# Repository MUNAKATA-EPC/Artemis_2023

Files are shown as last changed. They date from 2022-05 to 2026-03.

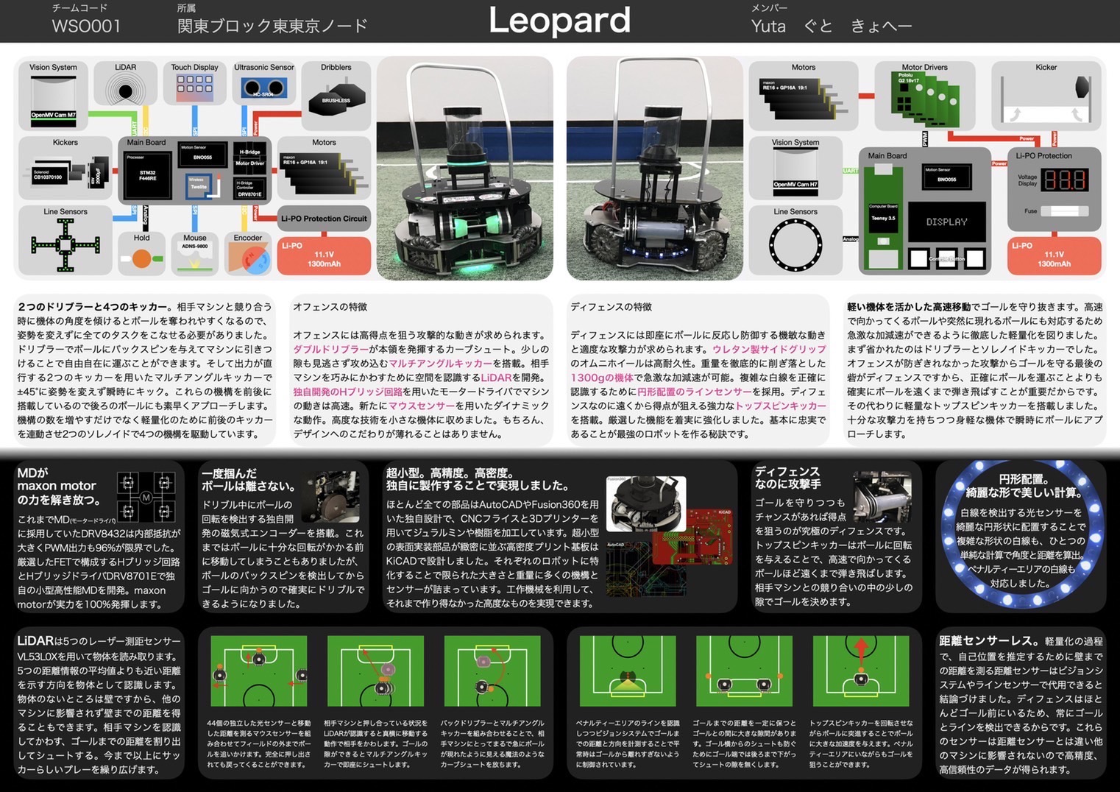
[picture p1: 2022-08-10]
Reference_Material/Presentation/leopard presentation.jpg

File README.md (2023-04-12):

# 宗中アルテミス
2023シーズンの宗中アルテミスのデータをまとめたリポジトリです。詳細はWikiの方で。

このReadmeでは軽く自チームの紹介がてら結果報告やロボット概要をまとめておきます。
詳しくはいつか出る全国大会の記事で。

## 今年の結果
>  福岡ノード 優勝  
>  九州ブロック 優勝 / 優秀プレゼンテーション賞受賞  
>  ジャパンオープン 最終結果 18位 / 優秀プレゼンテーション賞受賞  
> その他オープン大会優勝 etc...  

## 全国機ロボット概要
* メインマイコン：Teensy 4.0
* サブマイコン：ATMega2560(ボールセンサ、ラインセンサ処理用)、Seeeduino Xiao(ジャイロセンサ処理用)
* モータードライバ：DSR-1202
* モーター：ジョンミンモーター x4
* IRセンサー：16個(円形)
* ラインセンサー：S4282-51 x25 + LED
* ジャイロセンサー：MPU6050(used dmp)
* カメラ：OpenMV H7
* 電源：Lipo 3cell(11.1V, 1300mAh)

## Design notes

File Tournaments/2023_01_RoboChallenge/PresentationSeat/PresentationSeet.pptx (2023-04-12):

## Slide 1

Li-PO Battery
7.4V 2200mAh

宗中アルテミス

Main Board

チームメンバー

Vision System

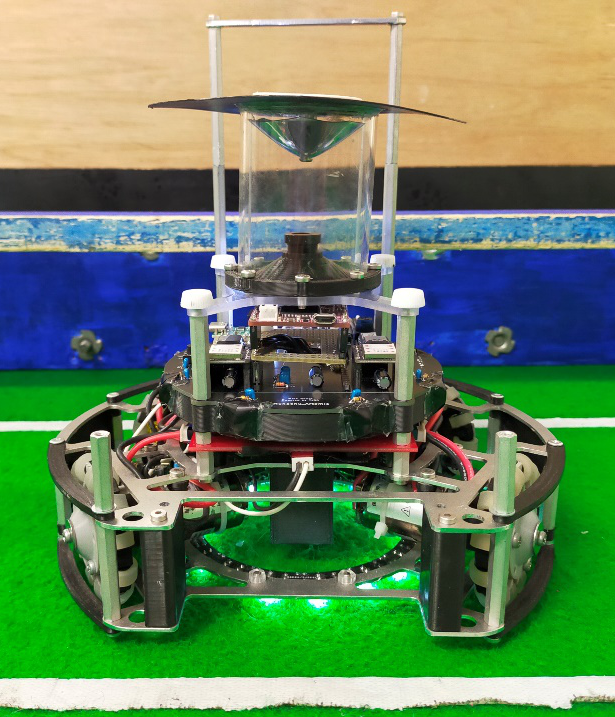
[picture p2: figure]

所属
九州ブロック福岡ノード

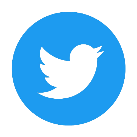
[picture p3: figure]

Li-PO Battery
7.4V 2200mAh

@munachu_artemis

Main Board

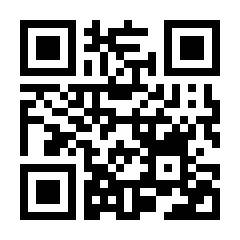
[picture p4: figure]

Our blog
https://asahi-rcj.github.io

Vision System

Power Supply Unit
Fuse : 20A

Power

Serial

Analog

Seeeduino Xiao

Analog

Processer

Analog

Seeeduino Xiao

Analog

PWM

Line ring

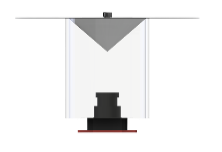
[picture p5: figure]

Open MV Cam H7

Power

Serial

Analog

Seeeduino Xiao

Analog

Processer

Analog

Seeeduino Xiao

Analog

PWM

Line ring

Open MV Cam H7

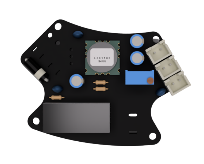
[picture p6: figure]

Power(5.5V)

Type-C Covert Module

Serial To Type-C

Gyro Sensor

IR Ring
TSSP58038 x 8

Analog

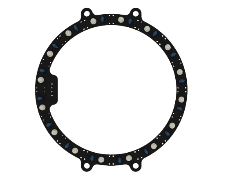
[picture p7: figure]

Power Supply Unit
Fuse : 20A

Power(5.5V)

Type-C Covert Module

Serial To Type-C

Gyro Sensor

IR Ring
TSSP58038 x 8

Analog

Power(7.4V)

4ch Motor Control Board
(DAISEN DSR-1202)

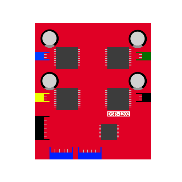
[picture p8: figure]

I²C

Power

Motor
JMP-BE-3561 x 4

Power(7.4V)

4ch Motor Control Board
(DAISEN DSR-1202)

I²C

Power

Motor
JMP-BE-3561 x 4

電源基盤
これまでは、電源を1つのバッテリーから取ると、
モータの電圧降下により、制御部分のリセットが
かかるという問題があったため、電源を制御用、
駆動用と2つに分ける必要がありました。
今年は、安定化にDCDCコンバータを
採用することで、1つの
バッテリーから電源を取って
もモータの電圧降下による
制御部分のリセットに対応
しました。これにより、
回路の簡易化、基板の
省スペース化を実現
しました。

カメラのライン制御
超音波センサーで壁との距離を測って
ライン制御をするという制御方法から、カメラを用いてライン制御をする方法に変更し、コートの中心方向に移動する
アルゴリズムを実装しました。常に
カメラでコートの中心を取り続け、
ロボットからコートの中心への角度を
算出することによってラインが反応
したときにコートの中心方向へ移動する
ことが可能になるだけでなく、
ラインにどの角度で乗っても
正確にコート内に移動することが可能になりました。

技術共有
私たちは、RoboCupJuniorに参加
する上で、技術の共有をすることは必要
不可欠であると考えました。そこで、
私たちでTwitterのアカウント、
ウェブブログを作成しました。
Twitterではロボットの進捗やチームメイトの独り言をつぶやいたり、他チームへの積極的な交流を行っています。
ブログでは、Twitterではまとめきれないような技術公開記事や、ロボットの詳細について、また大会の反省についても記事にまとめています。
ぜひ一度覗いてみてはいかがでしょうか。

Twitter:@munachu_artemis
Blog:
https://asahi-rcj.github.io

Sponsored by
金銭面で支援していただいております。
本当にありがとうございます！

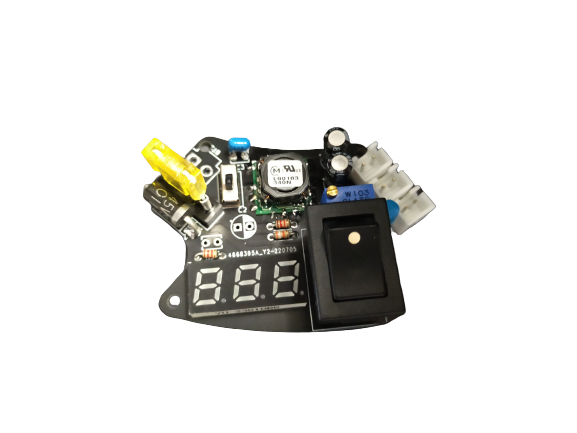
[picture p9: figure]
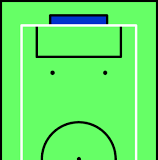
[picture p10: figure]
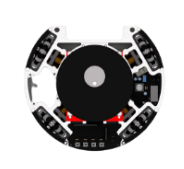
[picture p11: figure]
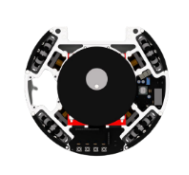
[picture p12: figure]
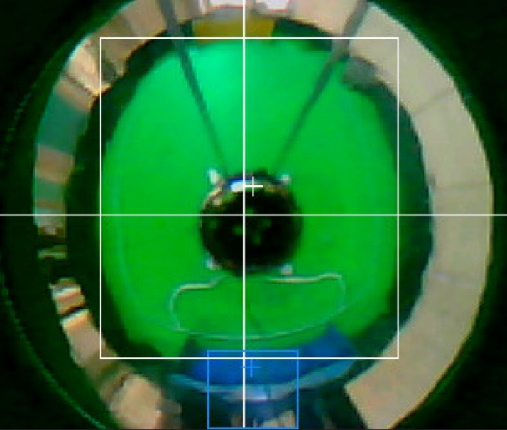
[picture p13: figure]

通過センサ
通過センサを用いることでロボットが
ボールを保持しているかを認識できるようになります。
このセンサはLEDと光変調をロボットのボール捕捉エリアの横に配置し、
光線を遮断したかを判断させることに
よって実現させることができました。
しかしながらこのセンサはこの大会では
活用することができませんでした。
福岡ノード大会以降、センサを有効活用し、
より良い動きができるよう調整していきたいと思います。

技術の駆使、そして最適化へ
Fusion360やKiCadを用いてほぼすべての部品を独自で
設計しています。また、3DプリンタやCNCを使用することで、
さらに正確に短時間での部品の製作、量産が可能になりました。
基板類も、発注基板によって自分たちのロボットに特化した
機能、形のものを実現可能になりました。また、チーム内での
ファイル共有のためにGitHubを用いることで、複数での
大規模プロジェクト開発が容易に行えるようになりました。
部品設計：Fusion360
基板設計：KiCad
基板発注：JLCPCB
部品製作：Originalmind kitmill CL100
FLASHFORGE Adventurer3 lite
基盤制作：Originalmind kitmill BS200

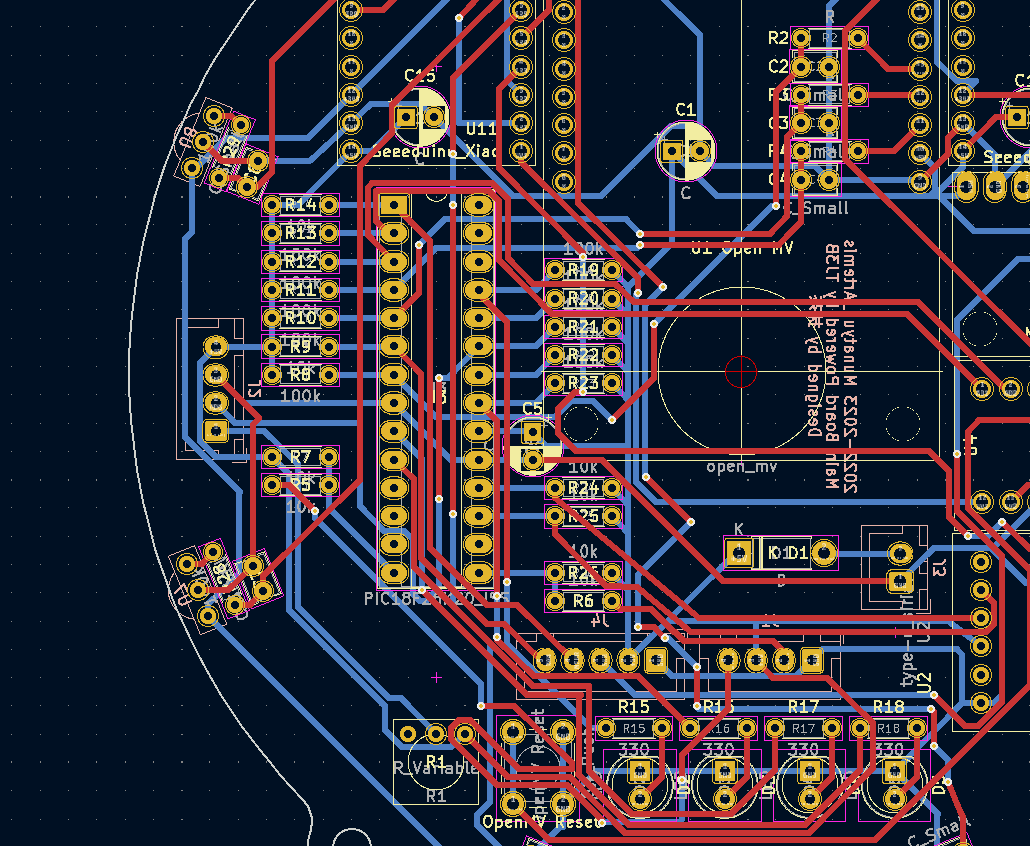
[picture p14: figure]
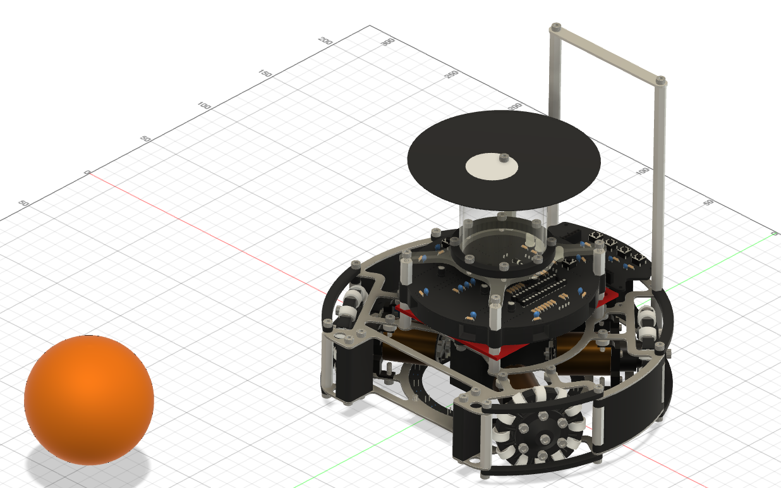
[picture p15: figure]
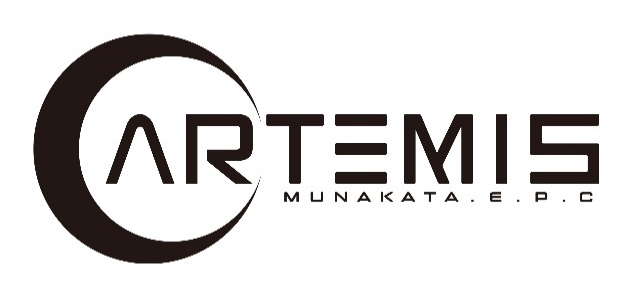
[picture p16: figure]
画像
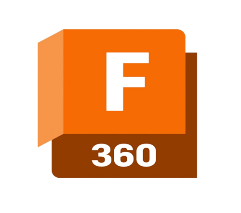
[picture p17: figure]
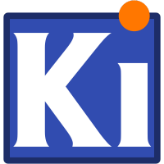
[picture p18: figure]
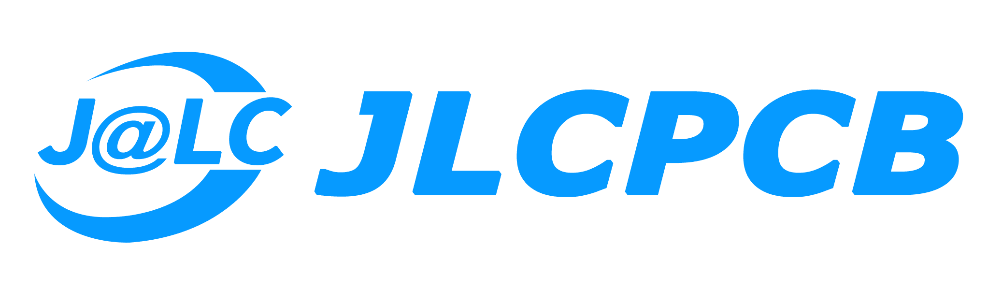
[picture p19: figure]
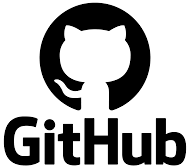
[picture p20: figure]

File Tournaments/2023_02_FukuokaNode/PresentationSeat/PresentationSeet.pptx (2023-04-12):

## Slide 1

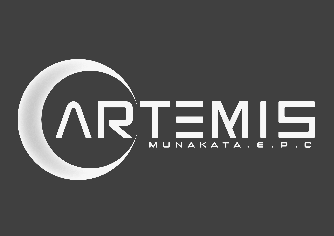
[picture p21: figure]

Li-PO Battery
7.4V 2200mAh

宗中アルテミス

Main Board

Type-C Covert Module

チームメンバー

Vision System

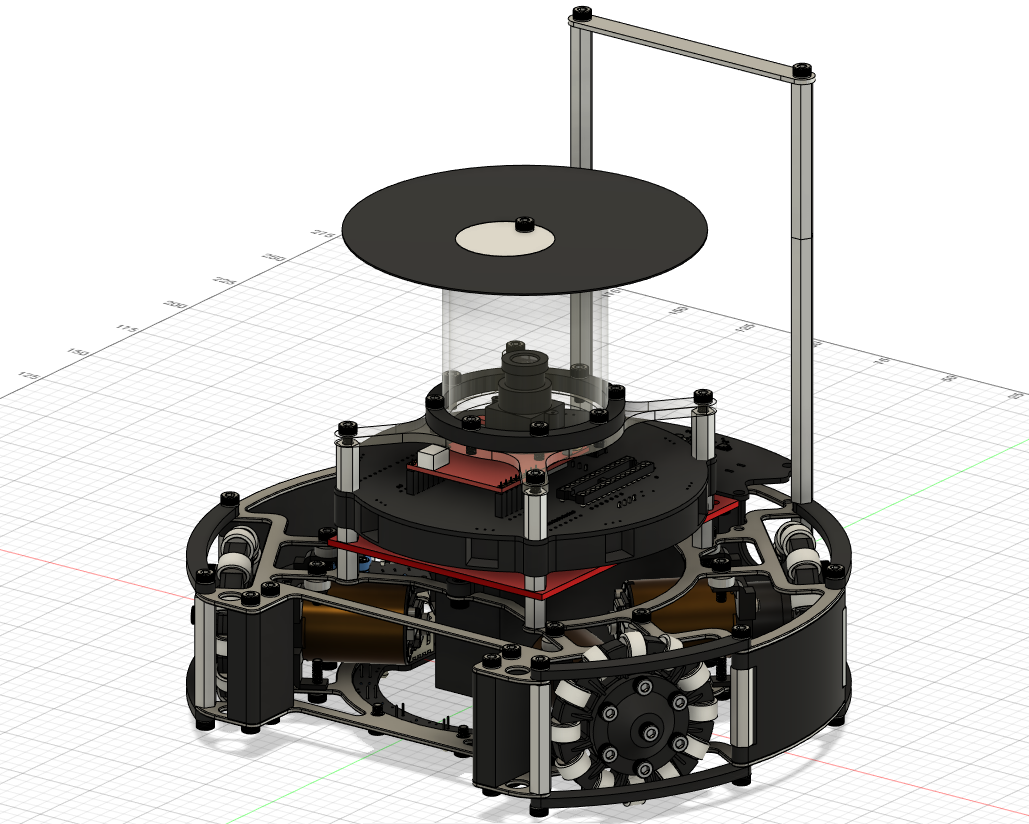
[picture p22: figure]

所属
九州ブロック福岡ノード

使用している主要部品とその理由
・メインマイコン：TJ3B Core
→ブロック式でプログラムを簡単に書くことができるため。
・サブマイコン：Seeduino Xiao×２
→比較的小さなマイコンであり、省スペース化、軽量化に最適だった。
今大会のロボットにはボール制御・ジャイロ制御用として使用。
・ボールセンサ： TSSP58038×８
→近距離、遠距離ともに使え、試合中にボールが見えない状況が
無くなったため。
・ラインセンサ： S4282-51×16
→周りの光に影響を受けずにラインを読み取ることができるため、
照明やロボットの影響による誤作動がないため。
・タッチセンサ：S4282-51×１
→比較的少ないLEDの光量でボールの補足を検知できたため。
・カメラ：Open MV Cam H7×１
→TJ3B Coreと組み合わせて使用するのに適していたため。

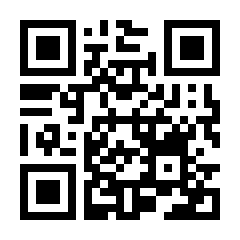
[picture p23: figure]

Our blog


@munachu_artemis

Power Supply Unit
Fuse : 20A
DC-DC:OKL-T/3W5NC

Power

Serial

Analog

Seeeduino Xiao

Analog

Processer

Analog

Seeeduino Xiao

Analog

PWM

Line ring
S4282-51 x 16


Open MV Cam H7

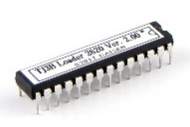
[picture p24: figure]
TJ3BLoader付 PICマイコン | ロボット,その他 | 株式会社ダイセン電子工業
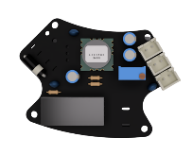
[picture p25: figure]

Power(5.0V)

Type-C to Serial

Gyro Sensor

IR Ring
TSSP58038 x 8

Analog

ソース画像を表示
Seeeduino Xiaoをはじめよう - Seeedウィキ（日本語版）

Power(7.4V)

4ch Motor Control Board
(DAISEN DSR-1202)


I²C

Power

Motor
JMP-BE-3561 x 4

Analog

Hold sensor
S4282-51 x 1
White LED x 1

ソース画像を表示

電源基盤
これまでは、電源を1つのバッテリーから取ると、
モータの電圧降下により、制御部分のリセットが
かかるという問題があったため、電源を制御用、
駆動用と2つに分ける必要がありました。
今年は、安定化にDCDCコンバータを
採用することで、1つのバッテリー
から電源を取ってもモータ
の電圧降下による制御部分
のリセットに対応しました。
これにより、回路の簡易化、
基板の省スペース化を実現
しました。

カメラによるライン制御
超音波センサーで壁との距離を測って
ライン制御をするという制御方法から、
カメラを用いてライン制御をする方法
に変更し、コートの中心方向に移動
するアルゴリズムを実装しました。
常にカメラでコートの中心を取り続け、
ロボットからコートの中心への角度を
算出することによってラインが反応し
たときにコートの中心方向へ移動する
ことが可能になるだけでなく、ライン
にどの角度で乗っても正確にコート内
に移動することが可能になりました。

技術の駆使、そして最適化へ
Fusion360やKiCadを用いてほぼすべての部品を独自で設計
しています。また、3DプリンタやCNCを使用することで、
さらに正確に短時間での部品の製作、量産が可能になりました。
基板も、発注基板によって自分たちのロボット
に特化した機能、形のものを実現可能になりました。

正確性を求めて
私たちはより正確な動きを実現するために、様々なことを行いました。 まず、ボールセンサを8つ円形に配置し、ベクトルの考え方を適用することで比較的少ないボールセンサで正確なボールの角度を出すことに成功しました。 また、その角度を三角関数を用いたモーター駆動関数に代入することで、カクカクせず滑らかに、そして最短距離でボールに到達することが可能となりました。


円形ライン
今年は、小サイズのラインセンサー数個から
センサー16個を円形に配置したものに変更。
円形することでどのような状態でもラインに
反応するようになりました。
前年からの課題である
「スピードが速すぎて
ラインから出る」
というのも解決し、
スピードを気にせずに
制御ができるように
なりました。

技術共有
私たちは、RoboCupJuniorに参加
する上で、技術の共有をすることは必要不可欠であると考え、Twitterのアカウント、ウェブブログを作成し、私たちが持っている技術を公開・共有することにしました。ハードウェア面、ソフトウェア面からの共有をすることも考えているため、ぜひ一度お越しください。

Twitter : @munachu_artemis
Blog : https://asahi-rcj.github.io

スポンサー
・JLCPCB様
発注基板の製作費や送料など、
金銭面でのサポートをしていただ
ています。
・佐賀大deラボ様
3Dプリンタ、レーザーカッター
など　の機械を使用させていただく
だけでなく、技術交流の場としても
利用させていただいてます。


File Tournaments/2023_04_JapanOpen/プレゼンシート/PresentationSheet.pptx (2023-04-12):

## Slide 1

チームメンバー

所属

九州ブロック 福岡ノード


@munachu_artemis

ボールセンサ：TSSP58038

ボールセンサにはTSSP58038を
一機当たり16個搭載しています。
ボールから発せられる赤外線を
読み取り、サブマイコンで角度と
距離を計算しています。入手性の高さや
扱いやすさからこちらを使用しています。
複数個載せることでボールの正確な場所の
取得も可能にしました。


BLOG

ロボットの概要


Li-PO Battery
11.2V 1300mAh

Main Board

メインマイコン
Teensy 4.0

CPUのアイコン04素材 | 無料のアイコンイラスト集 icon-pit

Kicking
System

サブマイコン
Arduino
Mega 2560

Serial

Analog

ジャイロセンサ

MPU6050

Vision System

OpenMV H7


サブマイコン：ATmega2560

ボールセンサ・ジャイロセンサ、
ラインセンサの処理にATmega2560を
採用しました。センサーの値の読み取りや、
動作に必要な計算を行っています。
その他のマイコンと比べ、ピン数が多く、
汎用性が高いため、このマイコンを
採用しました。省スペース化のために
回路を自作しています。

Atmega2560-au 8-ビットmicrocontroller Atmega2560 Flash Atmega 2560電気アイテムリスト - Buy Atmega2560 、atmega 2560 、電気アイテムリスト Product on Alibaba.com

メインマイコン：Teensy 4.0

モーター制御や画面表示などの、
ロボット制御を行っています。
以前まではTJ3B Loaderを
使用していましたが、入出力ピン数
の多さや、処理性能の高さから
こちらを採用しました。

Power Supply Unit


Fuse:20A
DC-DC:
OKL-T/3W5NC

PWR

Analog

ボールセンサ

TSSP58038 x 16

Serial

Line Ring

Arduino
Mega 2560

サブマイコン

analog

analog

Line Sensor

ラインセンサ：S4282-51

ラインセンサにはS4282-51(光変調フォト
IC)を一機あたり25個搭載しています。
コート上の白線の読み取りを行っています。
外部からの光に影響を受けないため、
誤作動が起こりにくく扱いやすいので、
こちらを使用しています。また、複数個の
搭載により、ロボットがどの位置の白線を
踏んでいるのかの取得を可能にしました。

PWR

PWR / 12V

PWR / 5.0V

PWR / 3.3V

Digital

FET

Digital

FET

ソレノイド
キッカー

Serial

CPUのアイコン04素材 | 無料のアイコンイラスト集 icon-pit

analog

analog

カメラ：OpenMV H7

ゴール・コートの角度・距離を
計算しています。プログラムの
しやすさや、入手性の高さ、
他マイコンとの通信のしやすさ
からこのカメラを採用しました。

Cam OpenMV H7 R2, Køb her 982,50

ジャイロセンサ：MPU6050

最初に向いていた方向から
どのくらい角度がずれているのか
計算し、ロボットの姿勢制御に
利用しています。今まで利用していた
センサよりもずれが小さく、エラーが
少ないためこのセンサを採用しました。

光変調型フォトＩＣ Ｓ４２８２－５１: センサ一般 秋月電子通商-電子部品・ネット通販

MOTOR

DAISEN DSR-1202


JMP-BE-3561 x 4

PWR

昇圧回路
12V → 48V

48V

C
4700
μF

…

…

…

…

アナログ体育館センサー,3軸ダイヤルモジュール,GY 521 m pu6050,MPU 6050|gyro sensor|sensors accelerometerssensor sensor - AliExpress

より早く、より正確にーラインセンサの改良
コート上の白線を認識する
ラインセンサは、円形+十字に配置
したものに改良しました。以前
よりもセンサーが外側に伸びたため、
早くラインに反応することができる
ようになりました。また、反応した
位置から角度と距離を求め、条件を
分けることで最適な制御ができる
ようになり、ルール改定による
白線外の空間の縮小にも対応する
ことができました。

今季から、ソレノイドキッカーを用いたキック機構を搭載しました。
キック機構を載せることで、ロボットが直接ボールを運ぶよりも
強い力でシュートすることができます。
キック機構を用いることで、自分のロボットとボールを離して
シュートできるため、ゴールに入る前に相手ロボットと接触していてもプッシングを取られず、必然的にゴールに入る回数が増えることになります。また、キック機構と他の機能を一緒に用いることで、より強力なシュートを打つことができます。例えば、カメラを用いてゴールの方向を向きながらボールをキックすることで、前を向いてキックするよりもはるかにゴールへのシュート率を上げることができます。また、自陣を守るロボットであっても、前方にボールをキックすることができるため、アタック・ディフェンス両方の機能を兼ね備えた強いロボットを作ることができます。

蹴り一つで状況を変えるーソレノイドキッカーの搭載

<電圧・コンデンサの容量とキックパワーの関係>
ソレノイドキッカーは、かける電圧とコンデンサの容量によってキック
パワーが変化します。そこで、どの電圧をかけ、どのコンデンサを搭載することでより長距離にボールをキックできるのかという実験を行いました。

モータのスピードと制動距離の関係
2023ルールから、コートの白線外の場所が狭くなり、ラインアウト判定が「壁に触れたとき」に変更
されたため、必然的にラインで正確に止まる必要が出てきました。しかし、僕たちのロボットは
「速く、正確に」を目指しており、正確さをとるために速さを犠牲にしたくないので、速さ・正確さを
両立させるギリギリを探す必要がありました。そこで、モータのスピードによってどのくらい白線の外に出てしまうのか、という実験を行いました。
＜実験＞
1)白線からそれぞれ820mm、320mm離れた位置にロボットを静止させる。
2)一定のモータースピードでロボットを助走させる。
3)白線を踏んだ時点でモーターにブレーキをかけ、
白線からはみ出た距離を計測する。
4)モータースピードを変化させて同様に実験する。
＜結果・考察＞

青：助走820mm 赤：助走320mm


(mm)

左上図より、コンデンサの
容量を220μF～4700μFで
変化させた時、距離がほぼ
一次関数的に伸びていくことがわかりました。
また、左下図より、電圧を
15V～40Vで変化させた時も
同様に、ほぼ一次関数的に
変化していることが
わかりました。
このような結果から、コンデンサの容量を大きく、電圧を高く
することで威力を高められることがわかりました。そのため、僕たちのロボットでは、コンデンサの容量を、ロボットに
載せることのできる最大サイズの4700μFに、電圧を45Vに
設定しています。

コート、ゴール、そして先を見る
僕たちのロボットにはOpenMV H7というカメラを搭載して
います。このカメラを用いて、コートの中心の位置、青・黄ゴールの位置を取得しています。これらのデータを用いることで、
現在自分がコートの中心からどのくらいの角度・距離にいるのかを知ることができたり、常に相手のゴールの方向を見ながらボールを運ぶことを可能にしました。カメラを使うことで、リアルタイムで常にコートの状況を知ることができるため、たとえロボットがゴールの一部を隠したとしても、空いている方向にロボットを傾けてシュートすることができます。
また、ディフェンス機では、自陣のゴールの位置を取得する
ことで、相手ロボットから自陣を守るという行動をとれるように
なりました。

当たっているがセーフ

キックすることでプッシングとなることなく
得点を取ることができる

(mm)

ライン上でブレーキ

この長さを計測する
(制動距離)

助走距離(820mm/320mm)

左のグラフのような結果となりました。
ライン外空間の幅は120mmであるため、
このグラフから見ると、助走が長いときは30%程度、助走が短いときは50%程度でモータを動かせばよいことがわかり
ました。しかし、この実験では、移動開始時は停止しているため、実際の試合では
慣性によって、同じモータースピードでもラインアウトする可能性があります。そのため、この結果を参考にしつつ、どのような処理をすればラインアウトをしない
ギリギリで停止できるのかを調整していく必要があります。

今までプッシングを取られていたシーンも…

プッシング

キック機構
搭載後…

(mm)

駆使するツールはそれだけにとどまりません。例えば、SNSは
新しい技術や情報を身に着ける重要なツールの一つです。
僕たちは、RCJに参加するうえで、技術の共有をしていくことは
必要不可欠であると考えています。そのため、Twitterのアカウント、
チームのウェブサイトを作成し、私たちが持っている技術の公開・共有
を行っています。プレゼンシート右上にTwitterのユーザー名と
ブログのQRコードを掲示しているので、ぜひ一度お訪ねください。

(μF)

ツールを駆使するー様々なサービスの利用

ロボット製作をスムーズに行うため、様々なツールを駆使して活動を
行っています。例えば、ロボットの設計を早く、正確に行うために、
Fusion360(機体設計) や、KiCad(回路設計)などのソフトを
活用しています。ロボットの設計以外にも、チーム内で「今自分が
何をすべきなのか」、「まだどのタスクが終わってないのか」を
はっきりさせるために、「Asana」というツールを利用しタスクの
明確化のみならず、日程の管理や情報伝達にも活用し、チーム内
での活動を円滑に進めています。また、Githubなどのデータ共有
サービスを利用し、チーム内での最新の進捗を常に素早く共有
しています。これらのおかげで、わずかな活動時間でも大きな進捗
を生み出せています。

(V)

モータースピード

(%)

何もないと入らないこのシュートも…

カメラ
搭載後…

カメラでゴールの角度を計算することで
ゴールに向かってシュートすることができる

スポンサー
僕たちがロボット製作をしていくうえで、金銭面や技術面からサポートしていただいております。この場を借りてお礼申し上げます。
JLCPCB 様
基板の発注に際する発注費用や送料などの面でサポートをしていただいております。
佐賀大deラボ 様
3Dプリンタ、レーザーカッターなどの機械を利用させてもらうだけでなく、技術交流の場としても活用させていただいております。

チームの仕事、プロジェクト、タスクをオンライン管理 • Asana

WSL-043

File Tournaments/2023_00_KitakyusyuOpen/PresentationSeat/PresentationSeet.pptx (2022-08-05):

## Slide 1

宗中アルテミス


Li-PO Battery
7.4V 2200mAh

チームメンバー

Main Board

熊抱 崚太 / 石原 廉太郎 / 松田 魁琉 / 目野 優輝

カメラのライン制御
超音波センサーで壁との距離を測って
ライン制御をするという制御方法から、カメラを用いてライン制御をする方法に変更し、コートの中心方向に移動する
アルゴリズムを実装しました。常に
カメラでコートの中心を取り続け、
ロボットからコートの中心への角度を
算出することによってラインが反応
したときにコートの中心方向へ移動する
ことが可能になるだけでなく、
ラインにどの角度で乗っても
正確にコート内に移動することが可能になりました。

Vision System

所属
九州ブロック福岡ノード


Dry cell

1.5V x 4 x 2 = 12V


Dry cell

@munachu_artemis

9V


Power

Serial

Analog

Seeeduino Xiao

Analog

Processer

Analog

Seeeduino Xiao

Analog

PWM

Line ring


Open MV Cam H7

Power

Main Board

Processer

Power

Analog

Analog

LINE Sensor x 4

Ultra Sonic Sensor x 4

Power Supply Unit
Fuse : 20A


Power(5.5V)

Type-C Covert Module

Serial To Type-C

Gyro Sensor

IR Ring
TSSP58038 x 8

Analog


I²C

I²C

Processer

Slave

Analog

IR Sensor x 6

I²C

Power(7.4V)

4ch Motor Control Board
(DAISEN DSR-1202)


I²C

Power

Motor
JMP-BE-3561 x 4

6ch Motor Control Board
(DAISEN DSR-1203)


Power

DAISEN MOTOR x 4

Analog

Gyro Sensor

L3GD20H

Seeeduino
Xiao

電源基盤
これまでは、電源を1つのバッテリーから取ると、
モータの電圧降下により、制御部分のリセットが
かかるという問題があったため、電源を制御用、
駆動用と2つに分ける必要がありました。
今年は、安定化にDCDCコンバータを
採用することで、1つの
バッテリーから電源を取って
もモータの電圧降下による
制御部分のリセットに対応
しました。これにより、
回路の簡易化、基板の
省スペース化を実現
しました。

ボールセンサの制御
今まではボールセンサーをすべて
メインマイコンに接続し、反応したものの組み合わせで移動方向を判断する制御方法を使用してきました。今シーズンからボールセンサーを一度別マイコンに接続し、各ボールセンサの反応値から
ボールの角度を算出・出力し、
それをもとに移動する制御方法に変更しました。センサーの数を
以前より追加したことで、より
正確なボールの位置の把握、回り込みができるようになりました。


円形ライン
今年は、小サイズのラインセンサー数個から、センサー16個を円形に配置したものに変更。円形することでどのような状態でもラインに
反応するようになり
ました。前年からの
課題の「スピードが
速すぎてラインから
出る」というのも
解決し、スピードを
気にせずに制御が
できるように
なりました。

技術の駆使、そして最適化へ
Fusion360やKiCadを用いてほぼすべての部品を独自で
設計しています。また、3DプリンタやCNCを使用することで、
さらに正確に短時間での部品の製作、量産が可能になりました。
基板類も、発注基板によって自分たちのロボットに特化した
機能、形のものを実現可能になりました。また、チーム内での
ファイル共有のためにGithubを用いることで、複数での
大規模プロジェクト開発が容易に行えるようになりました。
部品設計：Fusion360
基板設計：KiCad
基板発注：JLCPCB
部品製作：Originalmind kitmill CL100
FLASHFORGE Adventurer3 lite
基盤制作：Originalmind kitmill BS200


技術共有
私たちは、RoboCupJuniorに参加
する上で、技術の共有をすることは必要
不可欠であると考えました。そこで、
私たちでTwitterのアカウント、
ウェブブログを作成し、私たちが
持っている技術を公開・共有することで
チームの力を伸ばすことができます。
ロボットのハードウェア面、ソフト
ウェア面からの共有をすることも考えて
いるため、ぜひ一度お越しください。

Twitter:@munachu_artemis
Blog:https://asahi-rcj.github.io


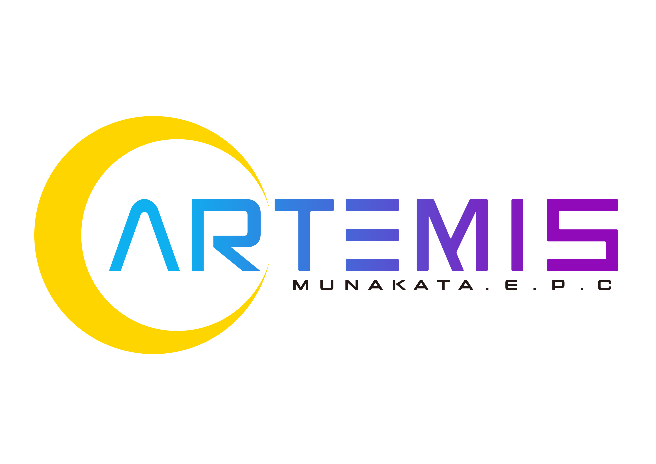
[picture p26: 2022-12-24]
Design/artemis_pic/artemis_text2.png

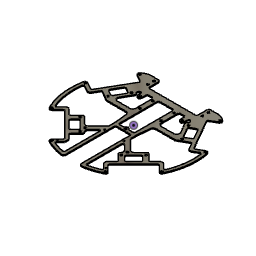
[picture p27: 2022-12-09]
Design/2022 late/ver.Teensy/Frame/上板 v2.png

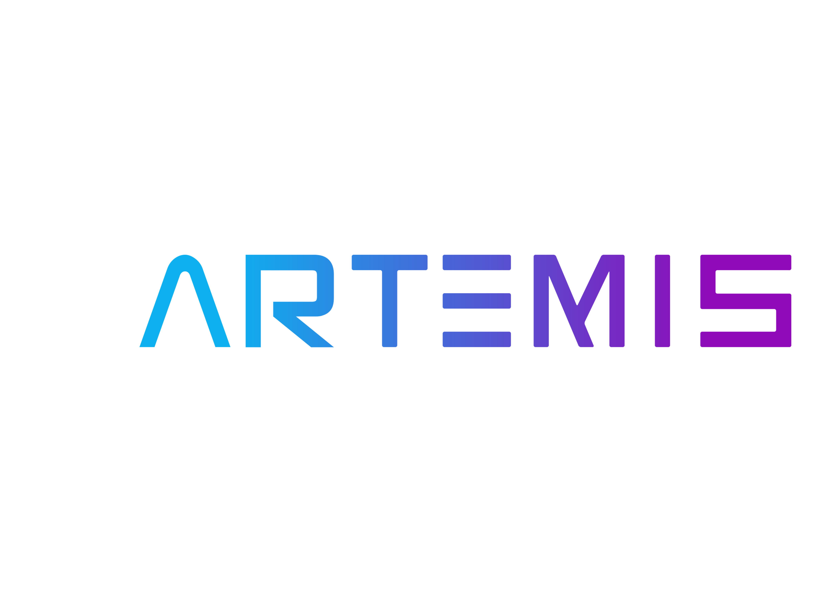
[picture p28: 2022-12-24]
Design/artemis_pic/text1.png

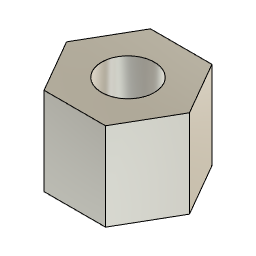
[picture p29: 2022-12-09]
Design/2022 early/screw nut spacer/5mmスペーサー .png

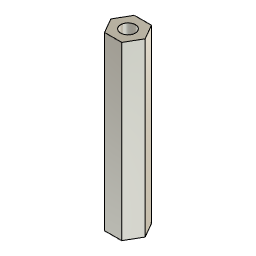
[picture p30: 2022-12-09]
Design/2022 early/screw nut spacer/35mmスペーサー .png

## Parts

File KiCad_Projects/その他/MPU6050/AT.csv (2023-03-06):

Comment | Designator | Footprint | LCSC
C_Small | C1,C3,C4,C5,C6,C7 | Capacitor_SMD:C_0603_1608Metric | C152896
C_Small | C2 | Capacitor_Tantalum_SMD:CP_EIA-3216-10_Kemet-I | C7171
LED | D1 | LED_SMD:LED_0603_1608Metric | C434420
Conn_01x08 | J1 | Connector_PinHeader_2.54mm:PinHeader_1x08_P2.54mm_Vertical
R_Small | R1,R2,R3,R4 | Resistor_SMD:R_0603_1608Metric | C21190
TLV713185PDBV | U1 | Package_TO_SOT_SMD:SOT-23-5 | C26833
MPU-6050 | U2 | Sensor_Motion:InvenSense_QFN-24_4x4mm_P0.5mm | C24112

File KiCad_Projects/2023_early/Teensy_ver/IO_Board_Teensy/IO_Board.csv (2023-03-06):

Comment | Designator | Footprint | LCSC
C_Small | C3,C4,C5,C6,C7,C8,C10,C11,C12 | Capacitor_SMD:C_0402_1005Metric | C167339
Ferrite_Bead | FB1,FB2 | Fuse:Fuse_0805_2012Metric | C16903
USB_C_Receptacle_USB2.0 | J1,J2,J4,J7 | Connector_USB:USB_C_Receptacle_XKB_U262-16XN-4BVC11 | C2760486
Conn_01x10_Female | J3,J5 | Connector_PinHeader_2.54mm:PinHeader_1x10_P2.54mm_Vertical
Conn_01x17_Female | J6 | katamura1:LCDmodule_aqm1248a
10K | R1,R4 | Resistor_SMD:R_0402_1005Metric | C25744
R | R2,R3,R6,R7,R8,R9,R12,R13 | Resistor_SMD:R_0402_1005Metric | C25905
22R | R5,R10,R11,R14 | Resistor_SMD:R_0402_1005Metric | C25092
SW_DIP_x01 | SW1,SW2,SW3,SW4 | Button_Switch_THT:SW_PUSH_6mm_H5mm

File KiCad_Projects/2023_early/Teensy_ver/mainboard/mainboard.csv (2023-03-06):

Comment | Designator | Footprint | LCSC
Buzzer | BZ1 | Buzzer_Beeper:Buzzer_12x9.5RM7.6
C | C1,C2 | Capacitor_SMD:C_0402_1005Metric | C1555
1uF | C11 | Capacitor_SMD:C_0402_1005Metric | C167339
104 | C12,C13,C14,C15,C16,C17,C18,C19,C21,C22,C23,C24,C25,C26,C27,C28 | Capacitor_SMD:C_0402_1005Metric | C1525
100nF | C3,C5,C6,C7,C8,C20,C29 | Capacitor_SMD:C_0402_1005Metric | C41851
C_Small | C30,C31,C35,C36 | Capacitor_SMD:C_0603_1608Metric | C57112
C_Small | C32,C33,C34,C37,C38,C39,C40,C41,C42,C43,C44,C45,C46,C47,C48,C49 | Capacitor_SMD:C_0402_1005Metric | C1525
22pF | C4,C9,C10 | Capacitor_SMD:C_0402_1005Metric | C1555
LED | D1,D2,D3,D4 | LED_SMD:LED_0402_1005Metric | C130725
D | D20,D21 | Diode_THT:D_A-405_P7.62mm_Horizontal
WS2812B | D5,D6,D7,D8,D9,D10,D11,D12,D13,D14,D15,D16,D17,D18,D19,D22 | LED_SMD:LED_WS2812B_PLCC4_5.0x5.0mm_P3.2mm | C2761795
Conn_01x04_Female | J1,J2 | Connector_PinSocket_2.54mm:PinSocket_1x04_P2.54mm_Vertical
Conn_01x04_Female | J10 | Connector_JST:JST_XH_B4B-XH-A_1x04_P2.50mm_Vertical
Conn_01x03_Female | J11,J12 | Connector_JST:JST_XH_B3B-XH-A_1x03_P2.50mm_Vertical
Conn_01x06_Female | J3,J5 | Connector_JST:JST_XH_B6B-XH-A_1x06_P2.50mm_Vertical
Conn_01x10_Female | J4 | Connector_PinHeader_2.54mm:PinHeader_1x10_P2.54mm_Vertical
Conn_01x10_Female | J6 | Connector_PinSocket_2.54mm:PinSocket_1x10_P2.54mm_Vertical
Conn_01x03_Female | J7 | Connector_PinSocket_2.54mm:PinSocket_1x03_P2.54mm_Vertical
Conn_01x08_Female | J8 | Connector_PinSocket_2.54mm:PinSocket_1x08_P2.54mm_Vertical
Conn_01x02_Female | J9 | Connector_JST:JST_XH_B2B-XH-A_1x02_P2.50mm_Vertical
Q_NJFET_GDS | Q1,Q2 | Lib:MSKSEMI
10k | R1,R2,R3,R31,R32 | Resistor_SMD:R_0402_1005Metric | C25744
1k | R21,R22,R23,R30,R33,R35,R36 | Resistor_SMD:R_0402_1005Metric | C105637
R_Trim | R24,R34 | 可変抵抗:可変抵抗(小)
R_Small | R25,R26,R27 | Resistor_SMD:R_0603_1608Metric | C4190
100 | R28,R29 | Resistor_SMD:R_0402_1005Metric | C25076
10K | R4 | Resistor_SMD:R_0402_1005Metric | C25744
100K | R5,R6,R7,R8,R9,R10,R11,R12,R13,R14,R15,R16,R17,R18,R19,R20 | Resistor_SMD:R_0402_1005Metric | C25741
SW_MEC_5G | SW1,SW2 | Button_Switch_THT:SW_PUSH_6mm
SW_DIP_x01 | SW3 | Lib:2MS1T2B4M2QES
SW_DIP_x01 | SW4,SW5,SW6 | Button_Switch_THT:SW_PUSH_6mm_H5mm
ATmega2560-16AU | U1 | Package_QFP:TQFP-100_14x14mm_P0.5mm
ATmega16U2-MU | U10 | Package_DFN_QFN:QFN-32-1EP_5x5mm_P0.5mm_EP3.1x3.1mm
open_mv | U19 | Lib:OpenMV
TSSP58038 | U2,U3,U4,U5,U6,U7,U8,U9,U11,U12,U13,U14,U15,U16,U17,U18 | Lib:TSSP58038_IR
MPU-6050 | U20 | Sensor_Motion:InvenSense_QFN-24_4x4mm_P0.5mm | C24112
Teensy4.0 | U21 | Lib:Teensy_Brakeout
Crystal | Y1,Y2 | Crystal:Crystal_SMD_3225-4Pin_3.2x2.5mm | C164049

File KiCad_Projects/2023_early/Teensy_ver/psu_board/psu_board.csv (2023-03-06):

Comment | Designator | Footprint | LCSC
Battery | BT1 | Connector_JST:JST_VH_B2P-VH-B_1x02_P3.96mm_Vertical
22μF | C1 | Capacitor_THT:C_Disc_D5.1mm_W3.2mm_P5.00mm
10μF | C2 | Capacitor_THT:C_Disc_D5.1mm_W3.2mm_P5.00mm
0.33μF | C3 | Capacitor_THT:C_Disc_D3.0mm_W1.6mm_P2.50mm
33μF | C4 | Capacitor_THT:C_Radial_D6.3mm_H11.0mm_P2.50mm
D_Shockley | D1 | Diode_THT:D_5W_P12.70mm_Horizontal
Fuse | F1 | Lib:fuse_socket
Conn_01x02_Female | J1,J2 | Connector_JST:JST_XH_B2B-XH-A_1x02_P2.50mm_Vertical
Conn_01x03_Female | J3 | Connector_JST:JST_XH_B3B-XH-A_1x03_P2.50mm_Vertical
Voltmeter_DC | MES1 | Lib:voltage_counter
20K | R1 | Resistor_THT:R_Axial_DIN0204_L3.6mm_D1.6mm_P5.08mm_Horizontal
1.2k | R2 | Resistor_THT:R_Axial_DIN0204_L3.6mm_D1.6mm_P5.08mm_Horizontal
R_Potentiometer_Trim_US | RV1 | Potentiometer_THT:Potentiometer_Bourns_3296W_Vertical
SW_DIP_x01 | SW1 | Lib:DS-850k
SW_DIP_x01 | SW2 | Lib:2MS1T2B4M2QES
OKL-T_6-W12N-C | U1 | Lib:DCDC-murata-6A
TA48033S | U2 | Lib:TA48033S

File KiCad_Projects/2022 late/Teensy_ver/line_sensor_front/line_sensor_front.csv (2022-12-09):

Comment | Designator | Footprint | LCSC
C_Small | C1,C2,C3,C4,C5,C6,C7 | Capacitor_SMD:C_0402_1005Metric | C507422
LED | D1,D2,D3,D4,D5,D6,D7 | LED_THT:LED_D3.0mm_Clear
Conn_01x04_Female | J1 | Connector_PinHeader_2.54mm:PinHeader_1x04_P2.54mm_Horizontal
Line_sennsor | U1,U2,U3,U4,U5,U6,U7 | Line_sennsor:Line_sennsor

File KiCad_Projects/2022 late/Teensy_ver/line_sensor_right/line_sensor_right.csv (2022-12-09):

Comment | Designator | Footprint | LCSC
C_Small | C1,C2,C3,C4,C5,C6,C7 | Capacitor_SMD:C_0402_1005Metric | C507422
LED | D1,D2,D3,D4,D5,D6,D7 | LED_THT:LED_D3.0mm_Clear
Conn_01x05_Female | J1 | Connector_PinHeader_2.54mm:PinHeader_1x05_P2.54mm_Horizontal
Line_sennsor | U1,U2,U3,U4,U5,U6,U7 | Line_sennsor:Line_sennsor

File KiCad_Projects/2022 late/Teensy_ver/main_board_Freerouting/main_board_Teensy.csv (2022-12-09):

Comment | Designator | Footprint | LCSC
Buzzer | BZ1 | Buzzer_Beeper:Buzzer_12x9.5RM7.6
22pf | C1,C2,C17,C18 | Capacitor_SMD:C_0402_1005Metric | C1555
C | C3,C29,C30 | Capacitor_SMD:C_0402_1005Metric | C507422
C_Small | C4,C5,C6,C8,C9,C10,C11,C12,C13,C14,C15,C16,C19,C20,C21,C23,C24,C25,C26,C27,C28,C31,C32,C33,C34 | Capacitor_SMD:C_0402_1005Metric | C507422
1uf | C7,C22 | Capacitor_SMD:C_0402_1005Metric | C52923
WS2812B | D1,D2,D3,D4,D5,D6,D7,D8,D9,D10,D11,D12,D19,D20,D21,D22 | LED_SMD:LED_WS2812B_PLCC4_5.0x5.0mm_P3.2mm | C2761795
LED | D13,D14,D15,D16,D17,D18 | LED_SMD:LED_0402_1005Metric | C130725
D | D23 | Diode_THT:D_A-405_P7.62mm_Horizontal
Conn_01x10_Female | J1,J4,J7 | Connector_PinHeader_2.54mm:PinHeader_1x10_P2.54mm_Vertical
Conn_01x10_Female | J2 | Connector_JST:JST_XH_S10B-XH-A-1_1x10_P2.50mm_Horizontal
Conn_01x04_Female | J3 | Connector_PinHeader_2.54mm:PinHeader_1x04_P2.54mm_Vertical
Conn_01x03_Female | J5 | Connector_JST:JST_XH_B3B-XH-A_1x03_P2.50mm_Vertical
Conn_01x02_Female | J6,J9 | Connector_JST:JST_XH_B2B-XH-A_1x02_P2.50mm_Vertical
Conn_01x04_Female | J8 | Connector_JST:JST_XH_B4B-XH-A_1x04_P2.50mm_Vertical
10K | R1,R18,R19 | Resistor_SMD:R_0402_1005Metric | C269674
R_Trim | R12,R13 | 可変抵抗:可変抵抗(小)
100k | R14,R15,R16,R17,R20,R21,R22,R23 | Resistor_SMD:R_0402_1005Metric | C269673
22 | R2,R3,R10,R11 | Resistor_SMD:R_0402_1005Metric | C25092
1k | R4,R5,R6,R7,R8,R9 | Resistor_SMD:R_0402_1005Metric | C11702
SW_DIP_x01 | SW1,SW4 | Lib:2MS1T2B4M2QES
SW_DIP_x01 | SW2,SW9,SW10,SW11 | Button_Switch_THT:SW_PUSH_6mm_H5mm
Akizuki_Logiv_Level_converter | U1,U4 | Lib:Akizuki_Logic_Level_converter
ATmega32U4-MU | U2,U5 | Package_DFN_QFN:QFN-44-1EP_7x7mm_P0.5mm_EP5.2x5.2mm | C112161
MPU6050 | U3 | Lib:MPU6050
open_mv | U6 | Lib:OpenMV
Teensy4.0 | U7 | Lib:Teensy_Brakeout
TSSP58038 | U8,U9,U10,U11,U12,U13,U14,U15 | Lib:TSSP58038_IR
16MHz | Y1,Y2 | Crystal:Crystal_SMD_3225-4Pin_3.2x2.5mm | C164049

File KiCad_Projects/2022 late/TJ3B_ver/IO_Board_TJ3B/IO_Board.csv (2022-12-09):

Comment | Designator | Footprint | LCSC
C_Small | C1,C2,C3 | Capacitor_SMD:C_01005_0402Metric | C194427
LED | D1,D2 | LED_SMD:LED_0402_1005Metric | C130725
Fuse | F1 | Fuse:Fuse_0603_1608Metric | C116602
USB_C_Receptacle_USB2.0 | J1 | Connector_USB:USB_C_Receptacle_XKB_U262-16XN-4BVC11 | C2760486
Conn_01x06_Female | J2 | Connector_JST:JST_XH_B6B-XH-A_1x06_P2.50mm_Vertical
Conn_01x02_Female | J3 | Connector_JST:JST_XH_B2B-XH-A_1x02_P2.50mm_Vertical
R | R1,R2,R4 | Resistor_SMD:R_0402_1005Metric | C159886
R | R3 | Resistor_SMD:R_0603_1608Metric | C105428
SW_Push | SW1,SW2 | Button_Switch_THT:SW_PUSH_6mm_H5mm
SW_DIP_x01 | SW3 | Lib:DS-850k
CH340E | U1 | Package_SO:MSOP-10_3x3mm_P0.5mm | C99652

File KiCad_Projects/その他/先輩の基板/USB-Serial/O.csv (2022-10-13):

Comment | Designator | Footprint | LCSC
C_Small | C1 | Capacitor_SMD:C_0603_1608Metric | C194427
C_Small | C2,C3 | Capacitor_SMD:C_0805_2012Metric | C126469
LED | D1,D2 | LED_SMD:LED_0603_1608Metric | C84263
Fuse | F1 | Fuse:Fuse_0603_1608Metric | C116602
USB_C_Receptacle_USB2.0 | J1 | Connector_USB:USB_C_Receptacle_XKB_U262-16XN-4BVC11 | C2760486
Conn_01x05 | J2 | Connector_JST:JST_XH_S5B-XH-A_1x05_P2.50mm_Horizontal
R | R1,R2,R4 | Resistor_SMD:R_0402_1005Metric | C25905
R | R3 | Resistor_SMD:R_0603_1608Metric | C105428
CH340E | U1 | Package_SO:MSOP-10_3x3mm_P0.5mm | C99652

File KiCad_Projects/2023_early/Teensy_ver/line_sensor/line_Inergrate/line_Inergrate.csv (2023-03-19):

Comment | Designator | Footprint | LCSC
C | C1,C2 | Capacitor_SMD:C_0402_1005Metric | C1555
1uF | C10 | Capacitor_SMD:C_0402_1005Metric | C167339
100nF | C3,C4,C5,C6,C13,C14,C15 | Capacitor_SMD:C_0402_1005Metric | C41851
22pF | C7,C8,C16 | Capacitor_SMD:C_0402_1005Metric | C1555
C_Small | C9,C11,C12,C17,C18,C19,C20 | Capacitor_THT:C_Disc_D3.0mm_W1.6mm_P2.50mm
LED | D1,D2,D3,D4 | LED_SMD:LED_0402_1005Metric | C130725
Conn_01x04_Female | J1 | Connector_PinSocket_2.54mm:PinSocket_1x04_P2.54mm_Horizontal
Conn_01x05_Female | J2,J4,J5 | Connector_PinSocket_2.54mm:PinSocket_1x05_P2.54mm_Horizontal
Conn_01x04_Female | J3,J6 | Connector_PinSocket_2.54mm:PinSocket_1x04_P2.54mm_Vertical
Conn_01x06_Female | J7 | Connector_JST:JST_XH_B6B-XH-A_1x06_P2.50mm_Vertical
10K | R1 | Resistor_SMD:R_0402_1005Metric | C25744
1k | R2,R3,R4,R5,R6,R7,R8 | Resistor_SMD:R_0402_1005Metric | C11702
10k | R9,R10,R11 | Resistor_SMD:R_0402_1005Metric | C25744
SW_DIP_x01 | SW1 | Lib:2MS1T2B4M2QES
ATmega2560-16AU | U1 | Package_QFP:TQFP-100_14x14mm_P0.5mm
ATmega16U2-MU | U2 | Package_DFN_QFN:QFN-32-1EP_5x5mm_P0.5mm_EP3.1x3.1mm
Crystal | Y1,Y2 | Crystal:Crystal_SMD_3225-4Pin_3.2x2.5mm | C164049

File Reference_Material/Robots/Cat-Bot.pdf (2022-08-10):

2021/7/21 | Cat-Bot

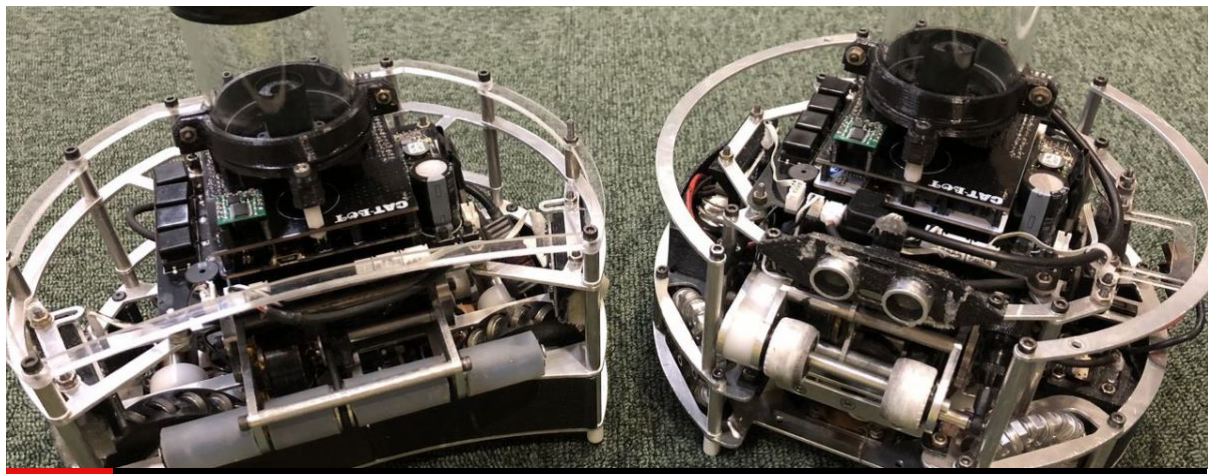
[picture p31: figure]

catbot.blog.jp | 1/9

## Cat-Bot (http://catbot.blog.jp/)

先日ぶりです。Cat-Botで設計を担当していましたsakai Cat-Botです。 (https://twitter.com/YoutaSakai)

RoboCupJunior2019に選手、運営として参加された皆さん本当にお疲れさまでした。

大会が終わってから長時間経過してしまうと「今年の大会もとても楽しかったです。」なんて 感想しか出てこなくなるかもしれないので早いうちに今年の大会についての感想をつらつら書 くことにしました。

RoboCupJunior2019

まず、優勝したRi-one Nanoさん。本当におめでとうございます。
今年の大会ではRi-one Nanoさん、そして、CIAO Tezukayamaさんのロボットの動きのレベルが群 を抜いて高いように感じました。
去年のサッカーオープンでは、オレンジボールを追いかけることに対応しきれているチームが 少なく、オレンジボールを追いかけていればある程度の順位まで登れるような大会だったと記 憶しています。
今年のジャパンオープンではどのチームもオレンジボールを追いかけるのは流石に当たり前だ と思っていましたが、数多くのチームがドリブラーを付けて、しっかりとドリブルができてい る、しかもダブルドリブラーのチームも何チームかいて、RoboCupJuniorSoccer全体の

### レベルが高いものとなってきました。（Juniorとは？）

また、Twitter上でアイコンしか知らない人と顔を合わせ実際にロボットについてお話したり、 他チームのロボットから自分の設計に足りないところ、及ばなかった思想を発見できてとても 有意義な交流ができました。そして、審判の方とロボットだけではなく、今のロボカップに欠 けているルールの穴、運営側の考えと、選手側の心配についてお話しすることが出来たのは結 構楽しかったです。

2019年05月01日
RoboCupJunior JapanOpen2019に出場しました。 (http://catbot.blog.jp/archives/16781626.html) | アクセスカウンター
| 今日：
| 累計：

検索

記事検索

最新記事(画像付)

RoboCupJunior JapanOpen2019に出場しまし
た。 (http://catbot.blog.jp/archives/16781626.html)

RoboCupJuniorSoccerに超小型サイ
クロイド減速機導入の試み (http://catbot.blog.jp/archives/12294665.html)

RoboCup 2018 Montréalの試合動画
を公開しました!! (http://catbot.blog.jp/archives/10537203.html)

RCJ2018Montréalプレゼンポスター (http://catbot.blog.jp/archives/10332966.html)

RCJ2018Montréal オフェンス機のソ
フトについて (http://catbot.blog.jp/archives/10314178.html)

自作メカナム（ロボカップ）の作り
方と注意点 (http://catbot.blog.jp/archives/9114385.html)

ディフェンス機体とトップスピンキ
ッカーについて軽く (http://catbot.blog.jp/archives/9034373.html)

ジャパンオープンの動画公開しました． (http://catbot.blog.jp/archives/8827584.html)
Cat-Botブログ始めました！！ (http://catbot.blog.jp/archives/8393301.html)
TOP (http://catbot.blog.jp/) | Twitter (https://twitter.com/Catbot_rcj) | YouTube (https://www.youtube.com/channel/UCrgZsz1zqw88PnCGcNd3e3g)
日記 (https://blog.livedoor.com/category/2/?_h_jp_pc=category) | ブログを書く (http://livedoor.blogcms.jp/member/) | 7月21日話題の記事 (http://blog.livedoor.com/news/?_h_jp_pc=news)

そして、チーム内で何度か話になったのが、ドリブラー、メカナム、ウレタン、ラインセンサ ーの配置などCat-Botの去年の機体を参考にしてくれているチームが少なからずいたということ です。直接お話しした選手や、TwitterのDMで質問をくれた選手も、自分らが良いと思って開発 してきた技術を吸収し、それに各チームの技術を加えて設計されたロボットを見て、自分たち が開発、解説してきたことの達成感や喜びを感じることが出来ました。 海外の選手の方々からも、Cat-Botの技術、設計データをまねて作ったロボットの写真や、オフ ショット、応援のメッセージが送られてきて、今まで自分たちがやってきたことは様々な人に 受け継がれていると感じることが出来た、そんなロボカップシーズンでした。

RoboCupJunior2019の機体について。
会場でお話しした選手の何名かには悔し紛れに言い訳お話ししましたが、RoboCupJunior2019に 出場させた機体は、本来設計する予定のなかった機体でした。 新機体については大会会場に展示した詐欺ポスターで少し説明が書いてありましたが、回路班 の協力もあり、当時の自分的にはそこそこ満足のいく機体が設計できたと思っています。

新機体の設計コンセプトは、「プログラム班を楽しませる機体を設計する」こと。 去年の機体のダブルドリブラーも、メカナムも操って見せた弊チームの優秀なプログラム班が 無限に遊べるように去年のオフェンス機体から、マウスセンサーとソレノイドを1つ付け足 し、自由に角度を変えられる赤外線レーザーセンサーを4つ増やしました。 自分はプログラムによるロボットの戦略の幅の絶対的な限界はハードウェアの機能の限界がも
たらすものだと考えています。（例えば、機体後方でボールをつかみシュートしたくても、後ろにドリブラー が付いていないのであればできません）
なので搭載できる数の限界までセンサーや機構を積んだら、プログラム班も新たな機体の動き を研究するのが楽しいのではないかと考えました。

これだけの機構を搭載しながら、北信越ブロックの時の機体重量が回路、バッテリー込みで 1900ｇだったので、回路をコンパクトにしてくれた回路班には本当に感謝しています。

RoboCupJuniorに参加した3年間

今年でRoboCupJunior引退なので軽く3年間を振り返ってみました。

RoboCupJunior2017
初の出場は2017年、自分の設計したロボットは、とりあえず動けばいいや程度の何の考えもな しに設計したものでした。北信越ブロック2017の結果は3位で全国大会に参加できないはずだ ったのですが、別ブロックで欠枠が発生し運よく全国大会に出場することが出来ました。その 年は全国大会4位という結果で満足していました。

RoboCupJunior2018
先輩チームのINPUTのオリジナリティーあふれたファンを搭載した設計を見て、前年の自分が ロボカップに影響を与えていない、なんの面白みも強さもない設計をしていたと気が付き、次 はインパクトのあり強いロボットの設計をしたいと思い、メカナムやトップスピンキッカーを 設計し実際に作りました。制御班にとって、前例の無いどう動かしたらいいのか全く分からな いようなロボットを扱うのはとても大変だったと思います。しかし北信越地区大会、全国大会 共に優勝できる動きを実現してくれたことに感謝しています。そして、サイドホイールを2つ のサイズに分けた従来のものより円形に近いオムニホイールや、ウレタンサイドホイール、ダ ブルドリブラーを導入したことにより、全国大会に続いて世界大会でも多くの注目を集めるこ とが出来ました。

RoboCupJunior2019。
設計に関していえば、不完全燃焼って感じです。大会1週間前に新機体を大会に出せないこと が確定し、設計時間だけを考慮したロボットを大会に出さなければいけなくなり「妥協に妥協 を重ね作ったものを大会に参加させて何の意味があるのか……」実際に出場させた機体を設計

人気記事
自作メカナム（ロボカップ）の作り方と注意点 (http://catbot.blog.jp/archives/9114385.html?ref=popular_article&id=7887999-657881)

カテゴリ別アーカイブ

技術 (3) (http://catbot.blog.jp/archives/cat_240390.html)

機械 (2) (http://catbot.blog.jp/archives/cat_240393.html)
プログラム (1) (http://catbot.blog.jp/archives/cat_240395.html)
大会・イベント (3) (http://catbot.blog.jp/archives/cat_240398.html)
その他 (1) (http://catbot.blog.jp/archives/cat_240399.html)

アーカイブ

2019年05月 (http://catbot.blog.jp/archives/2019-05.html)

2018年09月 (http://catbot.blog.jp/archives/2018-09.html)

2018年07月 (http://catbot.blog.jp/archives/2018-07.html)

2018年05月 (http://catbot.blog.jp/archives/2018-05.html)

2018年04月 (http://catbot.blog.jp/archives/2018-04.html)

をしているときはそんなことも考えたりしました。
あの時あきらめなくて本当に良かったです。
即席機体に搭載した、回路班が去年作ってくれた回路は今でもしっかり動作して、プログラム 班は突貫工事にもかかわらず攻守交替までやってくれました。そのおかげで大会時にはしっか りと試合できたし、たくさんの人とお互いのロボットについて交流できました。 設計に関してはあまり満足できませんでしたが、他チームとの交流という面で見ると3年間で 一番楽しかったし有意義なやり取りができました。DCX16死にまくり事件とか

最後に……
自分はこれでNHK高専ロボコン、RoboCupJuniorともに引退したため、これから競技用のロボ ットを設計する機会はあまりないかもしれませんが、質問はいつでも受け付けているのでコメ ント欄やTwitterで待機しています。今日から大学受験に気持ちを切り替えて頑張っていこうか なと。（世界大会に呼ばれたらロボットも頑張りますが）

今までノウハウを教えてくれた先輩方、情報交換をしてくれた皆さん、Cat-Botの技術に興味を 持ってくれた皆さん本当にありがとうございました。引率の先生含めこれからは自分も後輩に ノウハウを伝えていこうと思います。長岡高専には4-axisのメンバー含め、優秀な後輩たちが 大勢います。来年も長岡高専から優秀なエージェントが和歌山に向けて放たれるかと思います ので覚悟しておいてください。

機体の各パーツについての解説ブログは受験などが落ち着いてから書こうと思います。

それではまたTwitterで会いましょう。

コメント（0） (http://catbot.blog.jp/archives/16781626.html#comments)

お久しぶりですCat-Botの酒井(@Youtsakai)です。 (https://twitter.com/YoutaSakai)

今回のブログは、サイクロイド減速機のRoboCupJuniorSoccerへの導入についてなのですが、 残念ながら実際に導入することが難しくなったので、こんな計画をしていたという内容の記事 となります。
(以降RoboCupJuniorSoccerをRCJSと書きます。)

皆さん、「RCJSは押し合いがあるからトルクがあったほうが強いんじゃない？」とか、「ス ピードのある機体で素早くボールを保持したほうが強いんじゃない？」などと機体設計やモー ター選定のたびにとても悩んでいると思います。

RCJSに必要なのはトルクかスピードか？

とりあえずCat-Botは「足回りのトルクとスピードの両立」を目標としました。 僕達が目指す「トルクとスピードの両立」とは、トルクもスピードも他のチームより高いとい うことです。
しかし、いろいろなモーター（+ギアヘッド）を調べたところRCJSに導入されていないレベル の強いモーターは寸法的に機体に組み込めない、もしくは高価すぎて手に入らないものばかり
LINEで送る | いいね | ツイート (https://twitter.com/intent/tweet?original_referer=http%3A%2F%2Fcatbot.blog.jp%2F&tw_p=tweetbutton) | いいね！ 0

2018年09月25日

### RoboCupJuniorSoccerに超小型サイクロイド減速機導

# 入の試み (http://catbot.blog.jp/archives/12294665.html)

でした。
そこで、取り付けるギアヘッドを小さくすれば強いモーターを搭載できるのではないかと考え ました。

上記の理由から導入を試みていたのが拾壱・ビッグストーン社の超小型サイクロイド減速機で す。
サイクロイド減速機を設計、製作している拾壱・ビッグストーン社代表の大石克輝さんから、 試験用の超小型サイクロイド減速機を提供していただき、他を圧倒するトルクとスピードの両 立をするロボットを完成させるというのが今回の計画の目標でした。

しかし残念ながら1ヶ月半ほど前、我がチームの回路屋が日本のルールでのバッテリー制限を 考えると馬鹿みたいに強いモーターは機体に取り付けることが難しいと結論を出し、サイクロ イド減速機を導入する計画を断念することになりました。じゃあ日本で使える最高峰の馬鹿力 モーターにサイクロイド減速比を取り付けよう！！と考えて、新しくモーターを選定し直した のですが、とても手が出せないような高価な値段であったり、サイクロイド減速機を導入する と既製品ギアヘッドよりスペースを使うことになるなどといった理由で断念せざるを得ません でした。

しかし、超小型サイクロイド減速機導入計画なんて面白そうなものを公開しないで寝かせてお くなんてもったいない事できないため大急ぎでブログを書きました。

これから簡単に今まで計画してきたサイクロイド減速機について書いていこうと思います。

まず”サイクロイド減速機”を知らない人もいると思うので、拾壱・ビッグストーン社様からブ ログ用に頂いたPDFの画像を載せます。

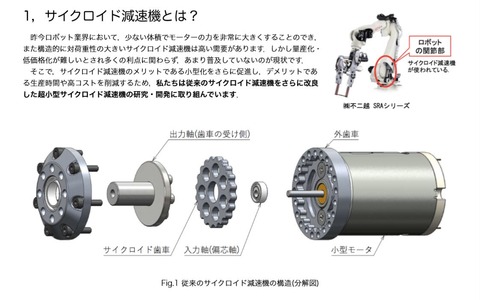
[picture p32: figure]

簡単にサイクロイド減速機のメリットとデメリットを上げていきます。 ＜メリット＞
・省スペースで高減速が可能
・歯車が滑らかな曲線のため一般的なインボリュートギアに比べて壊れにくい。 ＜デメリット＞
・高価

と、自分が簡単に思い浮かぶのはこれくらいです。

しかし住友重機械工業株式会社さんなどで販売されているサイクロ減速機は、たしかに省スペ ースなもののRCJSに導入できるレベルの大きさではありません。そこで現在、拾壱・ビッグ ストーン社が研究・開発しているRCJSの機体にも収まるような大きさと重さ、そして低価格 のサイクロイド減速機を導入してみようという計画を練りました。

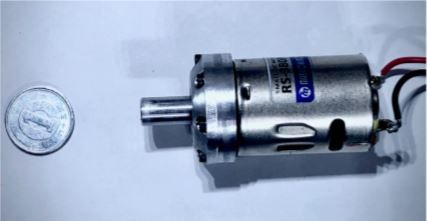
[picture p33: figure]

拾壱・ビッグストーン社製サイクロイド減速機と１円玉のサイズ比較

上の写真だけでこの減速機がいかに小さいかは確認していただけたかと思います

そして今年僕達が導入を目指していたサイクロイド減速機のCADデータの画像です。

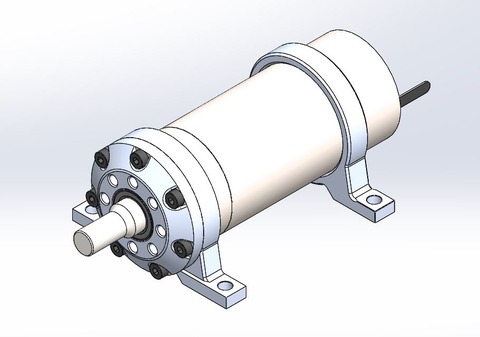
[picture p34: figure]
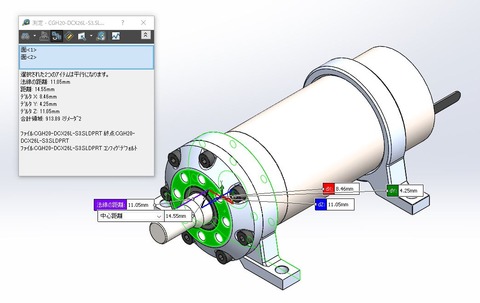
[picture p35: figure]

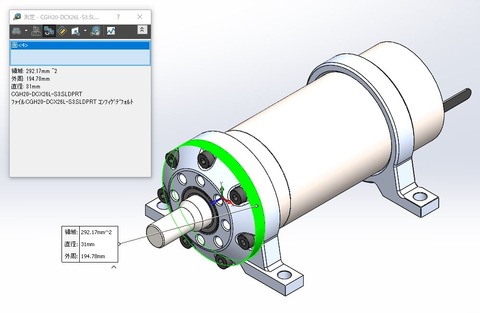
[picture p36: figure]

サイクロイド減速機+maxonDCX26ユニット

今回導入しようとしていたサイクロイド減速機は、厚さが11ｍｍ、径が31ｍｍと超小型の寸法 で減速比は10～20：1を想定していました。

最後に、今回の僕たちのRCJラグビー化計画で試験用サイクロイド減速機を提供してくれた大 石さん、本当にありがとうございます。今年もしっかり競技名に沿ってサッカーしようと思い ます。
拾壱・ビッグストーン社製のサイクロイド減速機本当にすごいと思うので興味がある方は、下 記のホームページを是非のぞいてみてください。

拾壱・ビッグストーン 代表 大石 克輝
会社ホームページ：http://11bigstone.com/

今回はこれで終わります。
日本大会には拾壱・ビッグストーン社製サイクロイド減速機を持って行こうと思います。

とは言っても、まだRCJの機体設計すら始められていないので、日本大会に出場できるように これから全力で取り組んでいきます。

コメント（0） (http://catbot.blog.jp/archives/12294665.html#comments)

Ishibashi(@number_key0921)です． (https://twitter.com/number_key0921)

RoboCup 2018 世界大会 モントリオール(カナダ)での試合動画を公開しました．

LINEで送る | いいね | ツイート (https://twitter.com/intent/tweet?original_referer=http%3A%2F%2Fcatbot.blog.jp%2F&tw_p=tweetbutton) | いいね！ 1

2018年07月12日

### RoboCup 2018 Montréalの試合動画を公開しました!! (http://catbot.blog.jp/archives/10537203.html)

動画の視点が悪かったりして見づらいかもしれませんが許してください． あと，ある動画の途中で変なのが映り込んできますが気にしないでください(笑)．

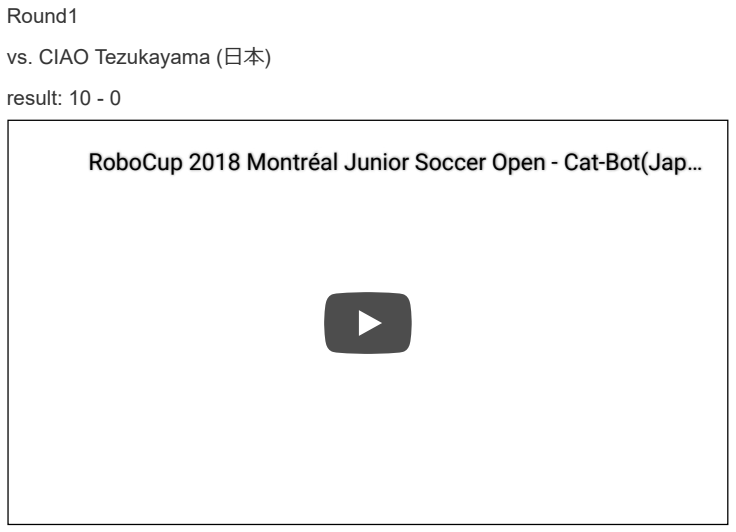
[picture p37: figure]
Round1; vs. CIAO Tezukayama (日本); result: 10 - 0
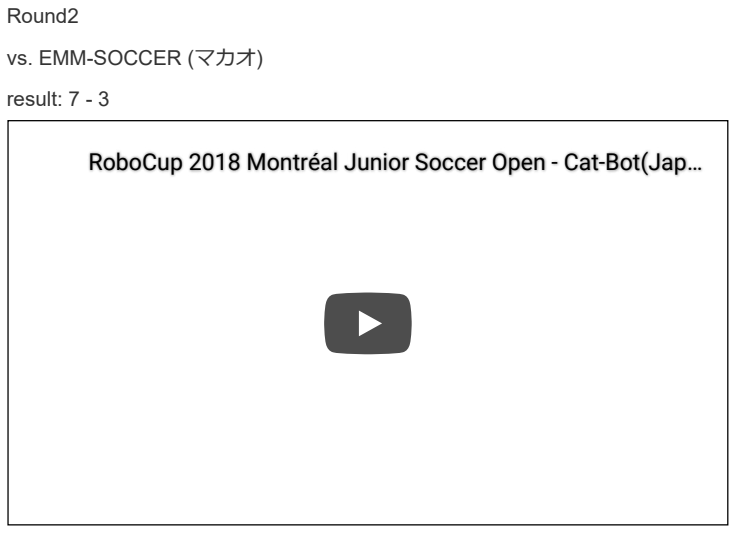
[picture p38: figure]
Round2; vs. EMM-SOCCER (マカオ); result: 7 - 3
Round3; vs. AGSG III (ポルトガル); result: 10 - 0

Round4
vs. SoccerXY (ドイツ)

RoboCup 2018 Montréal Junior Soccer Open - Cat-Bot(Jap… (https://www.youtube.com/watch?v=rOW4ewS6hXA)

RoboCup 2018 Montréal Junior Soccer Open - Cat-Bot(Jap… (https://www.youtube.com/watch?v=R0uBVGnTtg4)

RoboCup 2018 Montréal Junior Soccer Open - Cat-Bot(Jap… (https://www.youtube.com/watch?v=16tLA46fauQ)

result: 11 - 1
Round5; vs. T.O.T (カナダ); result: 2 - 7

Round6
vs. KAO YIP ROBOT TEAM (マカオ)

result: 4 - 7

Round7
vs. Reset (台湾)

result: 10 - 0

RoboCup 2018 Montréal Junior Soccer Open - Cat-Bot(Jap… (https://www.youtube.com/watch?v=5yH5L6ejKDI)

RoboCup 2018 Montréal Junior Soccer Open - Cat-Bot(Jap… (https://www.youtube.com/watch?v=xrTqo1stNAY)

RoboCup 2018 Montréal Junior Soccer Open - Cat-Bot(Jap… (https://www.youtube.com/watch?v=TpxiktDEHTE)

Powered by ライブドアブログ; カテゴリ ：; 大会・イベント; 各動画の解説は後程するかも?; それから質問があったら気軽にしてください．; コメント（0）; LINEで送る; いいね; ツイート; いいね！ 0

RoboCup 2018 Montréal Junior Soccer Open - Cat-Bot(Jap… (https://www.youtube.com/watch?v=wkGMOKJCBtQ)

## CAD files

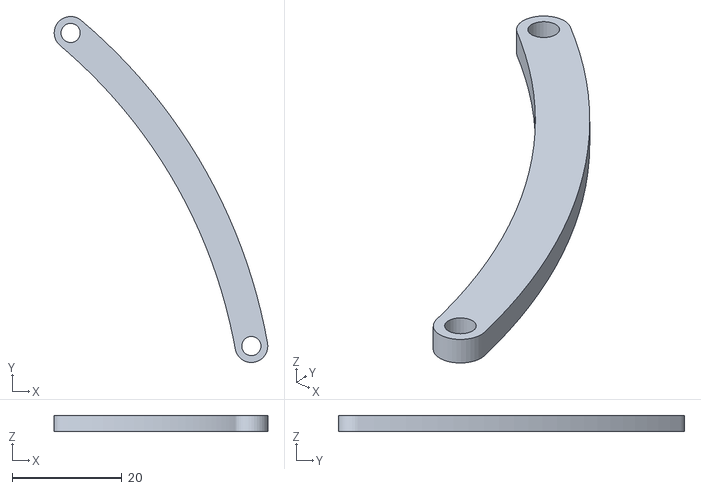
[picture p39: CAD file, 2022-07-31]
Design/2022 early/3D printed components/タイヤカバー.stl
39.0 x 63.2 x 3.00

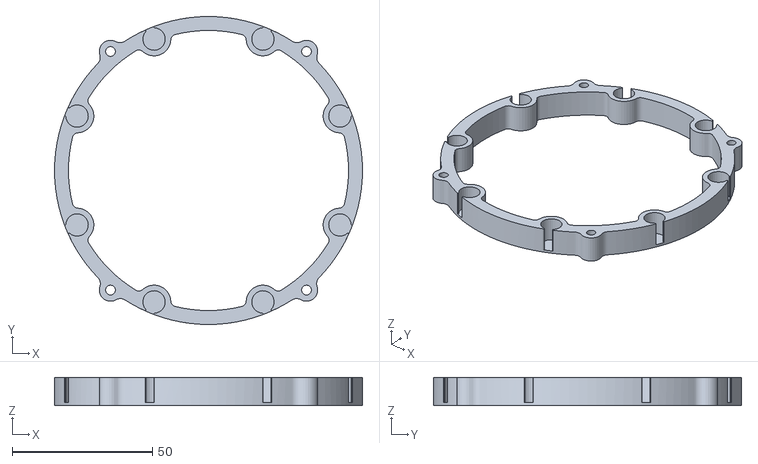
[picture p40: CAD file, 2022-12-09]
Design/2022 late/IR隠し2 v2.stl
110.0 x 110.0 x 10.0

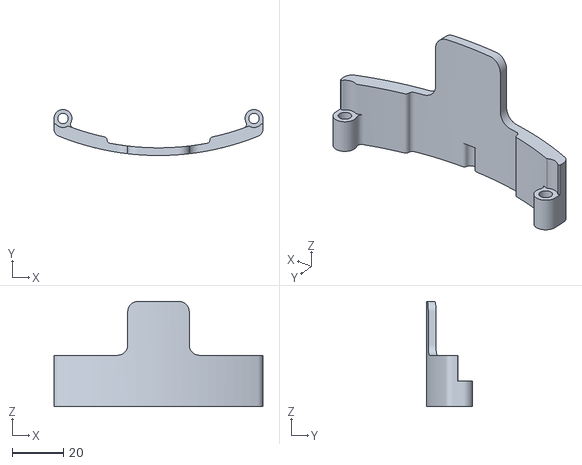
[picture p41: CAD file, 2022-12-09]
Design/2022 late/ver.Teensy/3D printed components/バッテリーカバー .stl
81.5 x 17.9 x 41.0

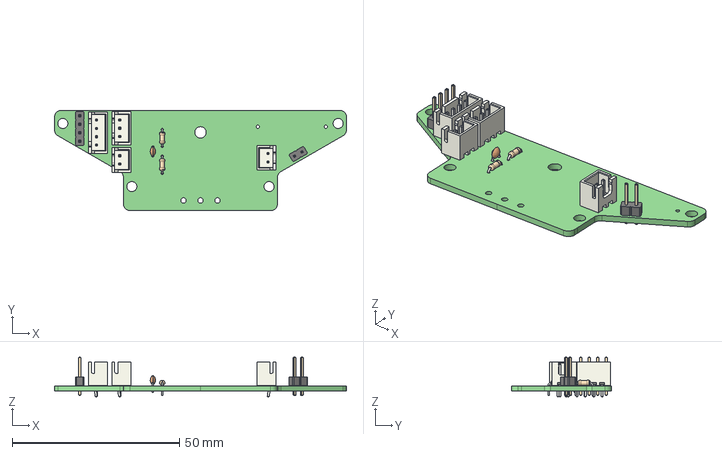
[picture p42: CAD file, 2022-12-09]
Design/2022 late/ver.Teensy/electric components/kikker_board.step
87.3 x 30.0 x 11.9 mm
kikker_board PCB

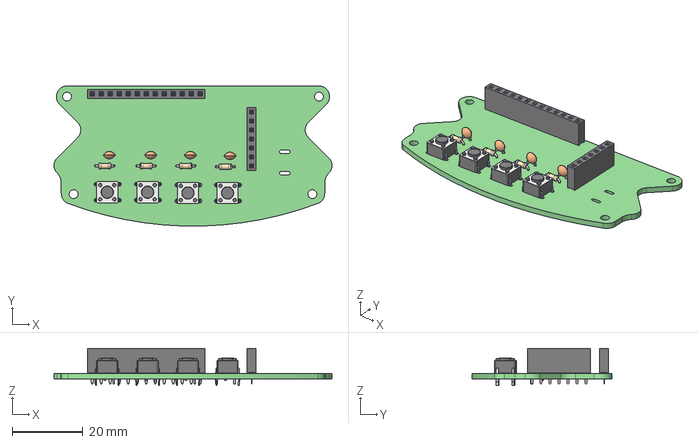
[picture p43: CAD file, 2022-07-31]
KiCad_Projects/2022 early/io board/io_board/io_board.step
78.4 x 39.5 x 10.5 mm
io_board PCB

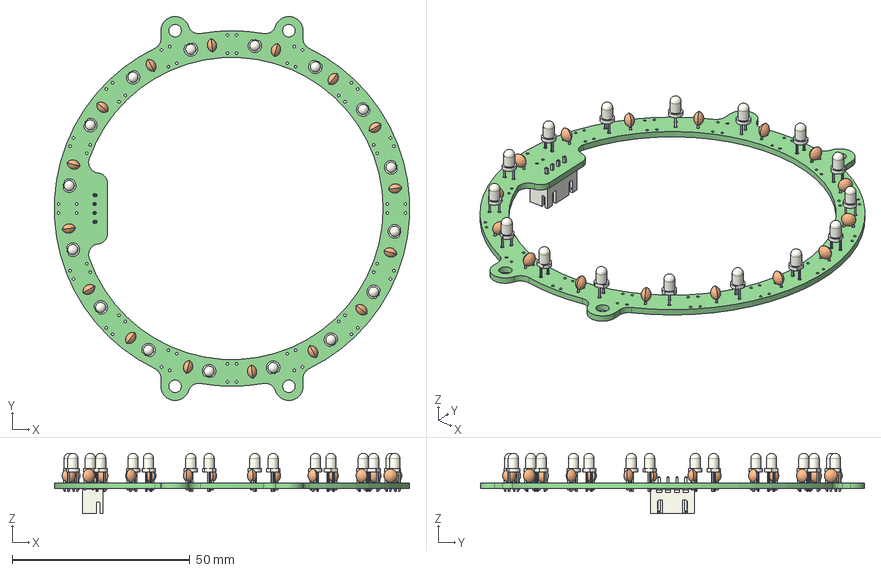
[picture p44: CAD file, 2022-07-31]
KiCad_Projects/2022 late/TJ3B_ver/line_sensor/line_sensor.step
99.9 x 108.0 x 17.0 mm
line_sensor PCB

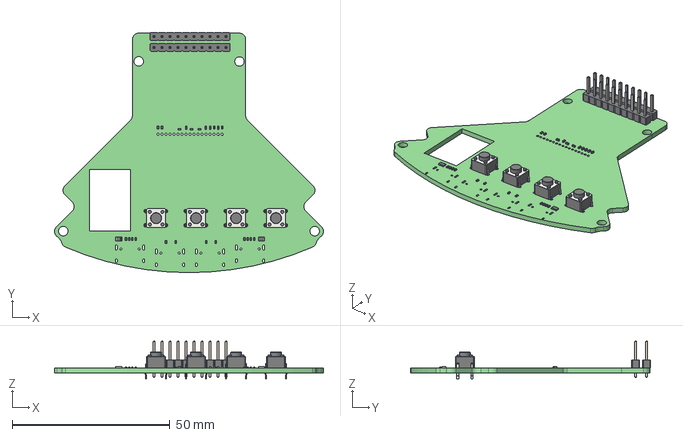
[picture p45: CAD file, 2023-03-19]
KiCad_Projects/2023_early/Teensy_ver/IO_Board_Teensy/IO_Board.step
85.4 x 76.2 x 12.0 mm
IO_Board PCB

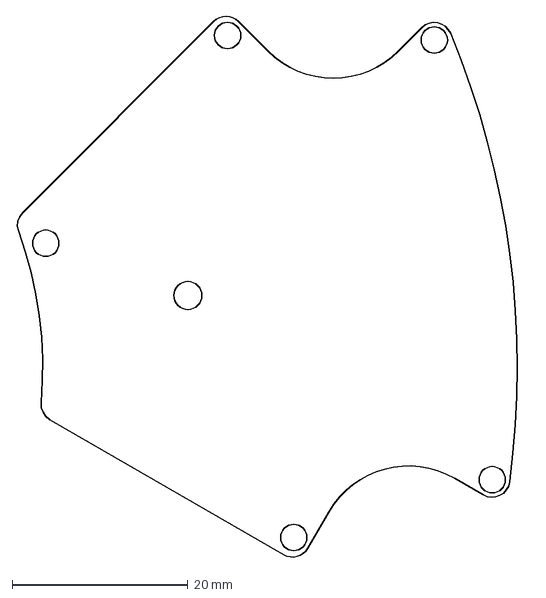
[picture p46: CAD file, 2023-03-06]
KiCad_Projects/2023_early/Teensy_ver/Kiker_PSU/PCB.dxf
58.5 x 61.6 mm

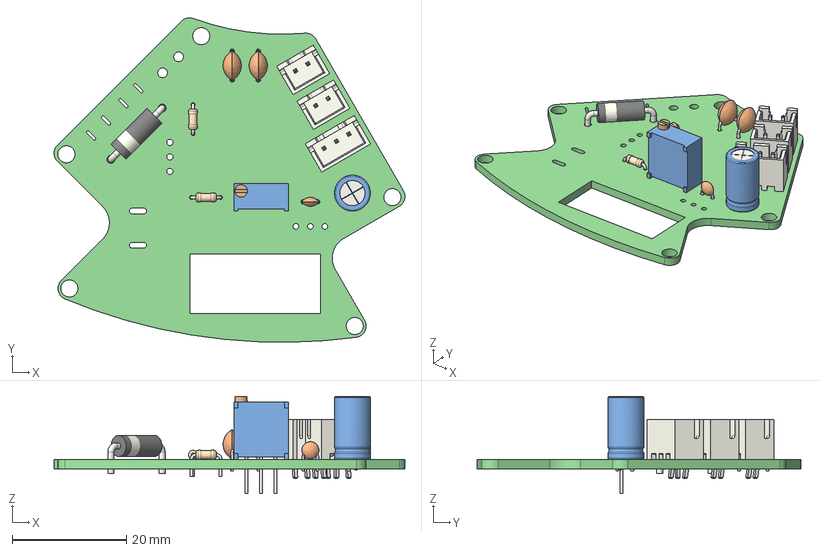
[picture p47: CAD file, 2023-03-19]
KiCad_Projects/2023_early/Teensy_ver/psu_board/psu_board.step
61.5 x 56.9 x 17.1 mm
psu_board PCB

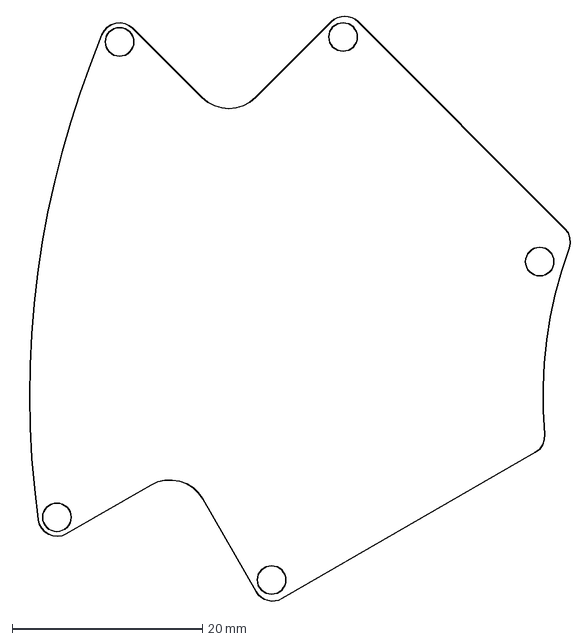
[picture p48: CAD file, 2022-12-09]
KiCad_Projects/3D_Data/2022 late/基板右.dxf
58.5 x 61.6 mm

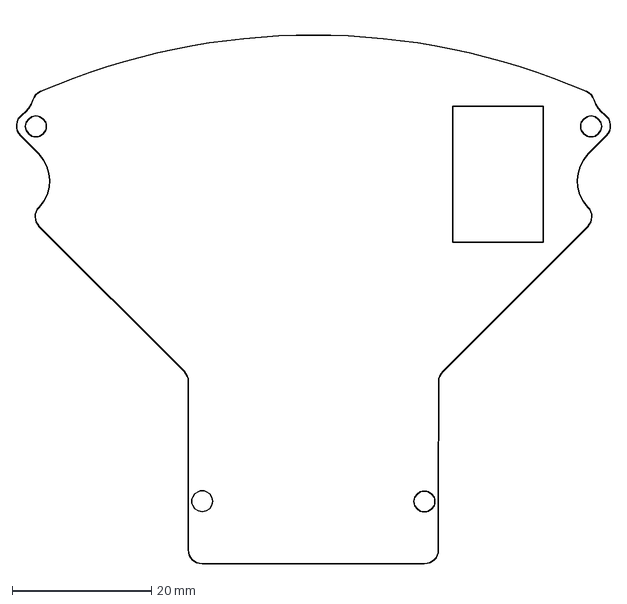
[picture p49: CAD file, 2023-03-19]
KiCad_Projects/3D_Data/2023 early/IO.dxf
85.5 x 78.7 mm

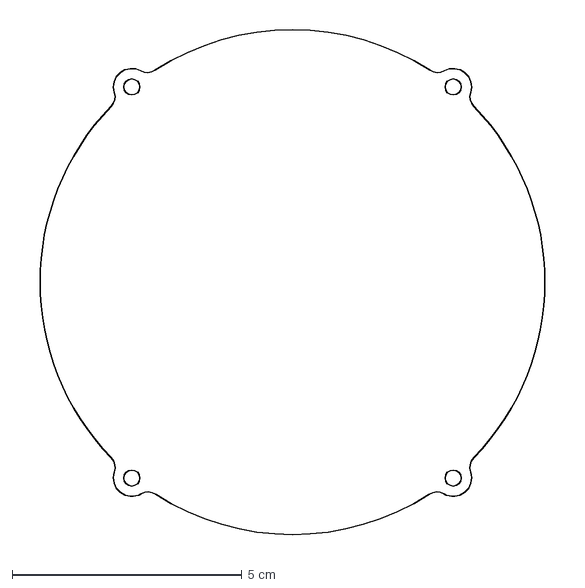
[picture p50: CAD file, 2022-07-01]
KiCad_Projects/3D_Data/メイン基板 .dxf
12.0 x 11.6 cm

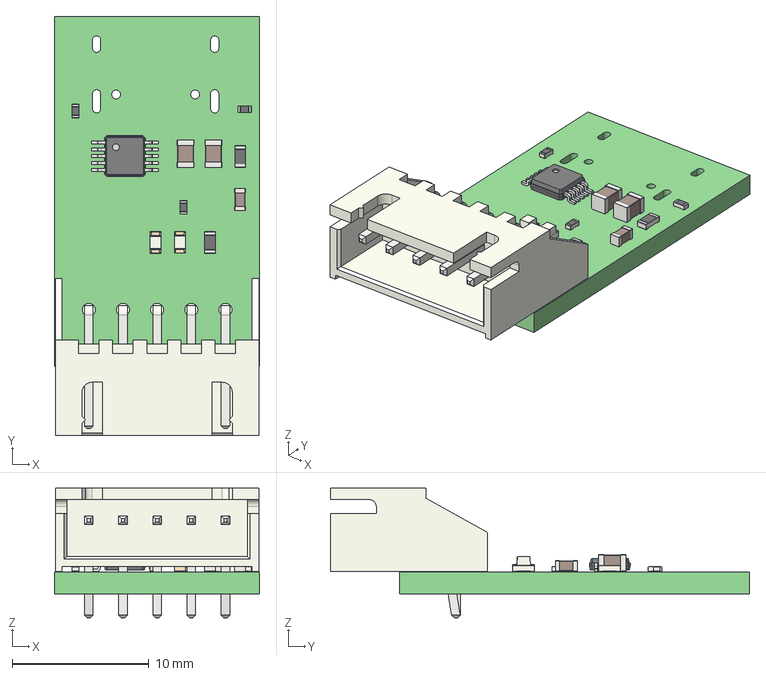
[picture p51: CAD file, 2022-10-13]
KiCad_Projects/その他/MPU6050/AT.step
15.0 x 30.7 x 9.50 mm

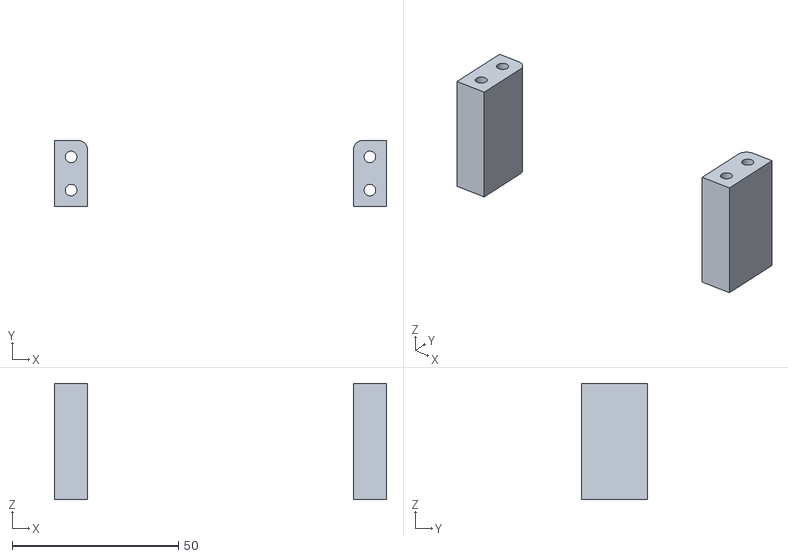
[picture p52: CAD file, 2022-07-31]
Design/2022 early/3D printed components/タッチセンサー.stl
100.0 x 20.0 x 35.0

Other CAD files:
Design/2022 late/ver.Teensy/3D printed components/筒固定具.stl
Design/2022 late/ver.Teensy/electric components/psu_board.step
Design/2022 early/3D printed components/IR隠し .f3d
Design/2022 early/3D printed components/IR隠し.stl
Design/2022 early/3D printed components/artemis omni 上 .f3d
Design/2022 early/3D printed components/artemis omni 下 .f3d
Design/2022 early/3D printed components/artemis omuni 固定具 v1.f3d
Design/2022 early/3D printed components/タイヤカバー.f3d
Design/2022 early/3D printed components/タッチセンサー .f3d
Design/2022 early/3D printed components/バッテリーケース.f3d
Design/2022 early/3D printed components/バッテリーケース.stl
Design/2022 early/3D printed components/筒固定具 .f3d
Design/2022 early/3D printed components/筒固定具.stl
Design/2022 early/Electric circuit components/4ちゃん .f3d
Design/2022 early/Electric circuit components/OpenMV H7 .f3d
Design/2022 early/Electric circuit components/io_board_step .f3d
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

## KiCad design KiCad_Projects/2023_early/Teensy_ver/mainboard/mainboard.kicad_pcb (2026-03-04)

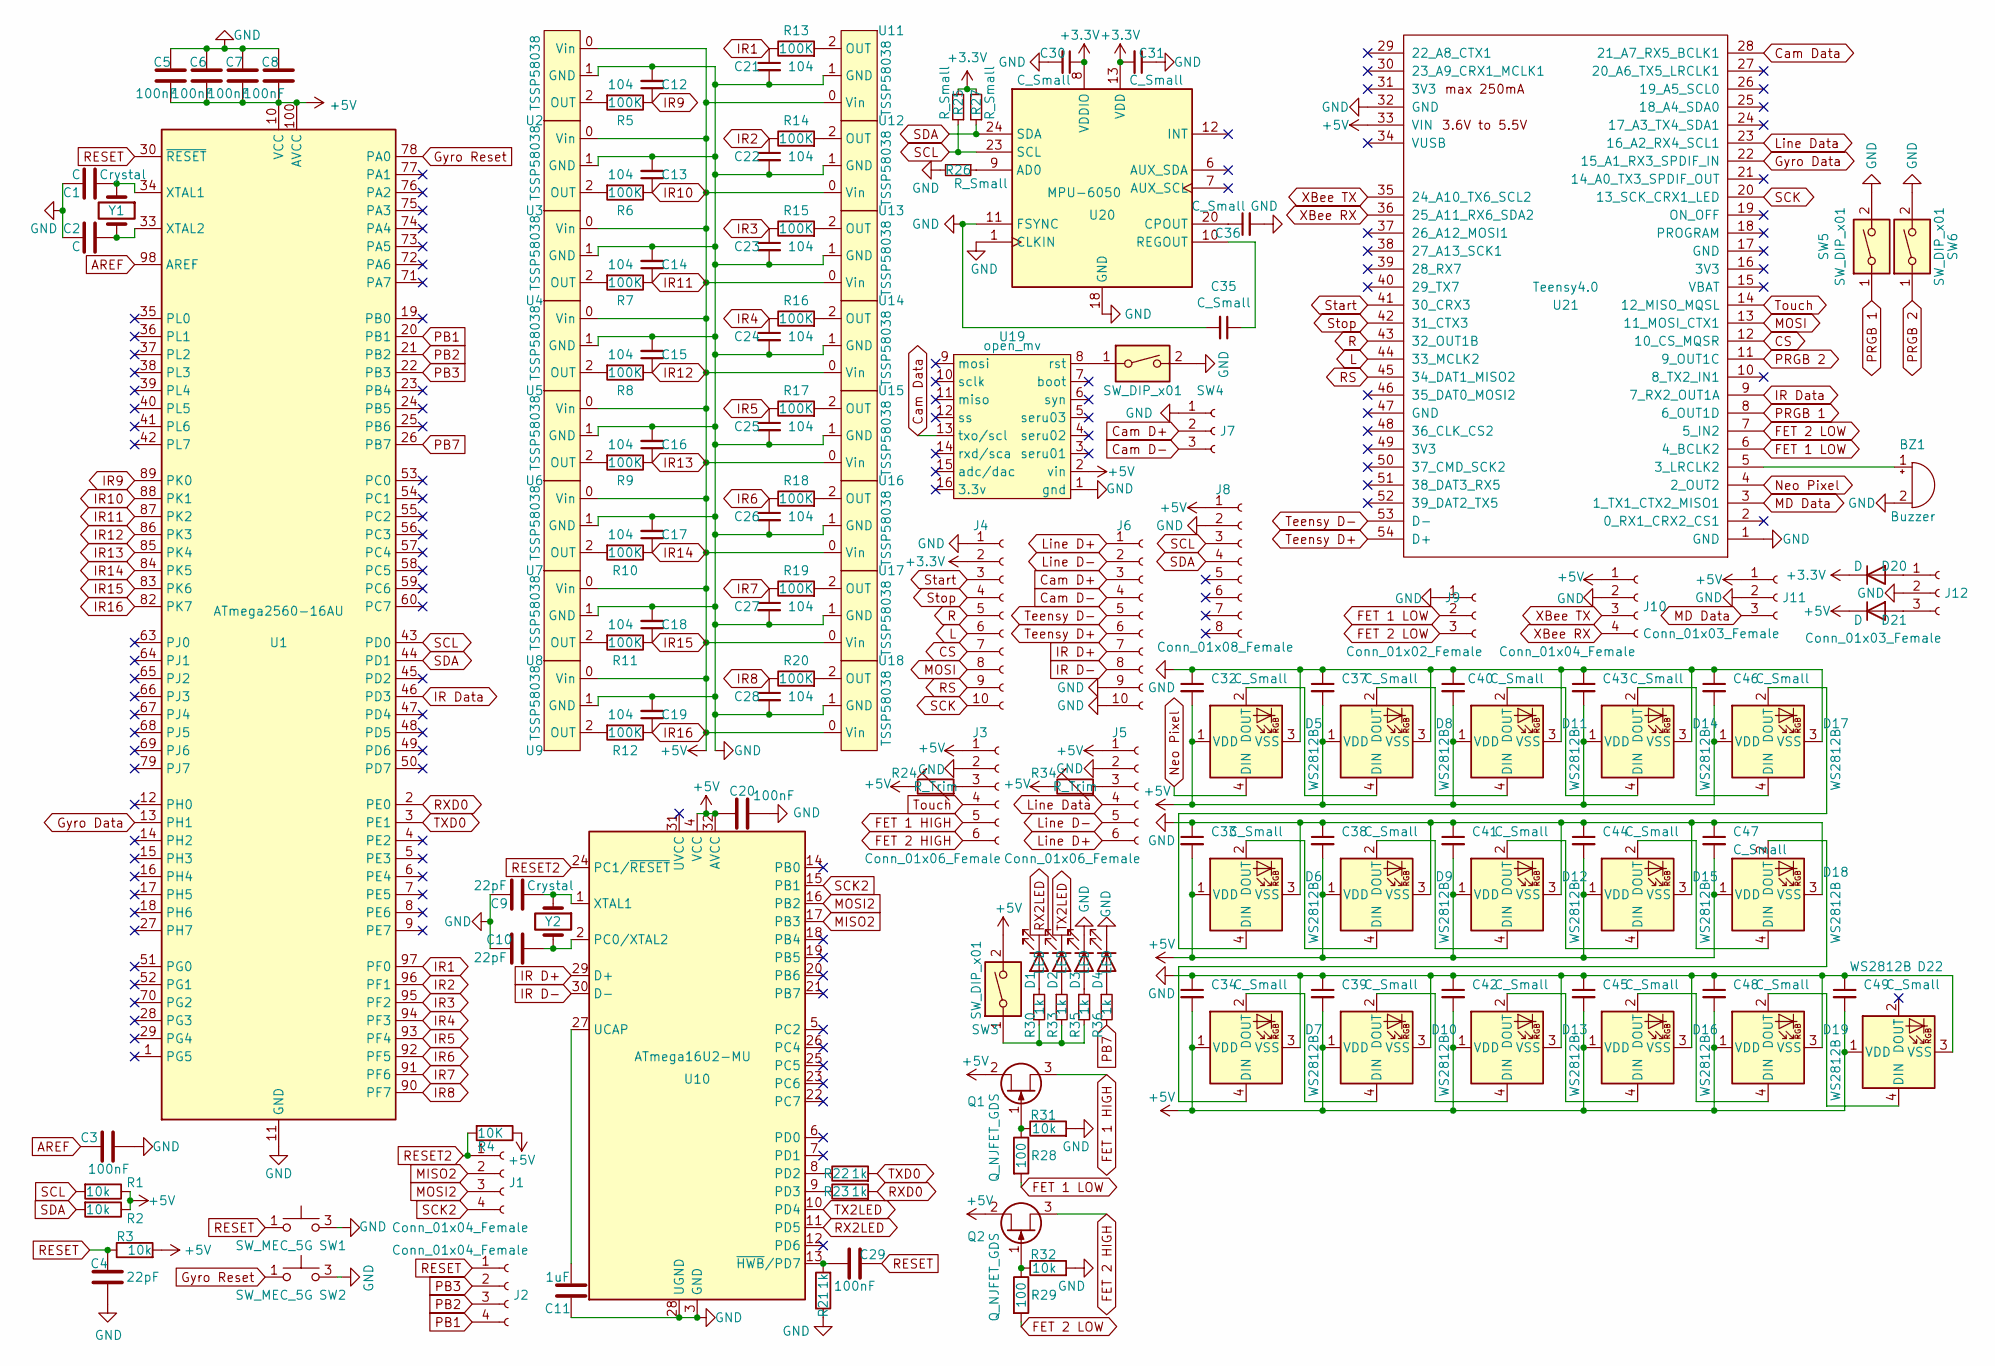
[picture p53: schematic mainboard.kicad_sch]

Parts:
BZ1: Buzzer; Buzzer_12x9.5RM7.6
C1, C2: C; C_0402_1005Metric; LCSC C1555
C3, C5, C6, C7, C8, C20, C29: 100nF; C_0402_1005Metric; LCSC C41851
C4, C9, C10: 22pF; C_0402_1005Metric; LCSC C1555
C11: 1uF; C_0402_1005Metric; LCSC C167339
C12, C13, C14, C15, C16, C17, C18, C19, C21, C22, C23, C24, C25, C26, C27, C28: 104; C_0402_1005Metric; LCSC C1525
C30: C_Small; C_0603_1608Metric; LCSC C57112
C31, C35: C_Small; C_0603_1608Metric; LCSC C30926
C32, C33, C34, C37, C38, C39, C40, C41, C42, C43, C44, C45, C46, C47, C48, C49: C_Small; C_0402_1005Metric; LCSC C1525
C36: C_Small; C_0603_1608Metric; LCSC C1604
D1, D2, D3, D4: LED; LED_0402_1005Metric; LCSC C130725
D5, D6, D7, D9, D10, D11, D12, D13, D14, D15, D16, D17, D18, D19, D22: WS2812B; LED_WS2812B_PLCC4_5.0x5.0mm_P3.2mm; LCSC C2761795
D8: WS2812B; LED_WS2812B_PLCC4_5.0x5.0mm_P3.2mm
D20, D21: D; D_A-405_P7.62mm_Horizontal
J1, J2: Conn_01x04_Female; PinSocket_1x04_P2.54mm_Vertical
J3, J5: Conn_01x06_Female; JST_XH_B6B-XH-A_1x06_P2.50mm_Vertical
J4: Conn_01x10_Female; PinHeader_1x10_P2.54mm_Vertical
J6: Conn_01x10_Female; PinSocket_1x10_P2.54mm_Vertical
J7: Conn_01x03_Female; PinSocket_1x03_P2.54mm_Vertical
J8: Conn_01x08_Female; PinSocket_1x08_P2.54mm_Vertical
J9: Conn_01x02_Female; JST_XH_B2B-XH-A_1x02_P2.50mm_Vertical
J10: Conn_01x04_Female; JST_XH_B4B-XH-A_1x04_P2.50mm_Vertical
J11, J12: Conn_01x03_Female; JST_XH_B3B-XH-A_1x03_P2.50mm_Vertical
Q1, Q2: Q_NJFET_GDS; MSKSEMI
R1, R2, R3, R31, R32: 10k; R_0402_1005Metric; LCSC C25744
R4: 10K; R_0402_1005Metric; LCSC C25744
R5, R6, R7, R8, R9, R10, R11, R12, R13, R14, R15, R16, R17, R18, R19, R20: 100K; R_0402_1005Metric; LCSC C25741
R21, R22, R23: 1k; R_0402_1005Metric; LCSC C105637
R24, R34: R_Trim; 可変抵抗(小)
R25, R27: R_Small; R_0603_1608Metric; LCSC C4190
R26: R_Small; R_0603_1608Metric; LCSC C23162
R28, R29: 100; R_0402_1005Metric; LCSC C25076
R30, R33, R35, R36: 1k; R_0402_1005Metric; LCSC C11702
SW1, SW2: SW_MEC_5G; SW_PUSH_6mm
SW3: SW_DIP_x01; 2MS1T2B4M2QES
SW4, SW5, SW6: SW_DIP_x01; SW_PUSH_6mm_H5mm
U1: ATmega2560-16AU; TQFP-100_14x14mm_P0.5mm
U2, U3, U4, U5, U6, U7, U8, U9, U11, U12, U13, U14, U15, U16, U17, U18: TSSP58038; TSSP58038_IR
U10: ATmega16U2-MU; QFN-32-1EP_5x5mm_P0.5mm_EP3.1x3.1mm
U19: open_mv; OpenMV
U20: MPU-6050; InvenSense_QFN-24_4x4mm_P0.5mm; LCSC C24112
U21: Teensy4.0; Teensy_Brakeout
Y1, Y2: Crystal; Crystal_SMD_3225-4Pin_3.2x2.5mm; LCSC C164049

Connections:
+3V3: C30.1, C31.2, D20.1 (K), J4.2, R25.2, R27.2, U20.8 (VDDIO), U20.13 (VDD)
+5V: C5.2, C6.2, C7.2, C8.2, C20.2, C32.2, C33.2, C34.2, C37.2, C38.2, C39.2, C40.2, C41.2, C42.2, C43.2, C44.2, C45.2, C46.2, C47.2, C48.2, C49.2, D5.1 (VDD), D6.1 (VDD), D7.1 (VDD), D8.1 (VDD), D9.1 (VDD), D10.1 (VDD), D11.1 (VDD), D12.1 (VDD), D13.1 (VDD), D14.1 (VDD), D15.1 (VDD), D16.1 (VDD), D17.1 (VDD), D18.1 (VDD), D19.1 (VDD), D21.1 (K), D22.1 (VDD), J3.1, J5.1, J8.1, J10.1, J11.1, Q1.2 (D), Q2.2 (D), R1.1, R2.1, R3.2, R4.1, R24.1, R34.1, SW3.2, U1.10 (VCC), U1.31 (VCC), U1.61 (VCC), U1.80 (VCC), U1.100 (AVCC), U2.0 (Vin), U3.0 (Vin), U4.0 (Vin), U5.0 (Vin), U6.0 (Vin), U7.0 (Vin), U8.0 (Vin), U9.0 (Vin), U10.4 (VCC), U10.32 (AVCC), U11.0 (Vin), U12.0 (Vin), U13.0 (Vin), U14.0 (Vin), U15.0 (Vin), U16.0 (Vin), U17.0 (Vin), U18.0 (Vin), U19.2 (vin), U21.33 (VIN)
AREF: C3.1, U1.98 (AREF)
CS: J4.7, U21.12 (10_CS_MQSR)
Cam D+: J6.3, J7.2
Cam D-: J6.4, J7.3
Cam Data: U19.13 (txo/scl), U21.28 (21_A7_RX5_BCLK1)
FET 1 HIGH: J3.5, Q1.3 (S)
FET 1 LOW: J9.2, R28.2, U21.6 (4_BCLK2)
FET 2 HIGH: J3.6, Q2.3 (S)
FET 2 LOW: J9.3, R29.2, U21.7 (5_IN2)
GND: BZ1.2 (+), C1.2, C2.2, C3.2, C4.2, C5.1, C6.1, C7.1, C8.1, C9.2, C10.2, C11.2, C12.2, C13.2, C14.2, C15.2, C16.2, C17.2, C18.2, C19.2, C20.1, C21.2, C22.2, C23.2, C24.2, C25.2, C26.2, C27.2, C28.2, C30.2, C31.1, C32.1, C33.1, C34.1, C35.2, C36.2, C37.1, C38.1, C39.1, C40.1, C41.1, C42.1, C43.1, C44.1, C45.1, C46.1, C47.1, C48.1, C49.1, D3.1 (K), D4.1 (K), D5.3 (VSS), D6.3 (VSS), D7.3 (VSS), D8.3 (VSS), D9.3 (VSS), D10.3 (VSS), D11.3 (VSS), D12.3 (VSS), D13.3 (VSS), D14.3 (VSS), D15.3 (VSS), D16.3 (VSS), D17.3 (VSS), D18.3 (VSS), D19.3 (VSS), D22.3 (VSS), J3.2, J4.1, J5.2, J6.9, J6.10, J7.1, J8.2, J9.1, J10.2, J11.2, J12.2, R21.1, R26.2, R31.2, R32.2, SW1.3 (B), SW1.4 (B), SW2.3 (B), SW2.4 (B), SW4.2, SW5.2, SW6.2, U1.11 (GND), U1.32 (GND), U1.62 (GND), U1.81 (GND), U1.99 (GND), U2.1 (GND), U3.1 (GND), U4.1 (GND), U5.1 (GND), U6.1 (GND), U7.1 (GND), U8.1 (GND), U9.1 (GND), U10.3 (GND), U10.28 (UGND), U10.33 (GND), U11.1 (GND), U12.1 (GND), U13.1 (GND), U14.1 (GND), U15.1 (GND), U16.1 (GND), U17.1 (GND), U18.1 (GND), U19.1 (gnd), U20.1 (CLKIN), U20.11 (FSYNC), U20.18 (GND), U21.1 (GND), U21.32 (GND)
Gyro Data: U1.13 (PH1), U21.22 (15_A1_RX3_SPDIF_IN)
Gyro Reset: SW2.1 (A), SW2.2 (A), U1.78 (PA0)
IR1: C21.1, R13.1, U1.97 (PF0)
IR2: C22.1, R14.1, U1.96 (PF1)
IR3: C23.1, R15.1, U1.95 (PF2)
IR4: C24.1, R16.1, U1.94 (PF3)
IR5: C25.1, R17.1, U1.93 (PF4)
IR6: C26.1, R18.1, U1.92 (PF5)
IR7: C27.1, R19.1, U1.91 (PF6)
IR8: C28.1, R20.1, U1.90 (PF7)
IR9: C12.1, R5.1, U1.89 (PK0)
IR10: C13.1, R6.1, U1.88 (PK1)
IR11: C14.1, R7.1, U1.87 (PK2)
IR12: C15.1, R8.1, U1.86 (PK3)
IR13: C16.1, R9.1, U1.85 (PK4)
IR14: C17.1, R10.1, U1.84 (PK5)
IR15: C18.1, R11.1, U1.83 (PK6)
IR16: C19.1, R12.1, U1.82 (PK7)
IR D+: J6.7, U10.29 (D+)
IR D-: J6.8, U10.30 (D-)
IR Data: U1.46 (PD3), U21.9 (7_RX2_OUT1A)
L: J4.6, U21.44 (33_MCLK2)
Line D+: J5.6, J6.1
Line D-: J5.5, J6.2
Line Data: J5.4, U21.23 (16_A2_RX4_SCL1)
MD Data: J11.3, U21.3 (1_TX1_CTX2_MISO1)
MISO2: J1.2, U10.17 (PB3)
MOSI: J4.8, U21.13 (11_MOSI_CTX1)
MOSI2: J1.3, U10.16 (PB2)
Neo Pixel: D5.4 (DIN), U21.4 (2_OUT2)
unnamed: BZ1.1 (-), U21.5 (3_LRCLK2)
unnamed: C1.1, U1.34 (XTAL1), Y1.1
unnamed: C2.1, U1.33 (XTAL2), Y1.2
unnamed: C9.1, U10.1 (XTAL1), Y2.1
unnamed: C10.1, U10.2 (PC0/XTAL2), Y2.2
unnamed: C11.1, U10.27 (UCAP)
unnamed: C29.1, R21.2, U10.13 (~HWB/PD7)
unnamed: C35.1, U20.10 (REGOUT)
unnamed: C36.1, U20.20 (CPOUT)
unnamed: D1.2 (A), R30.1
unnamed: D2.2 (A), R33.1
unnamed: D3.2 (A), R35.1
unnamed: D4.2 (A), R36.1
unnamed: D5.2 (DOUT), D8.4 (DIN)
unnamed: D6.2 (DOUT), D9.4 (DIN)
unnamed: D10.2 (DOUT), D13.4 (DIN)
unnamed: D7.2 (DOUT), D10.4 (DIN)
unnamed: D11.2 (DOUT), D14.4 (DIN)
unnamed: D8.2 (DOUT), D11.4 (DIN)
unnamed: D12.2 (DOUT), D15.4 (DIN)
unnamed: D9.2 (DOUT), D12.4 (DIN)
unnamed: D13.2 (DOUT), D16.4 (DIN)
unnamed: D14.2 (DOUT), D17.4 (DIN)
unnamed: D15.2 (DOUT), D18.4 (DIN)
unnamed: D16.2 (DOUT), D19.4 (DIN)
unnamed: D6.4 (DIN), D17.2 (DOUT)
unnamed: D7.4 (DIN), D18.2 (DOUT)
unnamed: D19.2 (DOUT), D22.4 (DIN)
unnamed: D20.2 (A), J12.1
unnamed: D21.2 (A), J12.3
unnamed: J3.3, R24.2
unnamed: J5.3, R34.2
unnamed: Q1.1 (G), R28.1, R31.1
unnamed: Q2.1 (G), R29.1, R32.1
unnamed: R5.2, U2.2 (OUT)
unnamed: R6.2, U3.2 (OUT)
unnamed: R7.2, U4.2 (OUT)
unnamed: R8.2, U5.2 (OUT)
unnamed: R9.2, U6.2 (OUT)
unnamed: R10.2, U7.2 (OUT)
unnamed: R11.2, U8.2 (OUT)
unnamed: R12.2, U9.2 (OUT)
unnamed: R13.2, U11.2 (OUT)
unnamed: R14.2, U12.2 (OUT)
unnamed: R15.2, U13.2 (OUT)
unnamed: R16.2, U14.2 (OUT)
unnamed: R17.2, U15.2 (OUT)
unnamed: R18.2, U16.2 (OUT)
unnamed: R19.2, U17.2 (OUT)
unnamed: R20.2, U18.2 (OUT)
unnamed: R22.1, U10.8 (PD2)
unnamed: R23.1, U10.9 (PD3)
unnamed: R26.1, U20.9 (AD0)
unnamed: R30.2, R33.2, R35.2, SW3.1
unnamed: SW4.1, U19.8 (rst)
PB1: J2.4, U1.20 (PB1)
PB2: J2.3, U1.21 (PB2)
PB3: J2.2, U1.22 (PB3)
PB7: R36.2, U1.26 (PB7)
PRGB 1: SW5.1, U21.8 (6_OUT1D)
PRGB 2: SW6.1, U21.11 (9_OUT1C)
R: J4.5, U21.43 (32_OUT1B)
RESET: C4.1, C29.2, J2.1, R3.1, SW1.1 (A), SW1.2 (A), U1.30 (~RESET)
RESET2: J1.1, R4.2, U10.24 (PC1/~RESET)
RS: J4.9, U21.45 (34_DAT1_MISO2)
RX2LED: D1.1 (K), U10.11 (PD5)
RXD0: R23.2, U1.2 (PE0)
SCK: J4.10, U21.20 (13_SCK_CRX1_LED)
SCK2: J1.4, U10.15 (PB1)
SCL: J8.3, R1.2, R25.1, U1.43 (PD0), U20.23 (SCL)
SDA: J8.4, R2.2, R27.1, U1.44 (PD1), U20.24 (SDA)
Start: J4.3, U21.41 (30_CRX3)
Stop: J4.4, U21.42 (31_CTX3)
TX2LED: D2.1 (K), U10.10 (PD4)
TXD0: R22.2, U1.3 (PE1)
Teensy D+: J6.6, U21.54 (D+)
Teensy D-: J6.5, U21.53 (D-)
Touch: J3.4, U21.14 (12_MISO_MQSL)
XBee RX: J10.4, U21.36 (25_A11_RX6_SDA2)
XBee TX: J10.3, U21.35 (24_A10_TX6_SCL2)

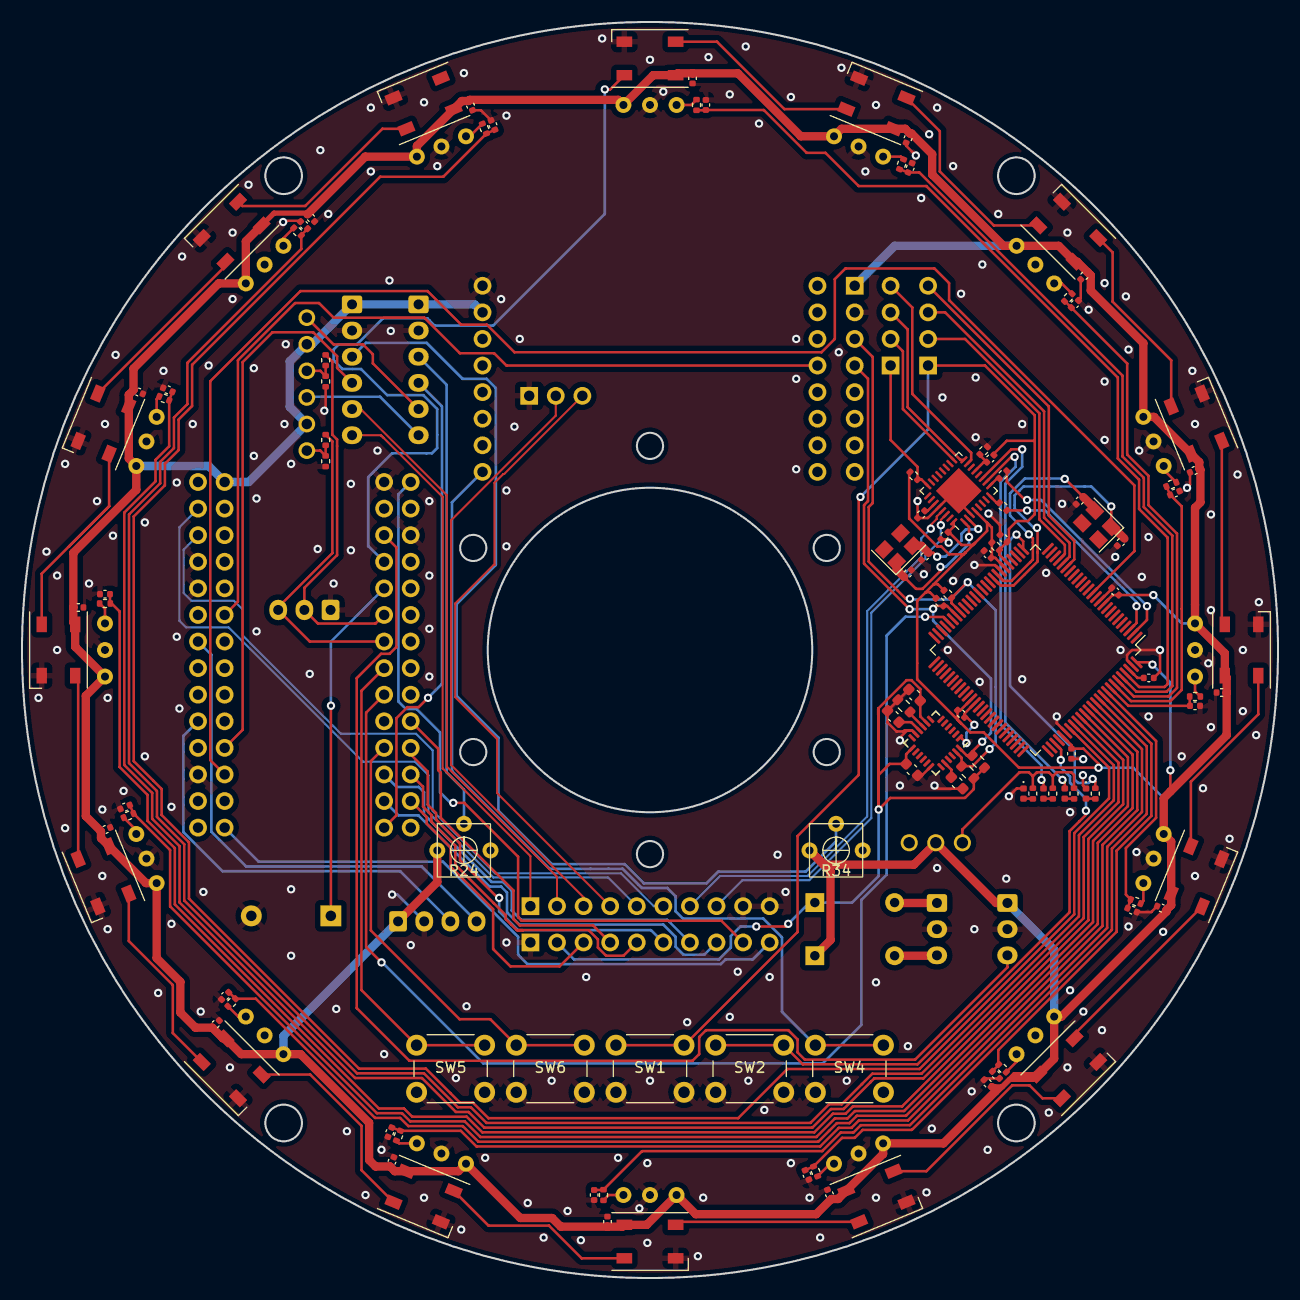
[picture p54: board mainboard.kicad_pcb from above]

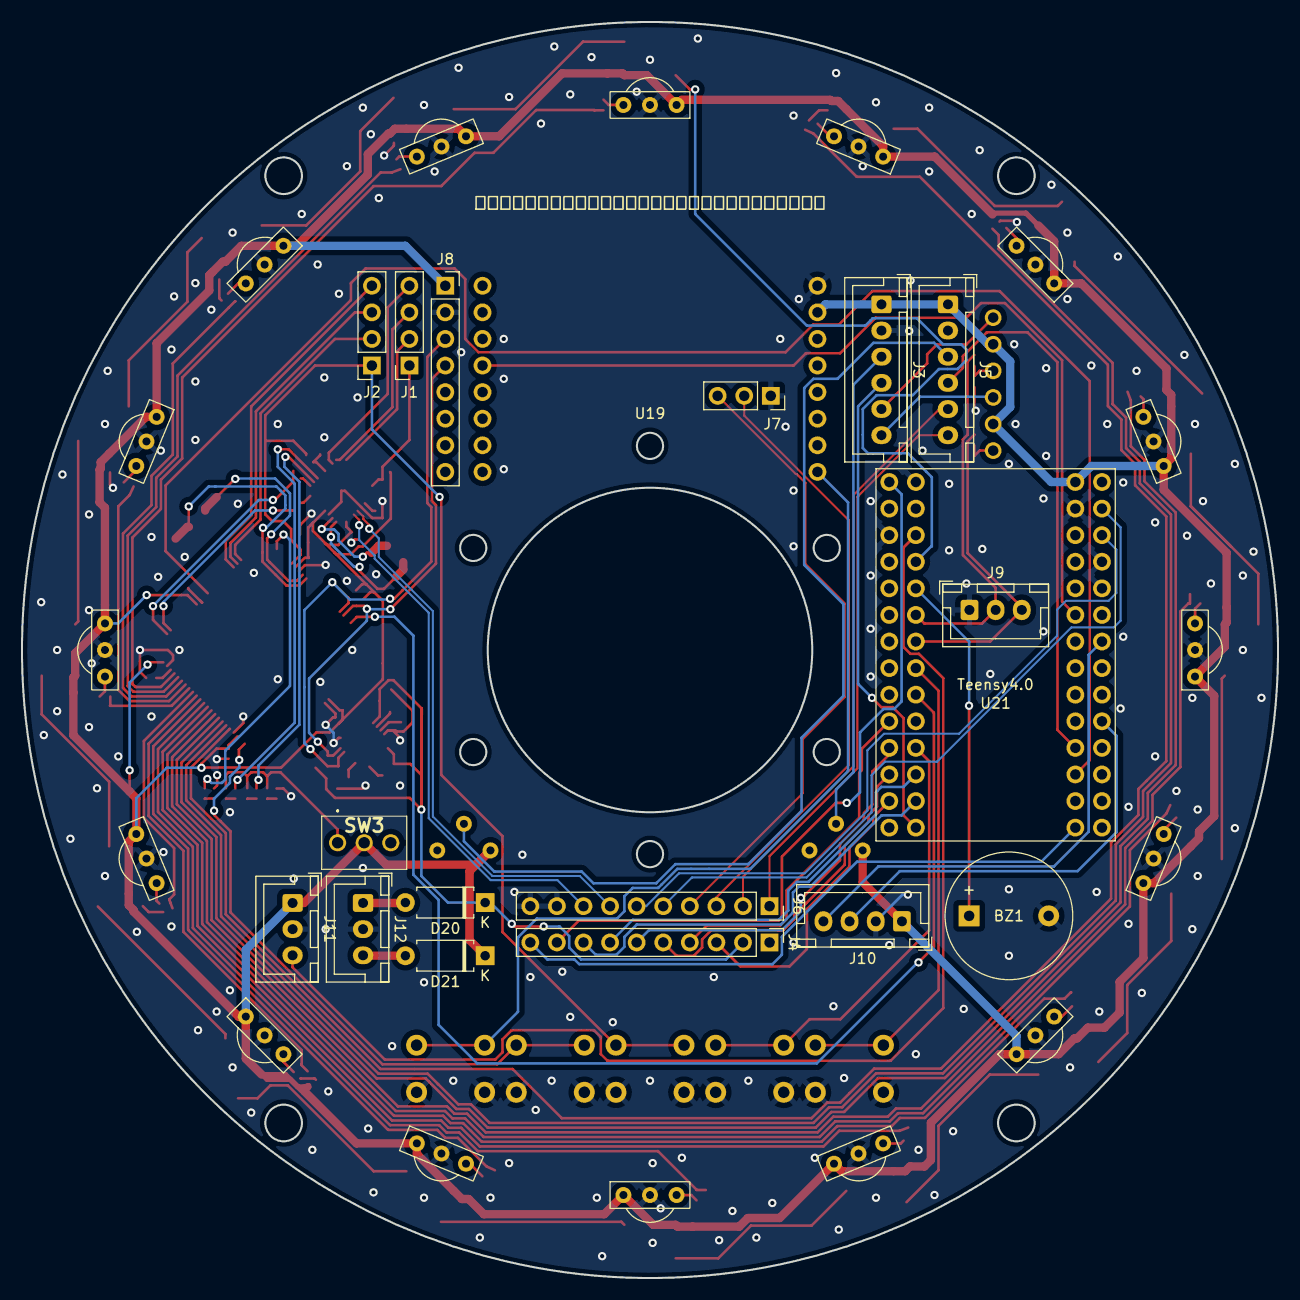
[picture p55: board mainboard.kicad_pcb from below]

Board: 2 copper layers, 120.0 x 120.0 mm, 151 parts (34 on the bottom side), 122 nets.

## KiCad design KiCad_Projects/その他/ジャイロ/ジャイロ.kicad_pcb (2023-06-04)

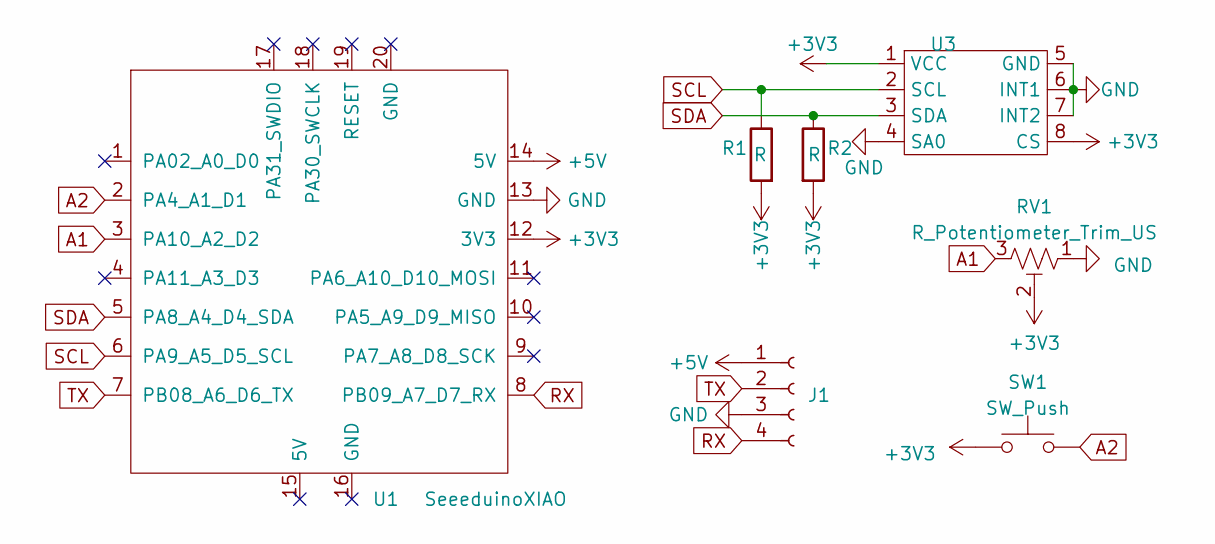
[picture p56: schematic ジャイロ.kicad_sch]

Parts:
J1: Conn_01x04_Socket; PinHeader_1x04_P2.54mm_Vertical
R1, R2: R; R_Axial_DIN0207_L6.3mm_D2.5mm_P7.62mm_Horizontal
RV1: R_Potentiometer_Trim_US; TA48033S
SW1: SW_Push; SW_PUSH_6mm_H7.3mm
U1: SeeeduinoXIAO; seeeduinoXIAO
U3: L3GD20H_Module

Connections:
+3V3: R1.2, R2.2, RV1.2, SW1.1, U1.12 (3V3), U3.1 (VCC), U3.8 (CS)
+5V: J1.1, U1.14 (5V)
A1: RV1.3, U1.3 (PA10_A2_D2)
A2: SW1.2, U1.2 (PA4_A1_D1)
GND: J1.3, RV1.1, U1.13 (GND), U3.4 (SA0), U3.5 (GND), U3.6 (INT1), U3.7 (INT2)
RX: J1.4, U1.8 (PB09_A7_D7_RX)
SCL: R1.1, U1.6 (PA9_A5_D5_SCL), U3.2 (SCL)
SDA: R2.1, U1.5 (PA8_A4_D4_SDA), U3.3 (SDA)
TX: J1.2, U1.7 (PB08_A6_D6_TX)

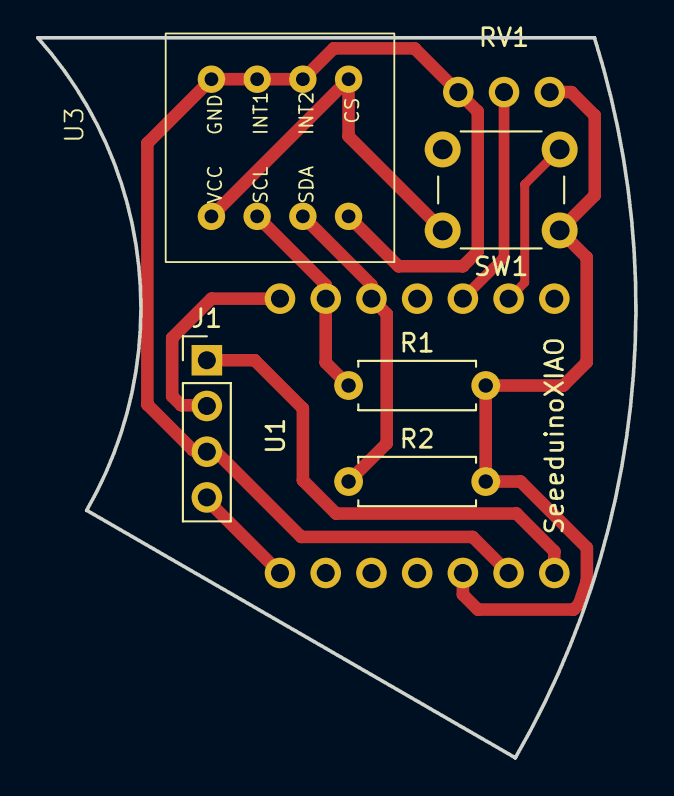
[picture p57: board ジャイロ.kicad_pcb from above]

Board: 2 copper layers, 33.2 x 40.0 mm, 7 parts (0 on the bottom side), 9 nets.

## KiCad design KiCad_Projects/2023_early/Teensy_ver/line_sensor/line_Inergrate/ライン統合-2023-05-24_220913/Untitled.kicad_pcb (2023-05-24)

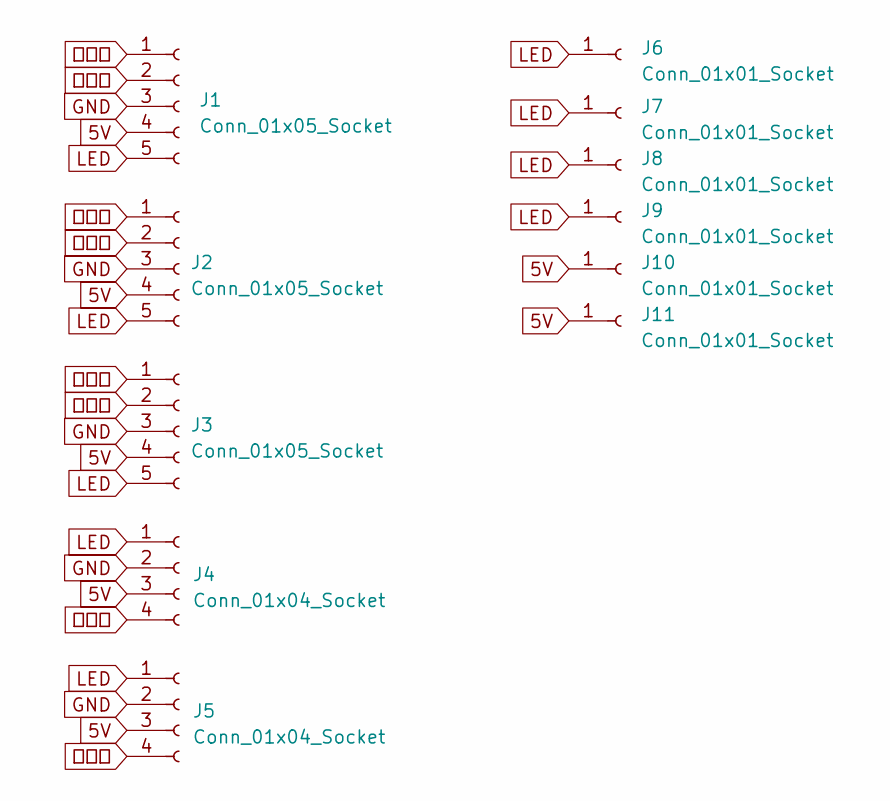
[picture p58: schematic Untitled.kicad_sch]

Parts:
J1, J2, J3: Conn_01x05_Socket; PinHeader_1x05_P2.54mm_Vertical
J4, J5: Conn_01x04_Socket; PinHeader_1x04_P2.54mm_Vertical
J6, J7, J8, J9, J10, J11: Conn_01x01_Socket; PinHeader_1x01_P2.54mm_Vertical

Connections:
5V: J1.4, J2.4, J3.4, J4.3, J5.3, J10.1, J11.1
GND: J1.3, J2.3, J3.3, J4.2, J5.2
LED: J1.5, J2.5, J3.5, J4.1, J5.1, J6.1, J7.1, J8.1, J9.1
信号線: J1.1, J1.2, J2.1, J2.2, J3.1, J3.2, J4.4, J5.4

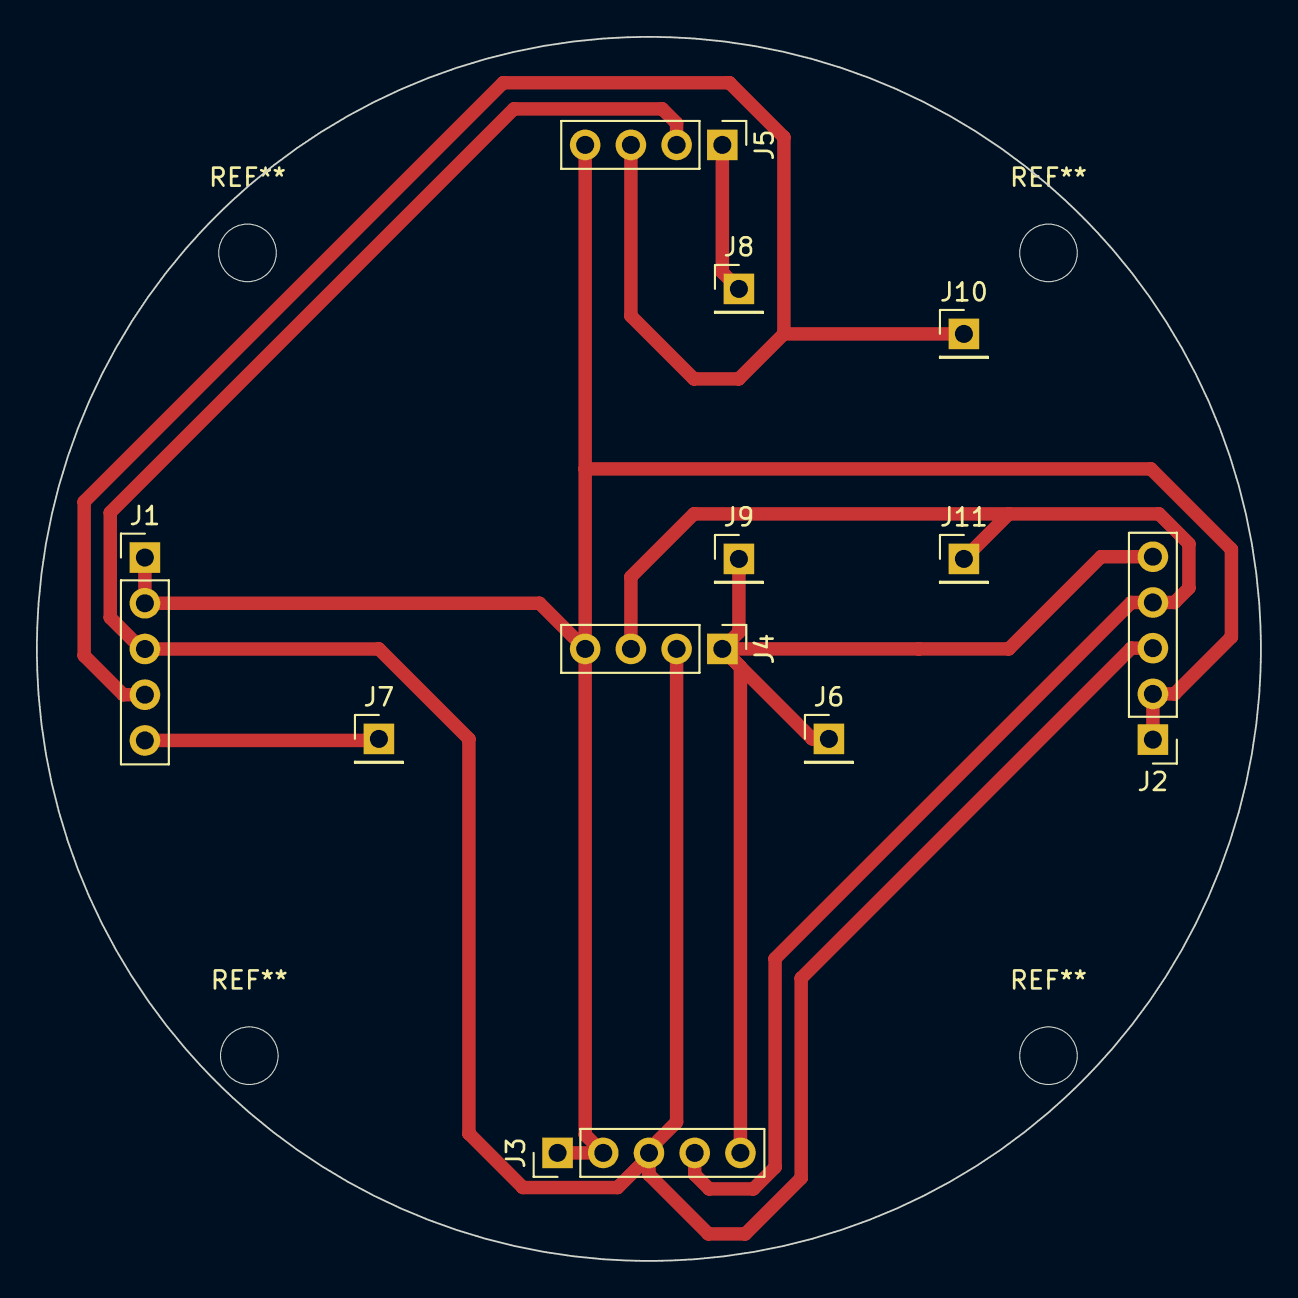
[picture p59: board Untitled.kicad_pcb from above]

Board: 2 copper layers, 68.0 x 68.0 mm, 11 parts (0 on the bottom side), 4 nets.

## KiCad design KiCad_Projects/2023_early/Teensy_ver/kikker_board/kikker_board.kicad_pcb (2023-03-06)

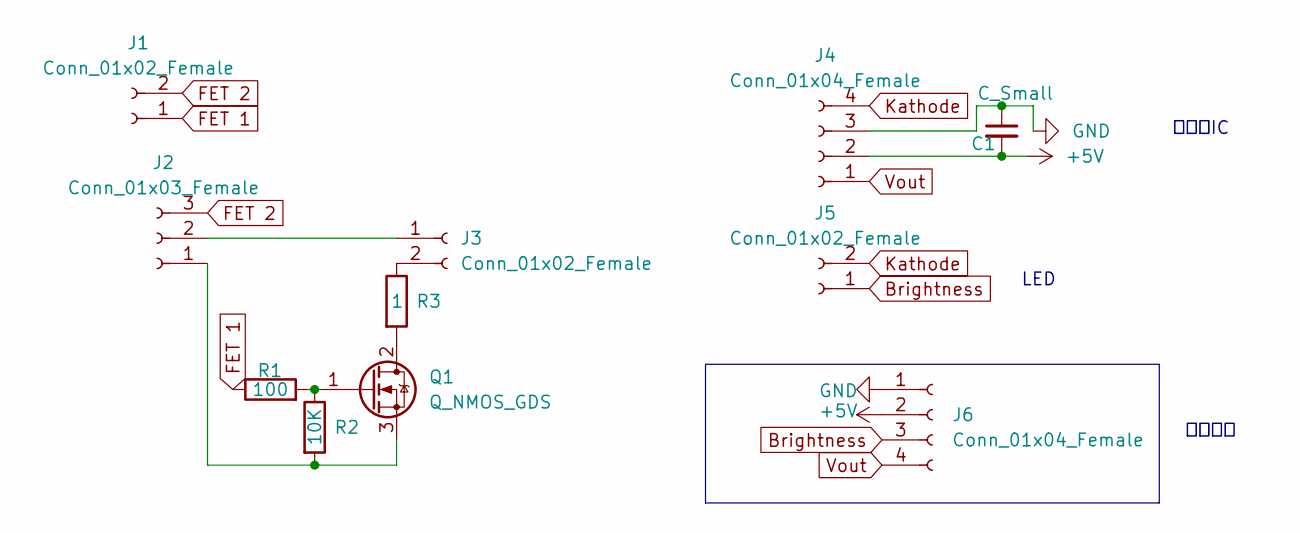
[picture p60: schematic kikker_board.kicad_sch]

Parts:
C1: C_Small; C_0402_1005Metric
J1, J3, J5: Conn_01x02_Female; JST_XH_B2B-XH-A_1x02_P2.50mm_Vertical
J2: Conn_01x03_Female; JST_XH_B3B-XH-A_1x03_P2.50mm_Vertical
J4, J6: Conn_01x04_Female; JST_XH_B4B-XH-A_1x04_P2.50mm_Vertical
Q1: Q_NMOS_GDS; FS70SMJ
R1: 100; R_Axial_DIN0204_L3.6mm_D1.6mm_P5.08mm_Horizontal
R2: 10K; R_Axial_DIN0204_L3.6mm_D1.6mm_P5.08mm_Horizontal
R3: 1; 5W 1Ω sement

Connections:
+5V: C1.2, J4.2, J6.2
Brightness: J5.1, J6.3
FET 1: J1.1, R1.1
FET 2: J1.2, J2.3
GND: C1.1, J4.3, J6.1
Kathode: J4.4, J5.2
unnamed: J2.1, Q1.3 (S), R2.2
unnamed: J2.2, J3.1
unnamed: J3.2, R3.1
unnamed: Q1.1 (G), R1.2, R2.1
unnamed: Q1.2 (D), R3.2
Vout: J4.1, J6.4

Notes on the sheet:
LED
メインへ
フォトIC

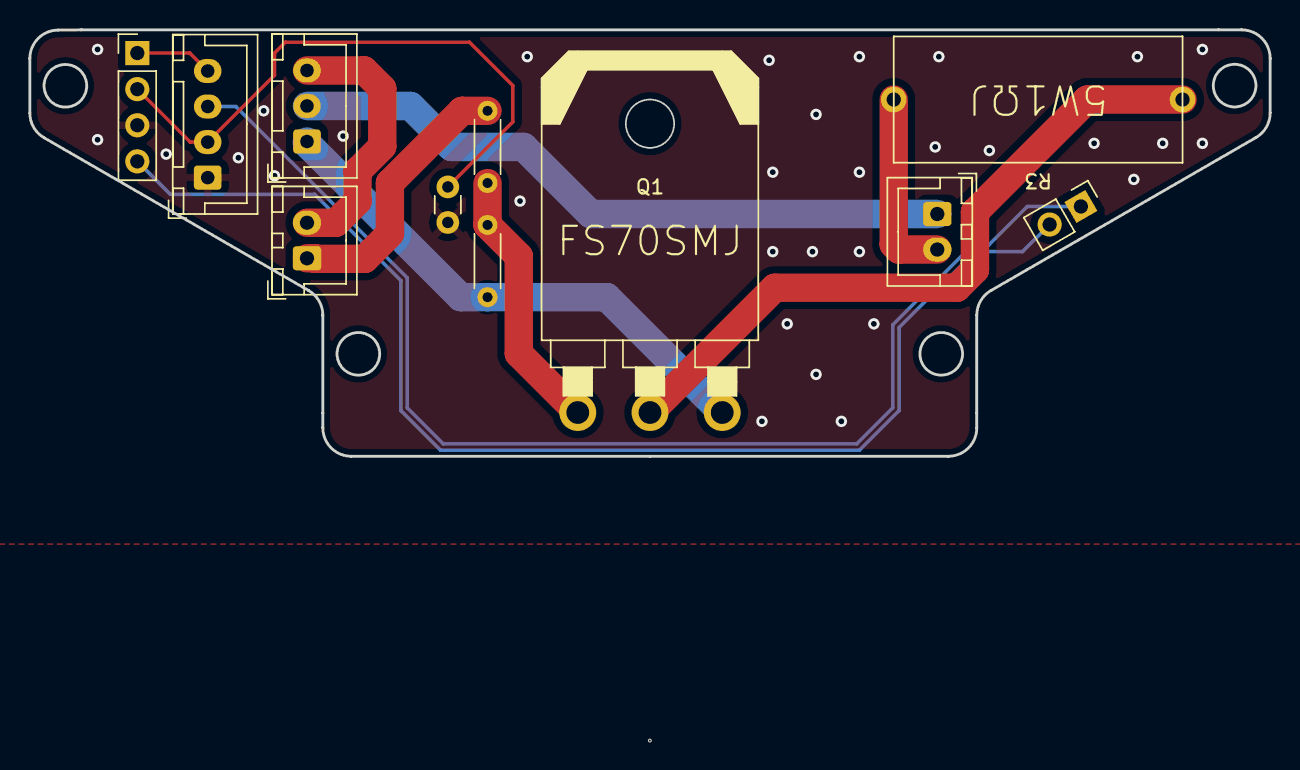
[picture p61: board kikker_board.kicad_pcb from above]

Board: 2 copper layers, 87.3 x 30.0 mm, 11 parts (0 on the bottom side), 12 nets.

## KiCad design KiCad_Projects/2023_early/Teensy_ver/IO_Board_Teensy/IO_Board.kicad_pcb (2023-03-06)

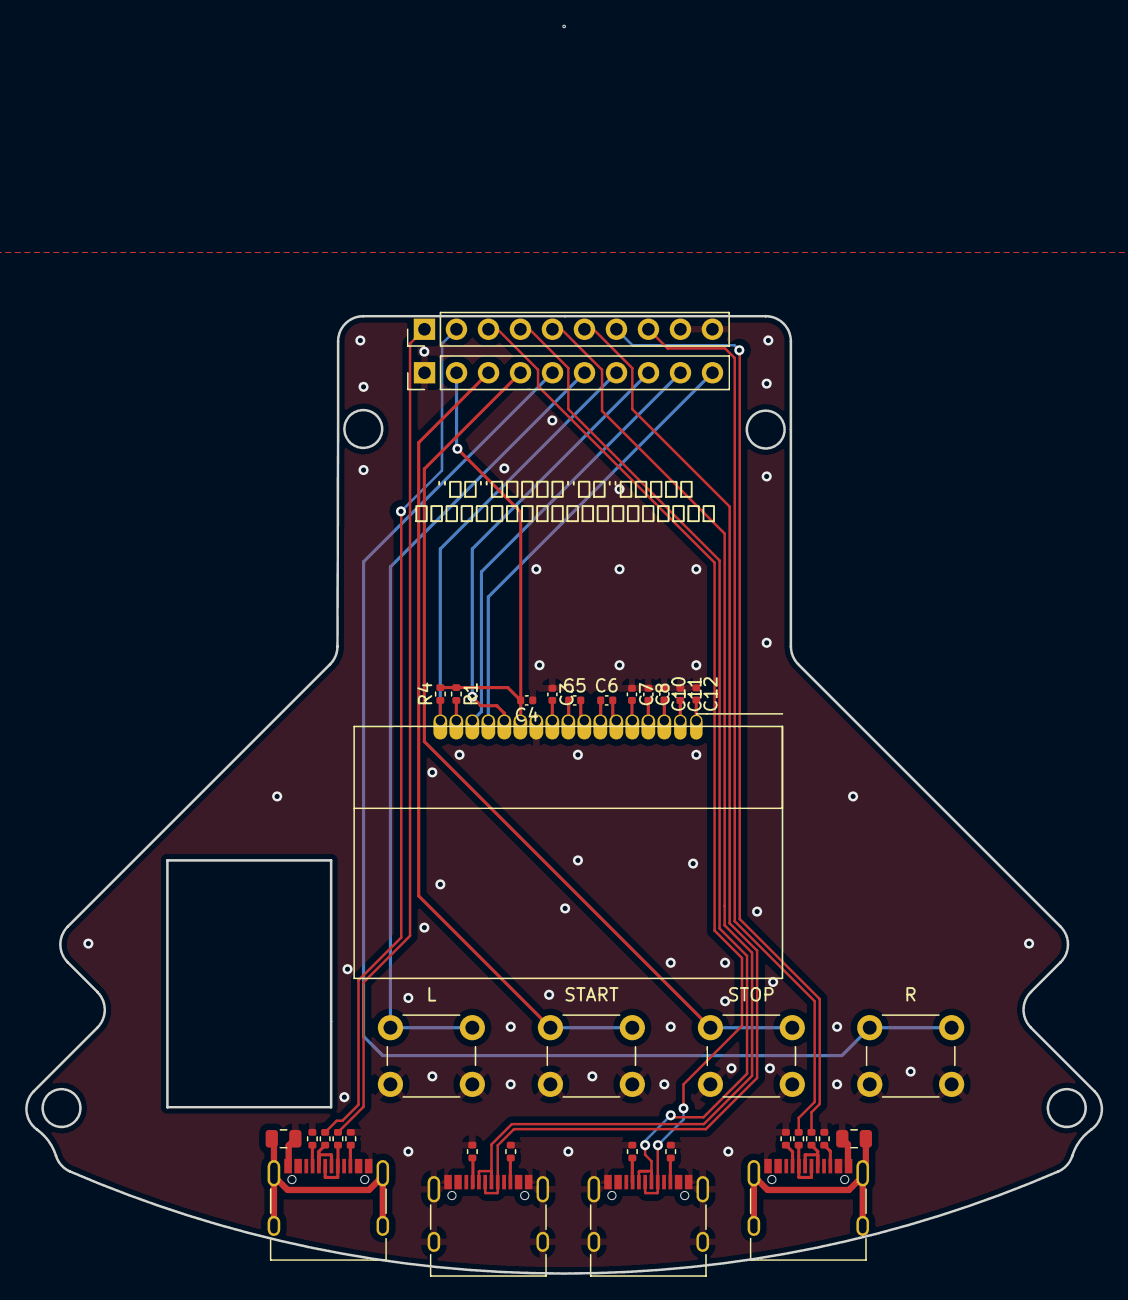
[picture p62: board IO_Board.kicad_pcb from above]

Board: 2 copper layers, 85.4 x 76.0 mm, 36 parts (0 on the bottom side), 43 nets.

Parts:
C3, C4, C5, C6, C7, C8, C10, C11, C12: C_Small; C_0402_1005Metric
FB1, FB2: Ferrite_Bead; Fuse_0805_2012Metric
J1, J2, J4, J7: USB_C_Receptacle_USB2.0; USB_C_Receptacle_XKB_U262-16XN-4BVC11
J3, J5: Conn_01x10_Female; PinHeader_1x10_P2.54mm_Vertical
J6: Conn_01x17_Female; LCDmodule_aqm1248a
L: SW_DIP_x01; SW_PUSH_6mm_H5mm
R: SW_DIP_x01; SW_PUSH_6mm_H5mm
R1, R4: 10K; R_0402_1005Metric
R2, R3, R6, R7, R8, R9, R12, R13: R; R_0402_1005Metric
R5, R10, R11, R14: 22R; R_0402_1005Metric
START: SW_DIP_x01; SW_PUSH_6mm_H5mm
STOP: SW_DIP_x01; SW_PUSH_6mm_H5mm

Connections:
+3V3: C4.2, J3.2, J6.6, R1.1, R4.2
CS: J3.7, J6.1, R4.1
Cam D+: J4.A6 (D+), J4.B6 (D+), J5.3
Cam D-: J4.A7 (D-), J4.B7 (D-), J5.4
GND: C3.1, C4.1, C7.1, C8.1, C10.1, C11.1, C12.1, FB1.1, FB2.1, J1.A1 (GND), J1.A12 (GND), J1.B1 (GND), J1.B12 (GND), J1.S1 (SHIELD), J2.A1 (GND), J2.A12 (GND), J2.B1 (GND), J2.B12 (GND), J3.1, J4.A1 (GND), J4.A12 (GND), J4.B1 (GND), J4.B12 (GND), J4.S1 (SHIELD), J5.9, J5.10, J6.7, J7.A1 (GND), J7.A12 (GND), J7.B1 (GND), J7.B12 (GND), L.1, R.1, R2.2, R3.2, R6.2, R7.2, R8.1, R9.1, R12.1, R13.1, START.1, STOP.1
IR D+: J5.7, R5.1
IR D-: J5.8, R10.1
L: J3.6, L.2
Line D+: J5.1, R11.1
Line D-: J5.2, R14.1
MOSI: J3.8, J6.5
unnamed: C3.2, J6.8
unnamed: C5.1, J6.9
unnamed: C5.2, J6.10
unnamed: C6.1, J6.11
unnamed: C6.2, J6.12
unnamed: C7.2, J6.13
unnamed: C8.2, J6.14
unnamed: C10.2, J6.15
unnamed: C11.2, J6.16
unnamed: C12.2, J6.17
unnamed: FB1.2, J2.S1 (SHIELD)
unnamed: FB2.2, J7.S1 (SHIELD)
unnamed: J1.A5 (CC1), R2.1
unnamed: J1.B5 (CC2), R3.1
unnamed: J2.A5 (CC1), R8.2
unnamed: J2.A6 (D+), J2.B6 (D+), R5.2
unnamed: J2.A7 (D-), J2.B7 (D-), R10.2
unnamed: J2.B5 (CC2), R9.2
unnamed: J4.A5 (CC1), R6.1
unnamed: J4.B5 (CC2), R7.1
unnamed: J6.2, R1.2
unnamed: J7.A5 (CC1), R12.2
unnamed: J7.A6 (D+), J7.B6 (D+), R11.2
unnamed: J7.A7 (D-), J7.B7 (D-), R14.2
unnamed: J7.B5 (CC2), R13.2
R: J3.5, R.2
RS: J3.9, J6.3
SCK: J3.10, J6.4
Start: J3.3, START.2
Stop: J3.4, STOP.2
Teensy D+: J1.A6 (D+), J1.B6 (D+), J5.6
Teensy D-: J1.A7 (D-), J1.B7 (D-), J5.5

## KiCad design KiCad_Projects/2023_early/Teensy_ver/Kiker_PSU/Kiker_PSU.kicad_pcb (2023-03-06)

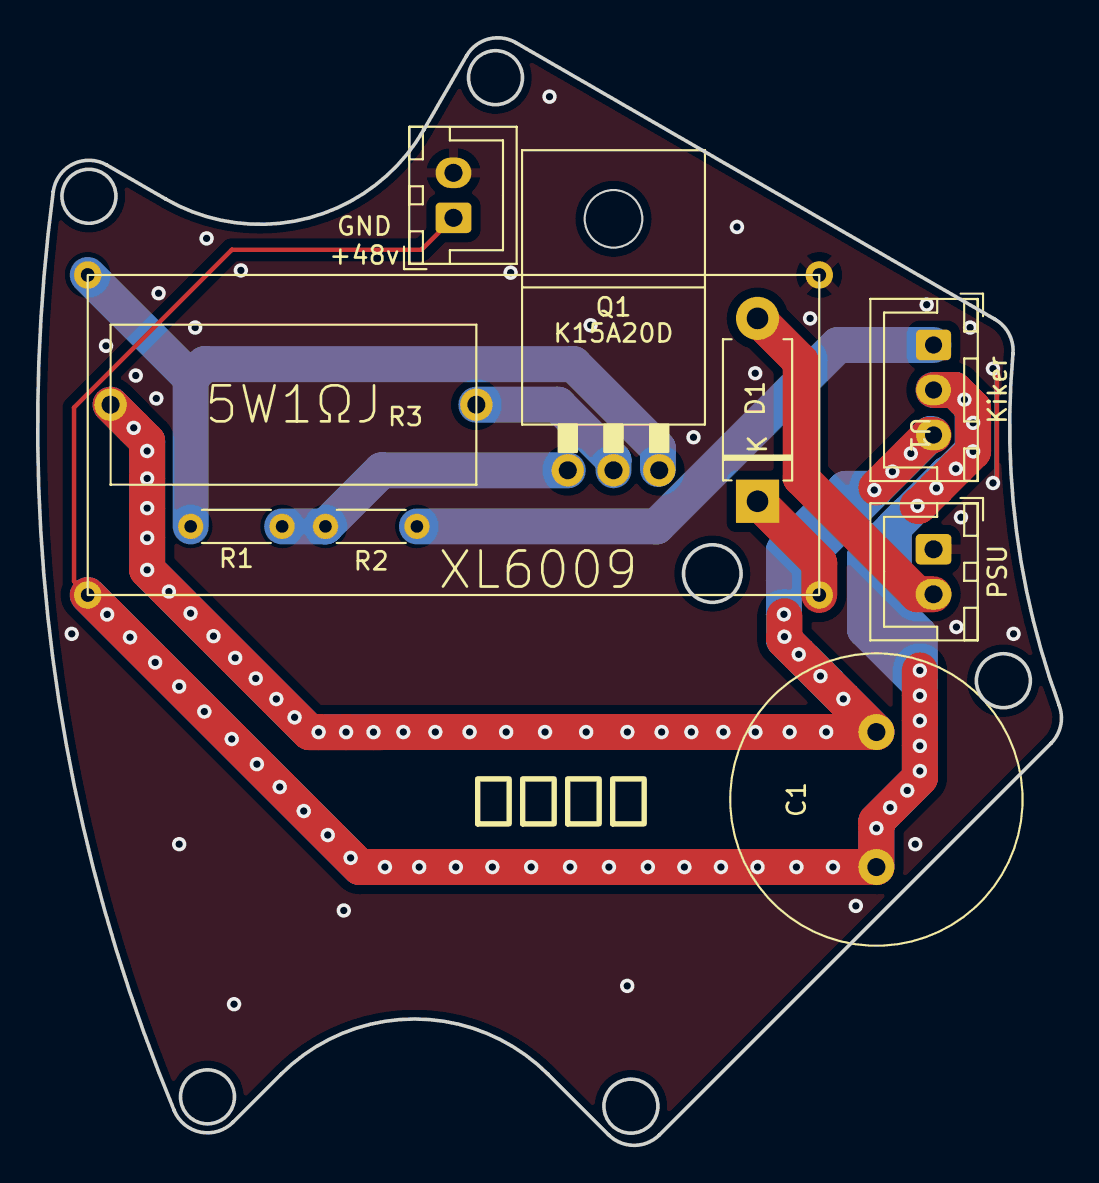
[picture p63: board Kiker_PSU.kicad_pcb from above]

Board: 2 copper layers, 56.9 x 61.5 mm, 9 parts (0 on the bottom side), 9 nets.

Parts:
C1: 4700; C_Radial_D16.0mm_H31.5mm_P7.50mm
D1: D; D_DO-15_P10.16mm_Horizontal
Kiker: Conn_01x03_Female; JST_XH_B3B-XH-A_1x03_P2.50mm_Vertical
PSU: Conn_01x02_Female; JST_XH_B2B-XH-A_1x02_P2.50mm_Vertical
Q1: Q_NMOS_GDS; K15A20D
R1: 10K; R_Axial_DIN0204_L3.6mm_D1.6mm_P5.08mm_Horizontal
R2: 100; R_Axial_DIN0204_L3.6mm_D1.6mm_P5.08mm_Horizontal
R3: 1; 5W 1Ω sement
U1: XL6009

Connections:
+12V: D1.1 (K), U1.1 (IN+)
GND: PSU.1, U1.2 (IN-)
unnamed: C1.1, Kiker.2, U1.3 (OUT+)
unnamed: C1.2, Kiker.3, R3.1
unnamed: D1.2 (A), PSU.2
unnamed: Kiker.1, R2.1
unnamed: Q1.1 (G), R1.2, R2.2
unnamed: Q1.2 (D), R3.2
unnamed: Q1.3 (S), R1.1, U1.4 (OUT-)

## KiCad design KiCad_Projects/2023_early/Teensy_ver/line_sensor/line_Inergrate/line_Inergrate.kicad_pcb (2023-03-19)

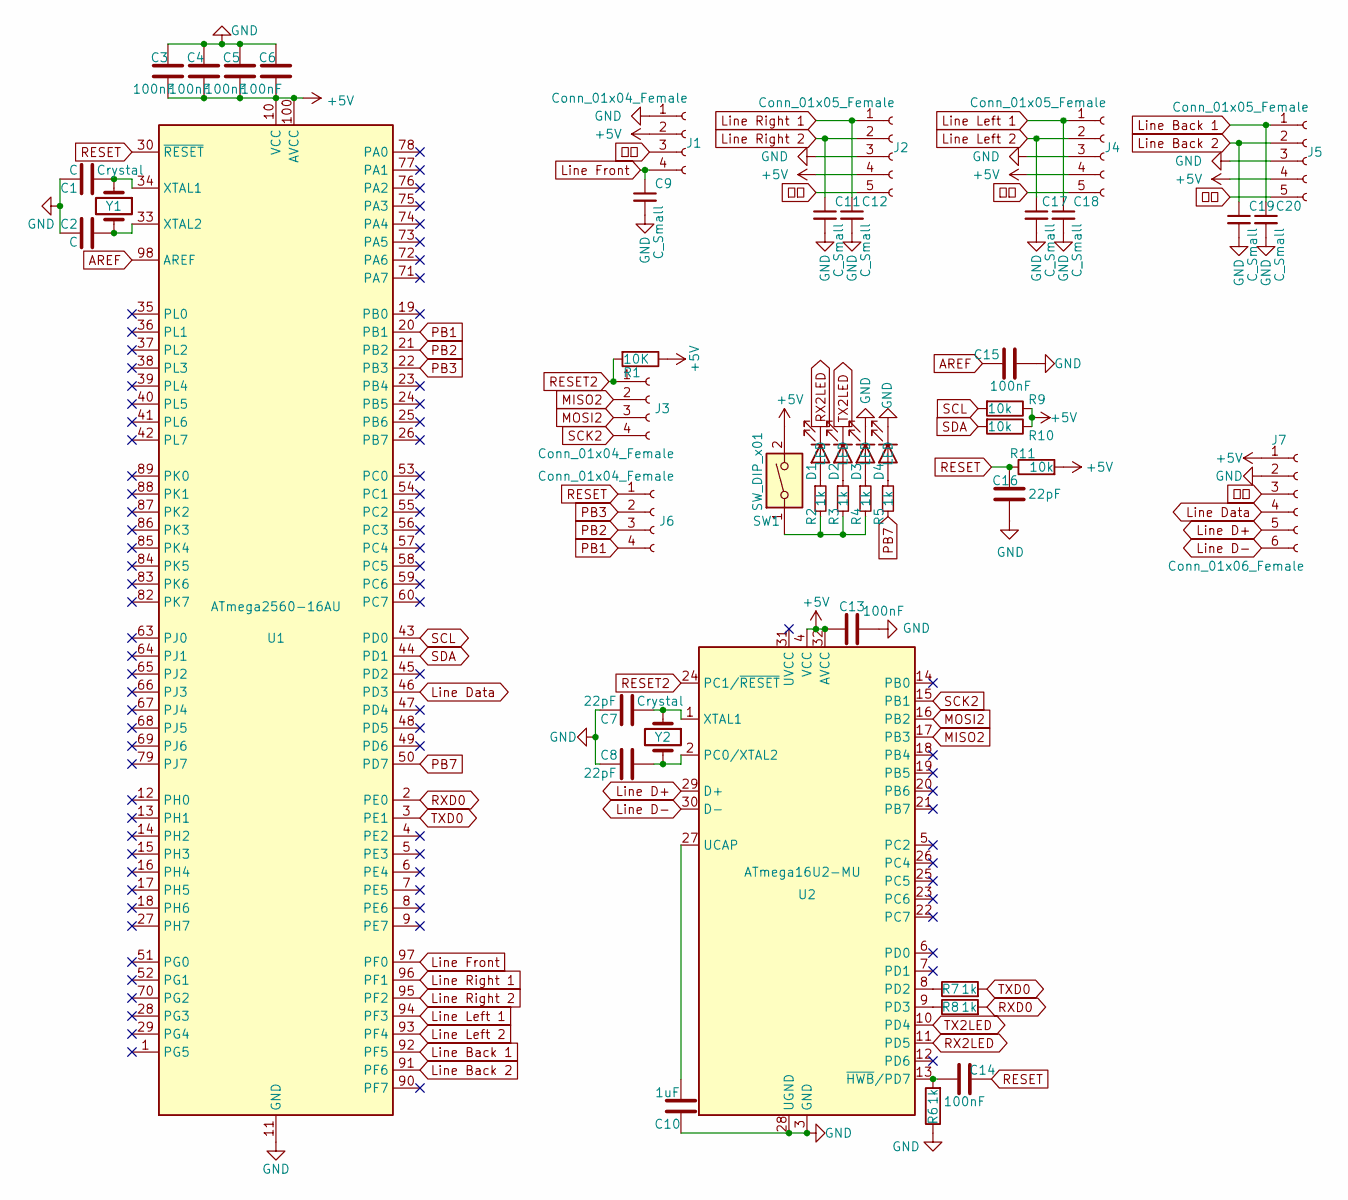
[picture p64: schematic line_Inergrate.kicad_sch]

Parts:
C1, C2: C; C_0402_1005Metric; LCSC C1555
C3, C4, C5, C6, C13, C14, C15: 100nF; C_0402_1005Metric; LCSC C41851
C7, C8, C16: 22pF; C_0402_1005Metric; LCSC C1555
C9, C11, C12, C17, C18, C19, C20: C_Small; C_Disc_D3.0mm_W1.6mm_P2.50mm
C10: 1uF; C_0402_1005Metric; LCSC C167339
D1, D2, D3, D4: LED; LED_0402_1005Metric; LCSC C130725
J1: Conn_01x04_Female; PinSocket_1x04_P2.54mm_Horizontal
J2, J4, J5: Conn_01x05_Female; PinSocket_1x05_P2.54mm_Horizontal
J3, J6: Conn_01x04_Female; PinSocket_1x04_P2.54mm_Vertical
J7: Conn_01x06_Female; JST_XH_B6B-XH-A_1x06_P2.50mm_Vertical
R1: 10K; R_0402_1005Metric; LCSC C25744
R2, R3, R4, R5: 1k; R_0402_1005Metric; LCSC C11702
R6, R7, R8: 1k; R_0402_1005Metric; LCSC C105637
R9, R10, R11: 10k; R_0402_1005Metric; LCSC C25744
SW1: SW_DIP_x01; 2MS1T2B4M2QES
U1: ATmega2560-16AU; TQFP-100_14x14mm_P0.5mm
U2: ATmega16U2-MU; QFN-32-1EP_5x5mm_P0.5mm_EP3.1x3.1mm
Y1, Y2: Crystal; Crystal_SMD_3225-4Pin_3.2x2.5mm; LCSC C164049

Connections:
Line Left 1: C18.1, J4.1, U1.94 (PF3)
+5V: C3.2, C4.2, C5.2, C6.2, C13.2, J1.2, J2.4, J4.4, J5.4, J7.1, R1.1, R9.1, R10.1, R11.2, SW1.2, U1.10 (VCC), U1.31 (VCC), U1.61 (VCC), U1.80 (VCC), U1.100 (AVCC), U2.4 (VCC), U2.32 (AVCC)
AREF: C15.1, U1.98 (AREF)
GND: C1.2, C2.2, C3.1, C4.1, C5.1, C6.1, C7.2, C8.2, C9.2, C10.2, C11.2, C12.2, C13.1, C15.2, C16.2, C17.2, C18.2, C19.2, C20.2, D3.1 (K), D4.1 (K), J1.1, J2.3, J4.3, J5.3, J7.2, R6.1, U1.11 (GND), U1.32 (GND), U1.62 (GND), U1.81 (GND), U1.99 (GND), U2.3 (GND), U2.28 (UGND), U2.33 (GND)
Line Back 1: C20.1, J5.1, U1.92 (PF5)
Line Back 2: C19.1, J5.2, U1.91 (PF6)
Line D+: J7.5, U2.29 (D+)
Line D-: J7.6, U2.30 (D-)
Line Data: J7.4, U1.46 (PD3)
Line Front: C9.1, J1.4, U1.97 (PF0)
Line Left 2: C17.1, J4.2, U1.93 (PF4)
Line Right 1: C12.1, J2.1, U1.96 (PF1)
Line Right 2: C11.1, J2.2, U1.95 (PF2)
MISO2: J3.2, U2.17 (PB3)
MOSI2: J3.3, U2.16 (PB2)
unnamed: C1.1, U1.34 (XTAL1), Y1.1
unnamed: C2.1, U1.33 (XTAL2), Y1.2
unnamed: C7.1, U2.1 (XTAL1), Y2.1
unnamed: C8.1, U2.2 (PC0/XTAL2), Y2.2
unnamed: C10.1, U2.27 (UCAP)
unnamed: C14.1, R6.2, U2.13 (~HWB/PD7)
unnamed: D1.2 (A), R2.1
unnamed: D2.2 (A), R3.1
unnamed: D3.2 (A), R4.1
unnamed: D4.2 (A), R5.1
unnamed: R2.2, R3.2, R4.2, SW1.1
unnamed: R7.1, U2.8 (PD2)
unnamed: R8.1, U2.9 (PD3)
PB1: J6.4, U1.20 (PB1)
PB2: J6.3, U1.21 (PB2)
PB3: J6.2, U1.22 (PB3)
PB7: R5.2, U1.50 (PD7)
RESET: C14.2, C16.1, J6.1, R11.1, U1.30 (~RESET)
RESET2: J3.1, R1.2, U2.24 (PC1/~RESET)
RX2LED: D1.1 (K), U2.11 (PD5)
RXD0: R8.2, U1.2 (PE0)
SCK2: J3.4, U2.15 (PB1)
SCL: R9.2, U1.43 (PD0)
SDA: R10.2, U1.44 (PD1)
TX2LED: D2.1 (K), U2.10 (PD4)
TXD0: R7.2, U1.3 (PE1)
可変: J1.3, J2.5, J4.5, J5.5, J7.3


Board: 2 copper layers, 68.0 x 68.0 mm, 46 parts (0 on the bottom side), 42 nets.

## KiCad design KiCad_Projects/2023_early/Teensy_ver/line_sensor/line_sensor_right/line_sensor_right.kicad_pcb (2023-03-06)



Board: 2 copper layers, 61.2 x 76.8 mm, 19 parts (6 on the bottom side), 11 nets.

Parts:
C1, C3, C4, C5, C6, C7: C_Small; C_0402_1005Metric
D1, D3, D4, D5, D6, D7: LED; LED_D3.0mm_Clear
J1: Conn_01x05_Female; PinHeader_1x05_P2.54mm_Horizontal
U1, U3, U4, U5, U6, U7: Line_sennsor

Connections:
+5V: C1.2, C3.2, C4.2, C5.2, C6.2, C7.2, J1.2, U1.2 (VCC), U3.2 (VCC), U4.2 (VCC), U5.2 (VCC), U6.2 (VCC), U7.2 (VCC)
GND: C1.1, C3.1, C4.1, C5.1, C6.1, C7.1, J1.3, U1.4 (GND), U3.4 (GND), U4.4 (GND), U5.4 (GND), U6.4 (GND), U7.4 (GND)
Line Data 1: J1.4, U1.3 (VOUT), U3.3 (VOUT), U5.3 (VOUT)
Line Data 2: J1.5, U4.3 (VOUT), U6.3 (VOUT), U7.3 (VOUT)
unnamed: D1.1 (K), U1.1 (K(-))
unnamed: D3.1 (K), U3.1 (K(-))
unnamed: D4.1 (K), U4.1 (K(-))
unnamed: D5.1 (K), U5.1 (K(-))
unnamed: D6.1 (K), U6.1 (K(-))
unnamed: D7.1 (K), U7.1 (K(-))
R Trim: D1.2 (A), D3.2 (A), D4.2 (A), D5.2 (A), D6.2 (A), D7.2 (A), J1.1

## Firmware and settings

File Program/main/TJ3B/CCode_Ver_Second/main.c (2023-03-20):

//--------------------------------------------------------------------------------
// Title: Main - [ main.c ]
// Build:DAISEN C-Style for TJ3B  [ Ver.20190706 ] - [  ...  ]
//--------------------------------------------------------------------------------
// SetupVal:111111-111110-000002,cmt:
// CN01:Ball
// CN02:Line
// CN03:L-Touch
// CN04:R-Touch
// CN05:C-Touch
// CN06:
// CN07:
// CN08:
// CN09:
// CN10:
//--------------------------------------------------------------------------------
#include "D_Main.h"
#include "D_I2C.h"
#include "D_SIO.h"
#include "D_EIO.h"
//--------------------------------------------------------------------------------
#include "D_Main.h"
#include "D_I2C.h"
#include "D_SIO.h"
#include "D_EIO.h"
//--------------------------------------------------------------------------------

#define GAIN_P 0.15
#define GAIN_I 1
#define GAIN_D 1

#define MOTOR_LIMIT 60
#define PID_LIMIT 13

#define IR_MAX 576.0

#define PI 3.14159

//センサー読み取り関数
void Read_Sensors();

//モーター制御系関数
void Move(int Deg, int Power);
void Move_Power(int MotorA, int MotorB, int MotorC, int MotorD);

//姿勢制御系関数
void Calc_PID(BOOL bDecide);
void Calc_GoalPID(BOOL bDecide);

//ボール追いかけスピード計算
int Calc_MotorSpeed(void);

//max
int max(int a, int b);

//ボールセンサ系統変数格納
int IR_Value;
int IR_Distance;

//カメラ系統変数格納
int Court_Deg;
int Goal_Deg;
int Goal_Distance;

//その他各種センサ変数格納
int Line_Val;
int Gyro_Deg;
int Touch_Val;

//PID制御関連
int Operation_P;
int Operation_I;
int Operation_D;      //各要素ごとの操作量
int deviation;
int deviation_old;   //現在、前回の角度差
int deviation_goal;
int deviation_old_goal;   //現在、前回の角度差
int Operation_PID;
int val_P;
int val_I;
int val_D;

int PID_Type;

BOOL bMove_Line;

//モーターの値を格納
int Motors_Power[4];  //それぞれ1ch~4chを表す
  
int max(int a, int b)
{
  return a >= b ? a : b;
}

//上下限を丸め込む関数
int RemoveHighLow(int value, int High, int Low){
  if(value > High)
    return High;
  else if(value < Low)
    return Low;
    
  return value;
}

void Read_Sensors(){
  //ボールセンサ系統変数格納
  IR_Value = gAD[CN1];
  IR_Distance = gAD[CN2];

  //カメラ系統変数格納
  Court_Deg = gAD[CN3];
  Goal_Deg = gAD[CN4] - 180;
  Goal_Distance = gAD[CN5];

  //その他各種センサ変数格納
  Line_Val = gAD[CN6];
  Gyro_Deg = gAD[CN7];
}

//角度・速度でモーターを動かす
void Move(int Deg, int Power){
  double motor_max;
  double power_per;
  
  Motors_Power[0] = sin((Deg - 60) * PI / 180) * -Power;
  Motors_Power[1] = sin((Deg + 60) * PI / 180) * Power;
  Motors_Power[2] = sin((Deg - 135) * PI / 180) * -Power;
  Motors_Power[3] = sin((Deg + 135) * PI / 180) * Power;
  
  /*
  int i;
  for(i = 0; i < 4; i++) {
    int compare_val = Motors_Power[i] < 0 ? Motors_Power[i] * -1 : Motors_Power[i];
    if(compare_val > motor_max) {
      motor_max = compare_val;
    }
  }
  
  power_per = Power / motor_max;
  
  int j;
  for(j = 0; j < 4; j++) {
    Motors_Power[i] = Motors_Power[i] * power_per;
  }
  */
  
  Move_Power(Motors_Power[0], Motors_Power[1], Motors_Power[2], Motors_Power[3]);
}

//各モーターの値を代入してモーターを動かす
void Move_Power(int MotorA, int MotorB, int MotorC, int MotorD){
  int Motors[4];
    
  Motors[0] = MotorA;
  Motors[0] = RemoveHighLow(Motors[0], MOTOR_LIMIT, -MOTOR_LIMIT);
  Motors[0] += Operation_PID;
  Motors[1] = MotorB;
  Motors[1] = RemoveHighLow(Motors[1], MOTOR_LIMIT, -MOTOR_LIMIT);
  Motors[1] -= Operation_PID;
  Motors[2] = MotorC;
  Motors[2] = RemoveHighLow(Motors[2], MOTOR_LIMIT, -MOTOR_LIMIT);
  Motors[2] += Operation_PID;
  Motors[3] = MotorD;
  Motors[3] = RemoveHighLow(Motors[3], MOTOR_LIMIT, -MOTOR_LIMIT);
  Motors[3] -= Operation_PID;

  gPwm[0] = Motors[0] < 0 ? (Motors[0] * -1) | 0x80 : Motors[0];
  gPwm[1] = Motors[1] < 0 ? (Motors[1] * -1) | 0x80 : Motors[1];
  gPwm[2] = Motors[2] < 0 ? (Motors[2] * -1) | 0x80 : Motors[2];
  gPwm[3] = Motors[3] < 0 ? (Motors[3] * -1) | 0x80 : Motors[3];
  pwm_out();
}

//PID制御の計算
void Calc_PID(BOOL bDecide){
  PID_Type = 0;
  val_P = Gyro_Deg;

  if(val_P > 420){
    val_P = val_P - 840;
  }
  
  val_P = val_P * 2;

  deviation = 0 - Gyro_Deg;
  val_D = deviation - deviation_old;
  deviation_old = deviation;
  
  if(bDecide) {
    Operation_P = val_P * GAIN_P;
    Operation_I = 0 * GAIN_I;
    Operation_D = val_D * GAIN_D;
  
    Operation_PID = Operation_P + Operation_I + Operation_D;
    Operation_PID = RemoveHighLow(Operation_PID, PID_LIMIT, -PID_LIMIT);
  }
}

void Calc_GoalPID(BOOL bDecide) {
  PID_Type = 1;
  val_P = Goal_Deg * 1.3;
  if(val_P > 400){
    val_P = val_P - 800;
  }
  deviation = 0 - val_P;
  val_D = deviation - deviation_old;
  deviation_old = deviation;
      
  if(bDecide) {
      Operation_PID = val_P * 0.08 + val_D * 0;
    Operation_PID = -RemoveHighLow(Operation_PID, PID_LIMIT, -PID_LIMIT);
  }
}

int Calc_MotorSpeed(){
  int ret = 50;
  if(Court_Deg >= 500)
     ret = 30;
  else if(Court_Deg >= 320)
         ret = 35;
  return ret;
}

void user_main(void)
{
  while(TRUE){
    int move_deg;
    int move_speed;
        
    Read_Sensors();
    
          Calc_PID(true);
    //ラインセンサ処理
    if(Line_Val <= 50) {
      if(!bMove_Line) {
        clr_timer(0);
        bMove_Line = true;
      }
    }
    
    if(get_timer(T1) <= 500){
        gPwm[0] = 0x00 | 0x80;
        gPwm[1] = 0x00 | 0x80;
        gPwm[2] = 0x00 | 0x80;
        gPwm[3] = 0x00 | 0x80;
        pwm_out();
    }
    else {
      bMove_Line = false;
      
      if(IR_Value < 800) {
          if(IR_Value < 60 || IR_Value > 710) {
                       Move(0, Calc_MotorSpeed());
          }
          else if(IR_Value < 140)
          {
            int adddeg = 90 - ((450 - (IR_Distance - 300)) / 300.0 * 45);  
            if(adddeg < 20) adddeg = 20;
            move_deg = (IR_Value / 750.0 * 360.0) + adddeg;
            Move(move_deg, Calc_MotorSpeed());
          }
          else if(IR_Value < 400)
          {
              if(IR_Value < 340) 
              {
                int adddeg = 90 - ((450 - (IR_Distance - 300)) / 300.0 * 90);  
                if(adddeg < 20) adddeg = 20;
                move_deg = (IR_Value / 750.0 * 360.0) + adddeg;
                Move(move_deg, Calc_MotorSpeed());
              } 
              else 
              {
                Move(270, Calc_MotorSpeed());
              }
          }
          else
          {
              if(IR_Value < 460) 
              {
                Move(90, Calc_MotorSpeed());
              } 
              else
              {
                int adddeg = 90 - ((450 - (IR_Distance - 300)) / 300.0 * 90); 
                if(adddeg < 20) adddeg = 20;
                move_deg = (IR_Value / 750.0 * 360.0) - adddeg;
                Move(move_deg, Calc_MotorSpeed());
              }
          }
      }
      else {
        Move(0, 0);
      }
    }
  }
}

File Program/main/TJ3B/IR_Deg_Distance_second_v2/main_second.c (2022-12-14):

//--------------------------------------------------------------------------------
// Title: Main - [ main_second ]
// Build:DAISEN C-Style for TJ3B  [ Ver.20190706 ] - [ Build_V190617 ]
//--------------------------------------------------------------------------------
// SetupVal:111111-111110-000002,cmt:
// CN01:IR_Deg
// CN02:IR_Distance
// CN03:
// CN04:
// CN05:
// CN06:Line
// CN07:Gyro
// CN08:
// CN09:
// CN10:
//--------------------------------------------------------------------------------
#include "D_Main.h"
#include "D_I2C.h"
#include "D_SIO.h"
#include "D_EIO.h"
//--------------------------------------------------------------------------------
// Functions
//--------------------------------------------------------------------------------
void user_sub_1(void);
void user_sub_2(void);
void user_sub_8(void);
void user_sub_11(void);
void user_sub_4(void);
void user_sub_5(void);
void user_sub_6(void);
void user_sub_12(void);
void user_sub_9(void);
void user_sub_10(void);
void user_sub_3(void);
void user_sub_7(void);
void user_sub_13(void);
void user_main(void);
//--------------------------------------------------------------------------------
// Program Name : pid-modoki.C
//--------------------------------------------------------------------------------
void user_sub_1(void)
{
  gV[VAR_A] = gAD[CN7];
  if (gV[VAR_A] > 400) {
    gV[VAR_A] = gV[VAR_A] - 800;
  }
  gV[VAR_A] = gV[VAR_A] / 4;
  if (gV[VAR_A] > 25) {
    gV[VAR_A] = 25;
  } else if (gV[VAR_A] < - 25) {
    gV[VAR_A] = - 25;
  }
  gV[VAR_H] = gV[VAR_W] + gV[VAR_A];
  gV[VAR_I] = gV[VAR_X] - gV[VAR_A];
  gV[VAR_J] = gV[VAR_Y] + gV[VAR_A];
  gV[VAR_K] = gV[VAR_Z] - gV[VAR_A];
}
//--------------------------------------------------------------------------------
// Program Name : front.C
//--------------------------------------------------------------------------------
void user_sub_2(void)
{
  gV[VAR_W] = 20;
  gV[VAR_X] = 20;
  gV[VAR_Y] = 20;
  gV[VAR_Z] = 20;
  gPwm[0] = gV[VAR_H] < 0 ? (gV[VAR_H] * -1) | 0x80 : gV[VAR_H];
  gPwm[1] = gV[VAR_I] < 0 ? (gV[VAR_I] * -1) | 0x80 : gV[VAR_I];
  gPwm[2] = gV[VAR_J] < 0 ? (gV[VAR_J] * -1) | 0x80 : gV[VAR_J];
  gPwm[3] = gV[VAR_K] < 0 ? (gV[VAR_K] * -1) | 0x80 : gV[VAR_K];
  pwm_out();
}
//--------------------------------------------------------------------------------
// Program Name : rightfront.C
//--------------------------------------------------------------------------------
void user_sub_8(void)
{
  gV[VAR_W] = 0;
  gV[VAR_X] = 25;
  gV[VAR_Y] = 25;
  gV[VAR_Z] = 0;
  gPwm[0] = gV[VAR_H] < 0 ? (gV[VAR_H] * -1) | 0x80 : gV[VAR_H];
  gPwm[1] = gV[VAR_I] < 0 ? (gV[VAR_I] * -1) | 0x80 : gV[VAR_I];
  gPwm[2] = gV[VAR_J] < 0 ? (gV[VAR_J] * -1) | 0x80 : gV[VAR_J];
  gPwm[3] = gV[VAR_K] < 0 ? (gV[VAR_K] * -1) | 0x80 : gV[VAR_K];
  pwm_out();
}
//--------------------------------------------------------------------------------
// Program Name : right.C
//--------------------------------------------------------------------------------
void user_sub_11(void)
{
  gV[VAR_W] = - 30;
  gV[VAR_X] = 30;
  gV[VAR_Y] = 30;
  gV[VAR_Z] = - 30;
  gPwm[0] = gV[VAR_H] < 0 ? (gV[VAR_H] * -1) | 0x80 : gV[VAR_H];
  gPwm[1] = gV[VAR_I] < 0 ? (gV[VAR_I] * -1) | 0x80 : gV[VAR_I];
  gPwm[2] = gV[VAR_J] < 0 ? (gV[VAR_J] * -1) | 0x80 : gV[VAR_J];
  gPwm[3] = gV[VAR_K] < 0 ? (gV[VAR_K] * -1) | 0x80 : gV[VAR_K];
  pwm_out();
}
//--------------------------------------------------------------------------------
// Program Name : rightback.C
//--------------------------------------------------------------------------------
void user_sub_4(void)
{
  gV[VAR_W] = - 35;
  gV[VAR_X] = 0;
  gV[VAR_Y] = 0;
  gV[VAR_Z] = - 35;
  gPwm[0] = gV[VAR_H] < 0 ? (gV[VAR_H] * -1) | 0x80 : gV[VAR_H];
  gPwm[1] = gV[VAR_I] < 0 ? (gV[VAR_I] * -1) | 0x80 : gV[VAR_I];
  gPwm[2] = gV[VAR_J] < 0 ? (gV[VAR_J] * -1) | 0x80 : gV[VAR_J];
  gPwm[3] = gV[VAR_K] < 0 ? (gV[VAR_K] * -1) | 0x80 : gV[VAR_K];
  pwm_out();
}
//--------------------------------------------------------------------------------
// Program Name : back.C
//--------------------------------------------------------------------------------
void user_sub_5(void)
{
  gV[VAR_W] = - 25;
  gV[VAR_X] = - 25;
  gV[VAR_Y] = - 25;
  gV[VAR_Z] = - 25;
  gPwm[0] = gV[VAR_H] < 0 ? (gV[VAR_H] * -1) | 0x80 : gV[VAR_H];
  gPwm[1] = gV[VAR_I] < 0 ? (gV[VAR_I] * -1) | 0x80 : gV[VAR_I];
  gPwm[2] = gV[VAR_J] < 0 ? (gV[VAR_J] * -1) | 0x80 : gV[VAR_J];
  gPwm[3] = gV[VAR_K] < 0 ? (gV[VAR_K] * -1) | 0x80 : gV[VAR_K];
  pwm_out();
}
//--------------------------------------------------------------------------------
// Program Name : leftback.C
//--------------------------------------------------------------------------------
void user_sub_6(void)
{
  gV[VAR_W] = 0;
  gV[VAR_X] = - 35;
  gV[VAR_Y] = - 35;
  gV[VAR_Z] = 0;
  gPwm[0] = gV[VAR_H] < 0 ? (gV[VAR_H] * -1) | 0x80 : gV[VAR_H];
  gPwm[1] = gV[VAR_I] < 0 ? (gV[VAR_I] * -1) | 0x80 : gV[VAR_I];
  gPwm[2] = gV[VAR_J] < 0 ? (gV[VAR_J] * -1) | 0x80 : gV[VAR_J];
  gPwm[3] = gV[VAR_K] < 0 ? (gV[VAR_K] * -1) | 0x80 : gV[VAR_K];
  pwm_out();
}
//--------------------------------------------------------------------------------
// Program Name : left.C
//--------------------------------------------------------------------------------
void user_sub_12(void)
{
  gV[VAR_W] = 30;
  gV[VAR_X] = - 30;
  gV[VAR_Y] = - 30;
  gV[VAR_Z] = 30;
  gPwm[0] = gV[VAR_H] < 0 ? (gV[VAR_H] * -1) | 0x80 : gV[VAR_H];
  gPwm[1] = gV[VAR_I] < 0 ? (gV[VAR_I] * -1) | 0x80 : gV[VAR_I];
  gPwm[2] = gV[VAR_J] < 0 ? (gV[VAR_J] * -1) | 0x80 : gV[VAR_J];
  gPwm[3] = gV[VAR_K] < 0 ? (gV[VAR_K] * -1) | 0x80 : gV[VAR_K];
  pwm_out();
}
//--------------------------------------------------------------------------------
// Program Name : leftfront.C
//--------------------------------------------------------------------------------
void user_sub_9(void)
{
  gV[VAR_W] = 25;
  gV[VAR_X] = 0;
  gV[VAR_Y] = 0;
  gV[VAR_Z] = 30;
  gPwm[0] = gV[VAR_H] < 0 ? (gV[VAR_H] * -1) | 0x80 : gV[VAR_H];
  gPwm[1] = gV[VAR_I] < 0 ? (gV[VAR_I] * -1) | 0x80 : gV[VAR_I];
  gPwm[2] = gV[VAR_J] < 0 ? (gV[VAR_J] * -1) | 0x80 : gV[VAR_J];
  gPwm[3] = gV[VAR_K] < 0 ? (gV[VAR_K] * -1) | 0x80 : gV[VAR_K];
  pwm_out();
}
//--------------------------------------------------------------------------------
// Program Name : front_slow.C
//--------------------------------------------------------------------------------
void user_sub_10(void)
{
  gV[VAR_W] = 20;
  gV[VAR_X] = 20;
  gV[VAR_Y] = 20;
  gV[VAR_Z] = 20;
  gPwm[0] = gV[VAR_H] < 0 ? (gV[VAR_H] * -1) | 0x80 : gV[VAR_H];
  gPwm[1] = gV[VAR_I] < 0 ? (gV[VAR_I] * -1) | 0x80 : gV[VAR_I];
  gPwm[2] = gV[VAR_J] < 0 ? (gV[VAR_J] * -1) | 0x80 : gV[VAR_J];
  gPwm[3] = gV[VAR_K] < 0 ? (gV[VAR_K] * -1) | 0x80 : gV[VAR_K];
  pwm_out();
}
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

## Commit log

2022-04-20 Initial Commit
    最初のコミットです。
    各ファイルを追加。
    [New-Robo-Achevement-April.xlsx]
2022-04-20 進捗追加
    githubリポジトリを作成
    [New-Robo-Achevement-April.xlsx]
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2022-04-21 Revert "フレーム 現状 Artemis機"
    This reverts commit 175b8af8b3617812aba4bc7054874700fb0bbe0f.
    [a v5.f3d]
2022-04-27 DSR1202用のライブラリ追加
    https://github.com/anbara/DSR-1202 より引用
    [New-Robo-Achevement-April.xlsx]
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2022-05-03 MPU6050用のジャイロファイルをリターン・ファイル整理
    MPU6050用のプログラムを保存しておきます
    あとファイルをまとめておきました。
    [XiaoWithL3GD20h.kicad_pcb, XiaoWithL3GD20h.kicad_sch]
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2022-06-01 部品ごとのデータファイルの追加
    マイコンのシンボル、基板のデータ保存用のファイル等の追加
    [TJ3B.kicad_pcb, TJ3B.kicad_sch, TJ3B.sch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]
2022-06-01 omuniのCADデータの追加
    各部品のデータの追加
    ３Dプリンター用のデータにも変換済み
    [a v5.f3d, artemis omni 上 v1.f3d, artemis omni 上 v1.stl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]
2022-06-07 KiCadの各プロジェクトの追加
    各シンボルのライブラリ・プロジェクトの追加
    [New-Robo-Achevement-April.xlsx, TJ3B.kicad_pcb, TJ3B.kicad_sch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]
2022-06-07 シンボルライブラリのパス指定を絶対パスから相対パスへ変更。
    環境によってプロジェクトの配置階層が変わるのでプロジェクトから見た相対パスへ変更。
    ${KIPRJMOD}/../Lib/(project_name)
    で指定可能なのでこれからはそうすること。
    [main board.kicad_sch]
2022-06-07 メイン基板の更新
    IRセンサー等のセンサー追加、配線追加。
    [main board.kicad_sch]
2022-06-08 メイン基板の更新
    IRセンサの配線変更等
    [main board.kicad_sch]
2022-06-09 メイン基板の更新
    内容は知らないです
    [main board.kicad_sch]
2022-06-09 基板の更新
    メイン基板の更新、ライブラリの追加
    ※電源基盤はいまだ理解できずに手が付けられてない。
    [main board.kicad_sch]
2022-06-12 基板データの更新
    メイン基板、電源基盤のデータ更新
    回路が正しいか答え合わせするもんなくで困ってる。ダレカタスケテ
    [psu_board.kicad_pcb, psu_board.kicad_sch]
2022-06-13 基板データの更新
    電源回路の更新、ライブラリの追加
    やっと回路理解してきた！
    [psu_board.kicad_sch]
2022-06-14 基板データの更新
    電源基盤の更新、フットプリントの割り当て中
    [psu_board.kicad_sch]
2022-06-17 基盤データの更新
    電源基盤のフットプリントの割り当て完了
    配線開始。
    [psu_board.kicad_pcb, psu_board.kicad_sch]
2022-06-20 基盤データの更新
    フットプリントの更新、電源基盤の部品の配置
    [psu_board.kicad_pcb, psu_board.kicad_sch]
2022-06-22 電源基盤の更新
    基盤の外形のインポート、部品の配置。
    [IO基板 v1.dxf, io_board.kicad_pcb, io_board.kicad_sch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]
2022-06-24 基盤データの更新
    電源基盤、IOボードの配線更新。
    [IO基板 v1.dxf, io_board.kicad_pcb, io_board.kicad_sch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]
2022-06-24 基盤データの更新
    メイン基板の回路図の更新
    [main board.kicad_sch]
2022-06-29 基盤データのアップデート
    ローカルコミットはちゃんと作ってください
    [io_board.kicad_pcb, line_sensor.kicad_pcb, line_sensor.kicad_sch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]
2022-06-29 基板データの更新
    ラインセンサーの完成
    Arduino メイン基板の作成、製作開始。
    [line_sensor.kicad_pcb, line_sensor.kicad_sch, main board.kicad_sch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]
2022-06-30 基板データの更新
    IO基板、ライン基板、電源基盤のコネクタ変更、最終確認
    メイン基板制作中。
    [io_board.kicad_pcb, line_sensor.kicad_pcb, line_sensor.kicad_sch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]
2022-07-01 基板データの更新
    メイン基板の製作
    [main board.kicad_pcb, メイン基板 .dxf]
2022-07-02 基板データの更新
    メイン基板の部品配置まででけた
    [line_sensor.kicad_pcb, main board.kicad_pcb, main board.kicad_sch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]
2022-07-03 AE-BNO055-BO専用のプロジェクト追加
    [Gyro_AE-BNO055-BO.kicad_pcb, Gyro_AE-BNO055-BO.kicad_sch]
2022-07-10 基板データの更新
    最後に更新してからのデータ全てです。
    [io_board-B_Cu.gbr, io_board-B_Mask.gbr, io_board-B_Paste.gbr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]
2022-07-10 基板データの更新
    今日変更した分
    メイン基板
    [main board-B_Cu.gbr, main board-B_Mask.gbr, main board-B_Silkscreen.gbr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]
2022-07-11 基板データの更新
    最新バージョンの発注データの作成
    最新バージョンの発注。
    [main board-B_Cu.gbr, main board-B_Mask.gbr, main board-B_Silkscreen.gbr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]
2022-07-13 基板データの更新
    メイン基板データの更新
    [main_board_Arduino.kicad_sch]
2022-07-18 基板データの更新
    IO基板のCNCバージョン作成
    [io_board for cnc.kicad_pcb, io_board for cnc.kicad_sch, main board.kicad_sch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]
2022-07-18 基板データの更新
    IO基板
    [io_board for cnc.kicad_pcb]
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2022-07-18 基板データの更新
    新メイン基板の回路図の作成。
    [main board new.kicad_pcb, main board new.kicad_sch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]
2022-07-18 Revert "Merge branch 'main' of https://github.com/MUNAKATA-EPC/Munachu_Artemis"
    This reverts commit 2d62b7fa3f437b1c22d560bdfdc29bbce9a662c6, reversing
    changes made to e44e47092be221c5dedf368005a17df58de841e6.
    [main.c, main.cpp]
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2022-07-24 Dual core TJ3B ファイルの作成
    ただいまスレーブを用いた20ポートTJ3Bの製作中です。
    今、回路設計中。
    [Dual core tj3b.kicad_pcb, Dual core tj3b.kicad_sch]
2022-07-27 基板データの更新
    新メイン基板あたりをいじった
    [main board new.kicad_sch]
2022-07-28 部内大会用プログラムの作成
    部内大会というか、北九州オープンくらいまでのプログラムが入ってます。
    カメラ・IR_ring・Line_ringの制御。
    [io_board for cnc.kicad_pcb, io_board for cnc.kicad_sch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]
2022-07-28 基板データの更新
    いろいろいじったものの更新です。
    MD用のファイルの追加もしました。
    [Motor_Driver.kicad_pcb, Motor_Driver.kicad_sch, io_board.step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]
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2022-07-31 部品の３Dデータのアップロード
    Designファイルの追加
    各部品用のファイル・データの追加
    [100mmスペーサー .f3d, 10mmスペーサー .f3d, 15mmスペーサー .f3d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]
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2022-08-08 ジャイロセンサのプログラム修正
    kitakore
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2022-08-10 参考資料用ファイル追加
    ロボット、CAD、プログラムについてなどのPDFなどの参考資料を保存するファイルの追加。
    自由にファイルを作って追加してください。
    写真なども可
    [main_board_Arduino.kicad_pcb, main_board_Arduino.kicad_sch]
2022-08-12 基板データの更新
    新メイン基板のデータの更新
    [main board new.kicad_sch, neo_pixel.kicad_pcb, neo_pixel.kicad_sch]
2022-08-12 基板データの更新
    新メイン基板の更新
    [io_board for cnc-B_Cu.gbr, io_board for cnc-B_Mask.gbr, io_board for cnc-B_Paste.gbr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]
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2022-08-28 CADデータの追加、更新
    各基盤のファイル、データの追加
    Fusion360の新ロボの設計のデータ追加
    [100mmスペーサー .f3d, 10mmスペーサー .f3d, 15mmスペーサー .f3d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]
2022-10-13 ロボットのハード関係のデータ更新
    今までため込んでた３Dデータ、基板データの更新です。
    Teensy機の基板があと少しですべて終わる
    [AT-B_Cu.gbl, AT-B_Mask.gbs, AT-B_SilkS.gbo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]
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2022-12-06 ハードのデータ更新
    いろいろたまって申し訳ない
    ハード全般のデータ更新です。
    ついでに、2023シーズン用のプレゼンシートも上げときます。（未完成）
    [5mm スペーサー v2.stl, 5mm スペーサー.f3d, 5mm スペーサー.stl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]
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2022-12-10 フォルダ名変更
    これでわかりやすいはず！
    [所持者リスト .xlsx]
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2023-02-27 基板データの更新
    1318のファイルがたまってました
    多くなって申し訳ない
    [AT-B_Cu.gbl, AT-B_Mask.gbs, AT-B_SilkS.gbo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]
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
